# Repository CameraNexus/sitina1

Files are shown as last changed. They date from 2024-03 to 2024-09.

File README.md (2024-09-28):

# Sitina 1

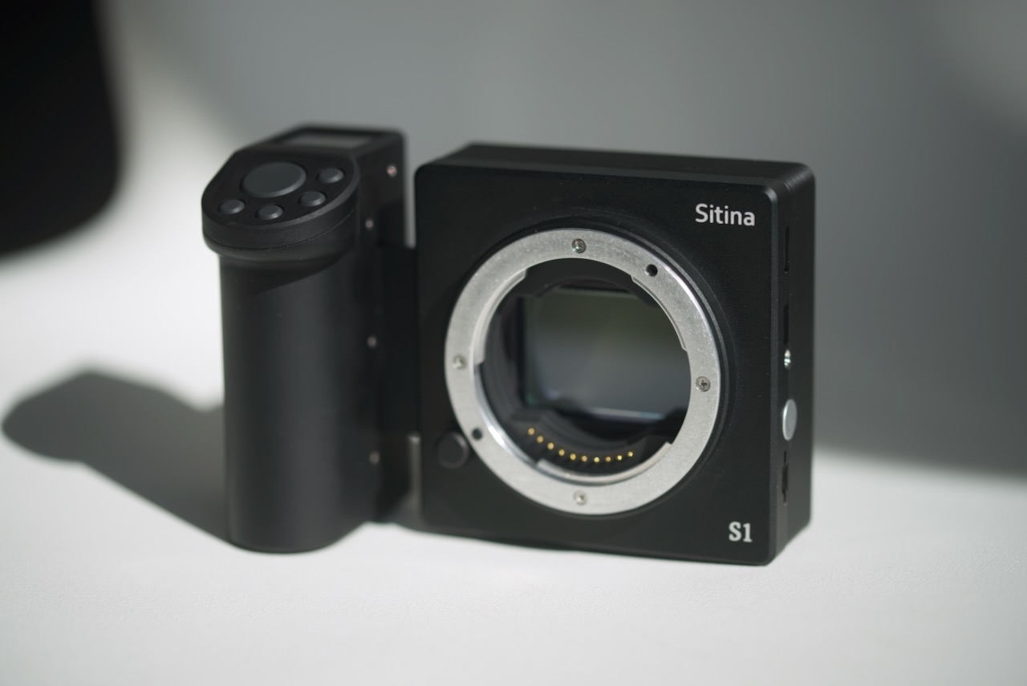
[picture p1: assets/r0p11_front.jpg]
front


Open-source 35mm full-frame (36mm x 24mm) CCD mirror-less interchangable lens camera (MILC). The original goal of this project was to create a digital camera back to convert SLR cameras to DSLR cameras, but has since changed to build a full MILC.

I have made 2 videos about this project:

- First video in 2023 (r0.6 hardware): [https://www.youtube.com/watch?v=Ma9FrN5COIo](https://www.youtube.com/watch?v=Ma9FrN5COIo)
- Second video in 2024 (r0.11-B hardware): [https://www.youtube.com/watch?v=OkfzjmY9cF8](https://www.youtube.com/watch?v=OkfzjmY9cF8)

Join discussion if you wish: [https://discord.gg/2zAJycbpU5](https://discord.gg/2zAJycbpU5)

## Specifications

The following are preliminary.

### Hardware

- SoC: Xilinx Zynq 7010 (2x667MHz Cortex-A9, 28K logic cells FPGA)
- RAM: 512MB 16-bit DDR3 SDRAM
- AFE: Analog Devices AD9990
- Sensor: Kodak/ONsemi KAI-11000/KAI-11002M/CM
- Screen: 3.4" 480x480 High-Brightness DPI IPS LCD
- External Ports:
  - SD slot (HS, 25MB/s)
  - USB Type-C (5V3A power supply)
  - Flash sync terminal

### Camera Features

The following are possible with hardware, but not necessarily supported by the current software.

- Sensor Type: 35mm Interline CCD sensor
- Sensor Size: 36.0 x 24.0 mm
- Effective Pixels: 10.7MP
- Lens Mount: Active E mount
- Still Resolutions:
  - 4008x2672 10.7MP 3:2
  - 3563x2672 9.5MP 4:3 1.08X crop
  - 2672x2672 7.1MP 1:1 1.27X crop
  - 2782x1856 5.2MP 3:2 APS-C crop
  - 2676x2007 5.4MP 4:3 APS-C crop
  - 2365x2365 5.6MP 1:1 APS-C crop
- Still Format:
  - DNG (10/12/14-bit lossless compressed RAW)
  - JPEG
- Readout Speed:
  - 4008x2672 up to 5FPS
  - 4008x480 at 28FPS (line skipping live view, rescaled to 480x320 for output)
- Video recording is not supported
- ISO: 100 to 6400 (color version)

## Status

Hardware R0.11 tested and working. The hardware still need a lot of work and is not ready yet.

## Sample Photos

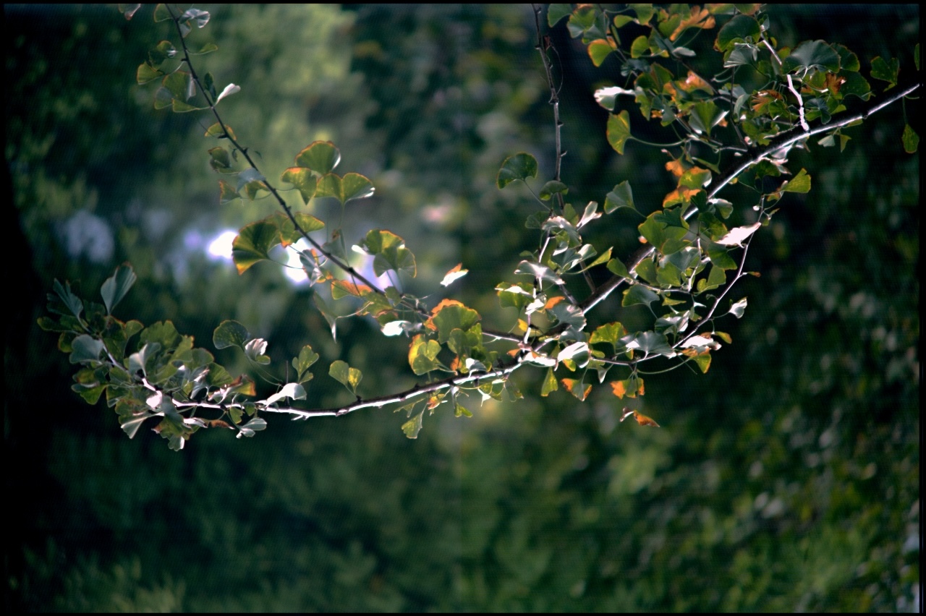
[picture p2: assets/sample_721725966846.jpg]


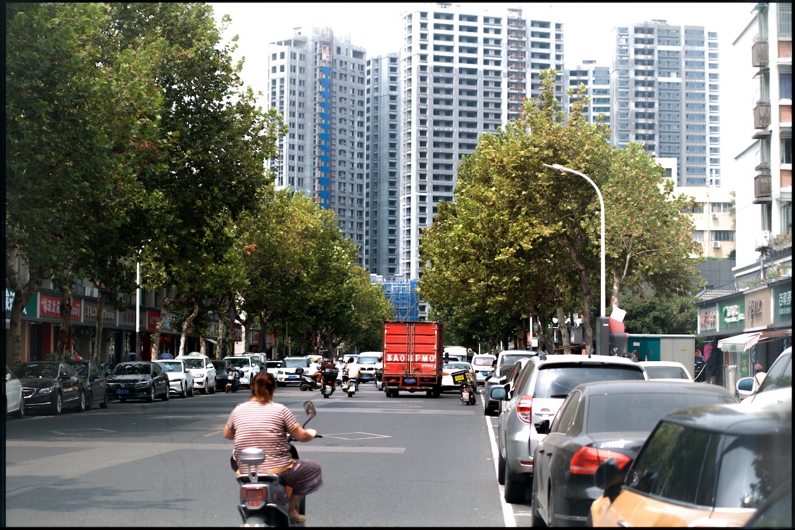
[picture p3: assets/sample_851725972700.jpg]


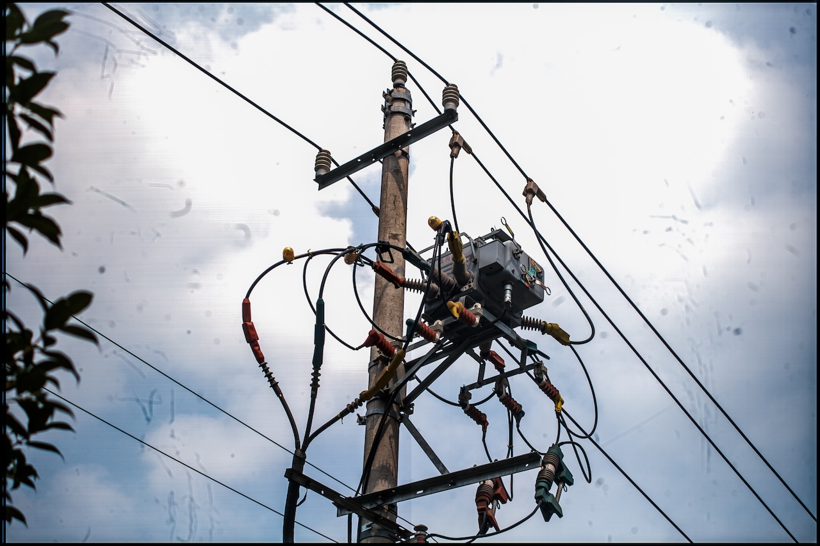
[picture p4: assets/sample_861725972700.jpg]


## Revision History

See [old-versions.md](/OLD_VERSIONS.md) for change logs, stories, and photos of old revisions!

## License

Unless otherwise stated, the hardware design is released under CERN-OHL-P, and the software/ firmware are released under MIT.

Most other 3D models are obtained from vendor website, refer to the corresponding vendor website for licensing details. They are provided for convience only.

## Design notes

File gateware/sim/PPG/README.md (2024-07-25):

# Programmable Pulse Generator (PPG) Demo

This folder contains a simple iVerilog testbench for the Adiabatic V-Driver-Driver.
The parameters are configured to the default value at 336MHz clock.

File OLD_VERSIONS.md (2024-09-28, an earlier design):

# Old Versions

Page for documenting old versions of this project. What happened, what worked, what didn't, etc.

### Rev 0.1 - Dec 2017

Initial revision. I had the idea of building a camera late 2016. The initial name of the project was called "F3 Digital" and it was based around the KAI-16000 sensor. As you might have guessed from the name F3 Digital, it's actually about turning the famous Nikon F3 film SLR camera into a DSLR. I was not prepared for the project tbh. There are too many challenges. Back in 2016 I actually had no ideas about how these things worked, I know basically nothing about circuit design, power electronics, programming, mechanical engineering or anything. Plus I didn't have a job back then I had no income to actually support me continue the project. So it basically went nowhere. I was quite frustrated back then to a point I put all my electronics DIY projects to a halt until I feel like I have learned enough things to restart.

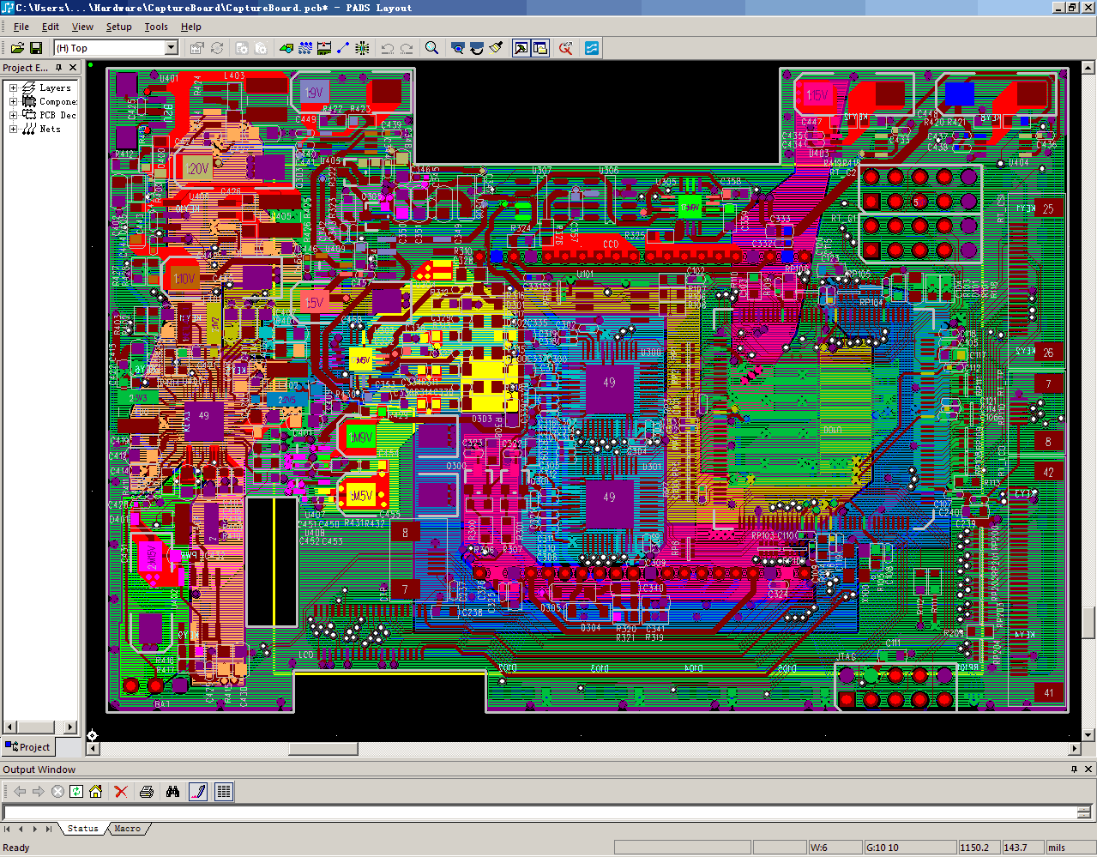
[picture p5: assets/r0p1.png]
r0p1


The half assembled prototype:

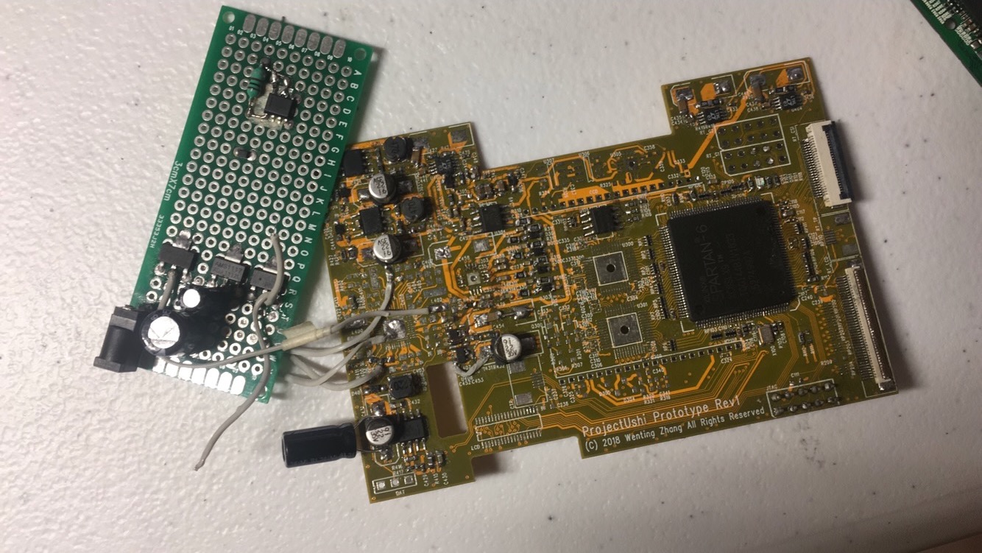
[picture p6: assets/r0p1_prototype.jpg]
r0p1_prototype


One major bug killed it is I made the footprint of the ADC mirrored.

Main hardware specs for this failed attempt:

- MCU: iMXRT1052
- FPGA: Spartan6 LX9
- CCD: KAI-16000
- ADC: AD9824

### Rev 0.2 - Mar 2021

Fast forward to 2021, one day when I was browsing eBay I saw someone selling bunch of KAI-11000 sensors at a very low price. I thought it's time to restart the project, even though I wasn't sure if I am ready or not. I was clearly not. I encountered three main challenges during the design process

- Integrating with the Nikon F3
- Driving the high capacitance clock lines
- Using the ADI AFE chip

Let's talk through them.

The first challenge is on the circuit design. CCD sensor signal lines are huge capacitive loads to the driver, yet they demand fast rise and fall times. The voltage also differs from different signals. For example, some are 5V swing around 3V, some are 9V swing around -4V. This would also require designing voltage shifters that not only change the amplitude, but also change the ground reference point. Then finally these circuits need power supplies to provide 10s of different voltage rails, sitting right next to sensitive analog circuits.

The second challenge is using the ADI AFE chip. The AFE chip integrates in a timing generator for the CCD, at first I thought it would be a good idea to just use that to generate all the timings for the CCD. This unfortunately turned out to be much harder than I anticipated. The timing generator is extremely flexible, supporting all sort of different things you may want to do with the CCD. Often there are multiple ways to program it to achieve the same output. The bad part? It has got hundreds of registers to control the behavior of the generator, and one has to be really familiar with its architecture and the intended output to be able to program it correctly. I didn't find any example code, I also had no prior experience with CCD so I wasn't even sure what kind of signal output I should be looking for. So this part ended up becoming challenging as well.

The third challenge is about integrating everything nicely with the F3 camera itself. However, attacking multiple challenges myself at the same time is just not a good strategy. I decided to focus on 1 and 2 first, trying to getting a working image capturing device before turning it into a camera.

This revision introduces the following major changes:

1. Use AD9990 for ADC/ AFE/ TG
2. Remove FPGA
3. Use KAI-11000 instead of KAI-16000
4. Redesigned H/V driver
5. Use 2.8" 640x480 LCD

This reversion continued the diversion between a sensor board and a processor board:

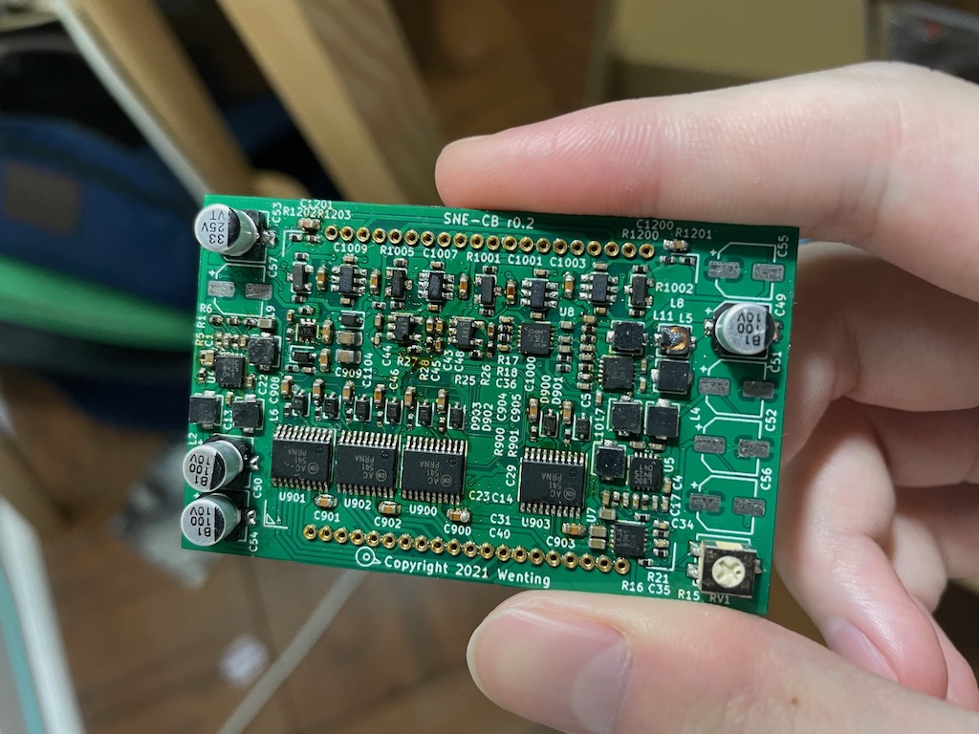
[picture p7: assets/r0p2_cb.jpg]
r0p2_cb


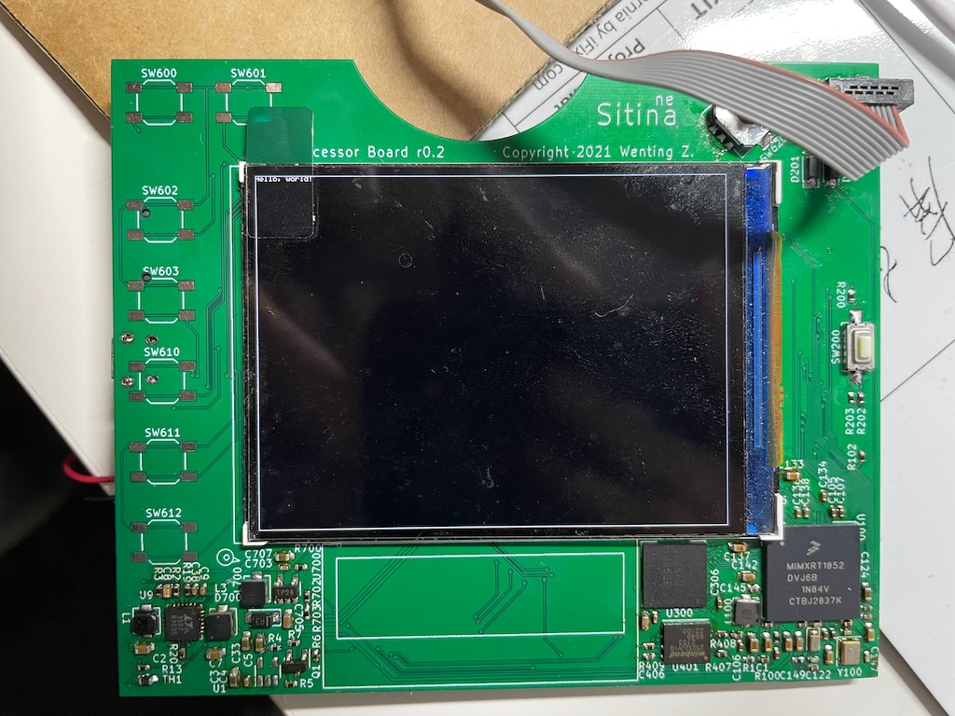
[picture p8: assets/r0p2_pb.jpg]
r0p2_pb


### Rev 0.3 - Dec 2021

This revision included minor bug fixes, but only to reveal bigger issues.

1. Fix AD9990 TEST pin connection
2. Minor bug fixes for driver
3. Fix RT1052 integrated DCDC connection

### Rev 0.4 - Mar 2022

With this revision I decided to make it more like a dev board rather than a camera board. This enables easy access to all the signals for hooking up an oscillioscope or logic analyzer.

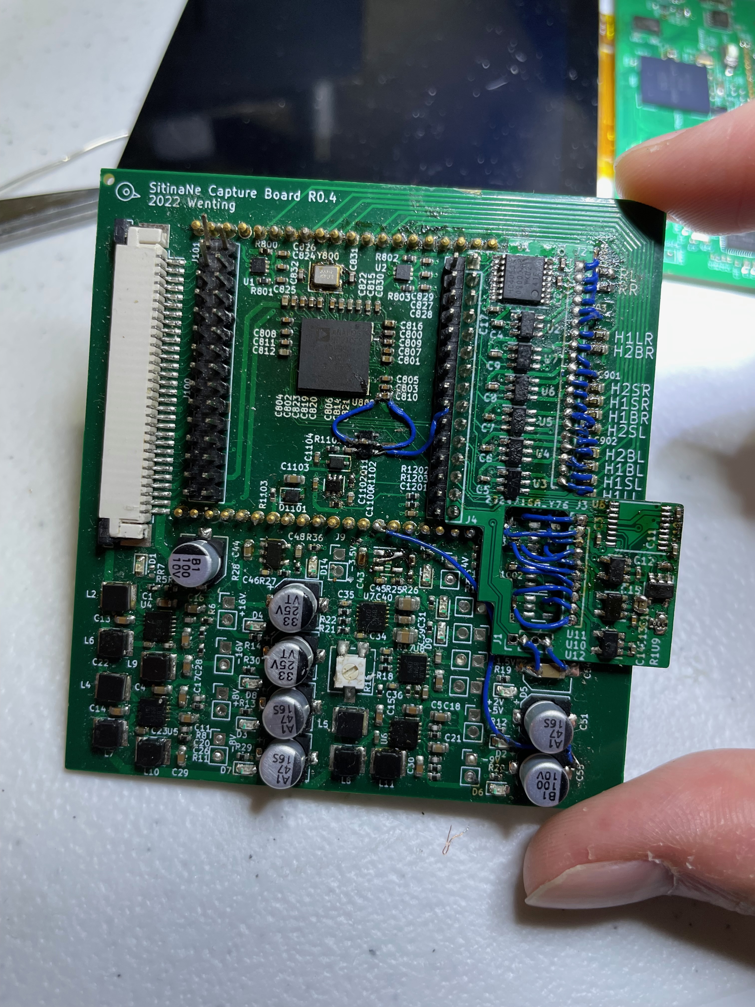
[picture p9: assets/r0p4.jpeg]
r0p4


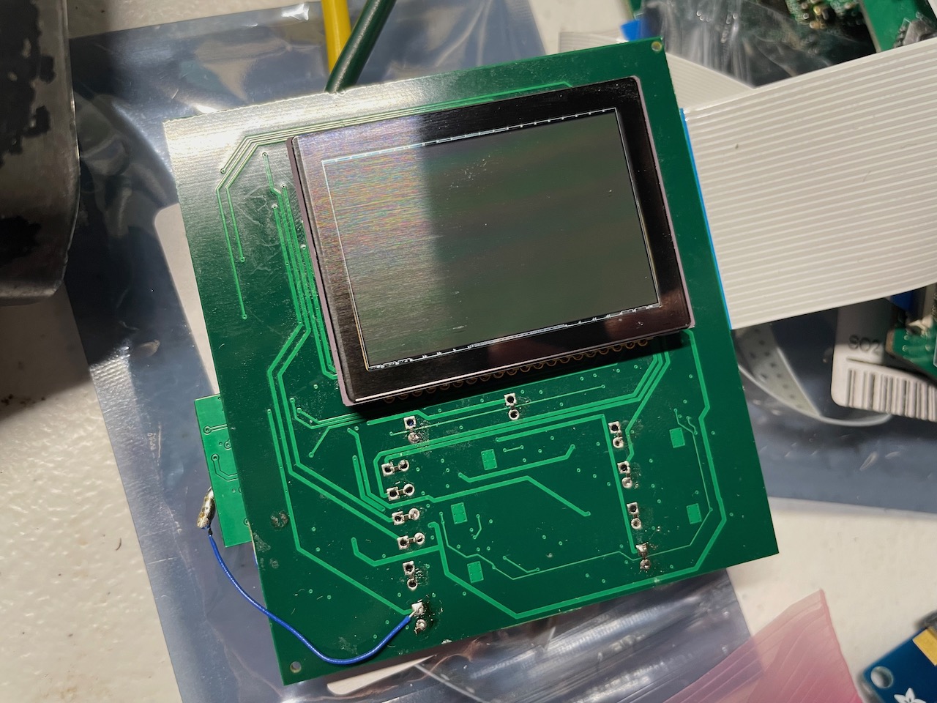
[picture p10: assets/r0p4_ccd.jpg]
r0p4_ccd


Notably this is the first time ever I got the CCD working: https://x.com/zephray_wenting/status/1519542527040401408.

### Rev 0.5 - Apr 2022

At this point I more or less have a somewhat working image capturing device, it's time to think about the F3 camera integration issue itself. This is not a single issue, but multiple issues:

1. because there is a thick protective glass in the front of the sensor, when the sensor is installed at the place where normally film goes to, the flange focal distance is increased. This changes the range of the distance which the lens can focus on. While this may not be a big deal, this problem doesn't have a clean solution.
2. the Nikon F3 exposes limited information to the external world. While it's internal electronics knows the ISO settings, the shutter speed dial, there is no easy way to access these. Disassembling the camera to add wires is possible but quite hard.  Otherwise I am stuck with the signal available to the official motor drive (which only has shutter release and shutter close).
3. How do I even attach this thing to the camera? The mechanism to hold the original film compartment door might simply not be strong enough the hold all the stuff I am adding. There is no place to put any reasonably sized battery (even though it might sounds like you can put a big battery in place of the film roll, don't forget there will be a film rewind fork sticking into the middle of the compartment. You don't want that to punch into the battery pack.) Making it like a grip and screw into the camera like the official motor drive was the only viable option I could come up with.

Eventually I think all of these are resolvable, it just takes time. So I started designing a basic chassis for it. My initial idea is to make it look like the Instax SQ1. Though the final design deviated away from it. But the idea of using a square LCD screen lived on.

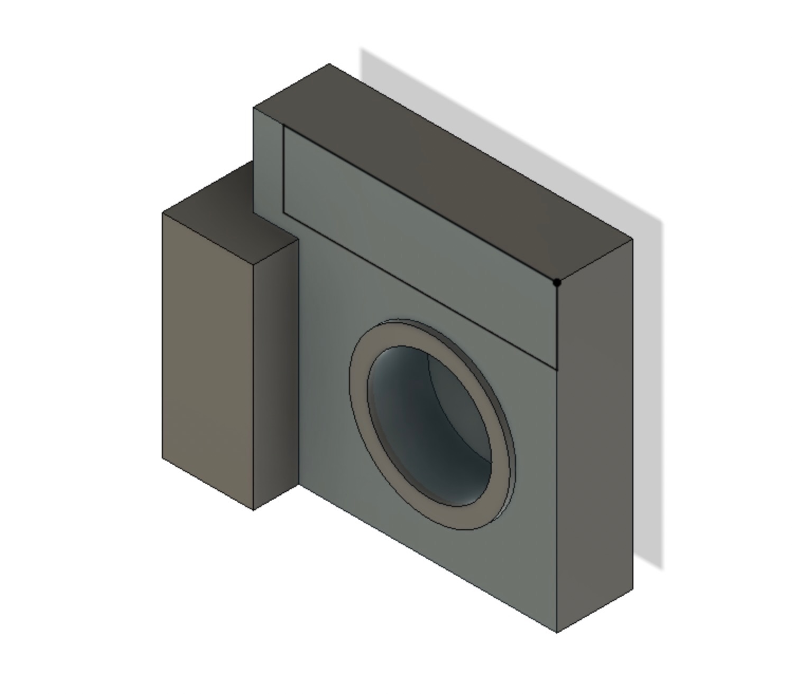
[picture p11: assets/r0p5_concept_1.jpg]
r0p5_concept


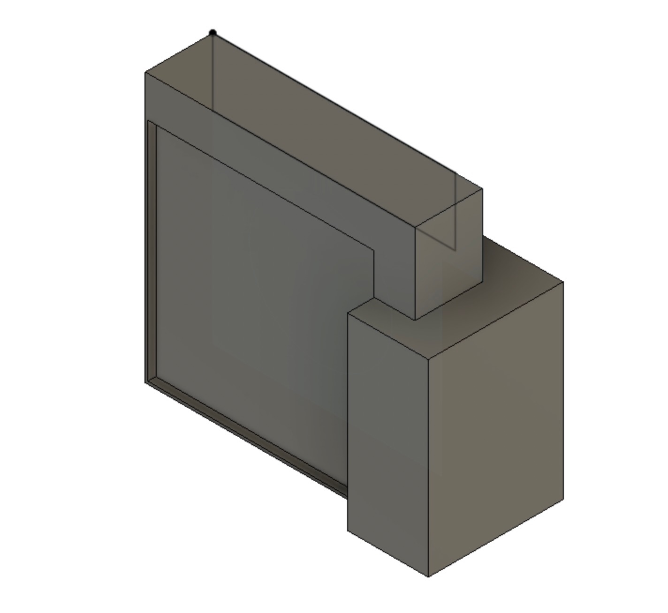
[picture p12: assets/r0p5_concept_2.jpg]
r0p5_concept


To help simplify the overall construction, the sensor board + processor 2-board design has been merged into a single-board design.

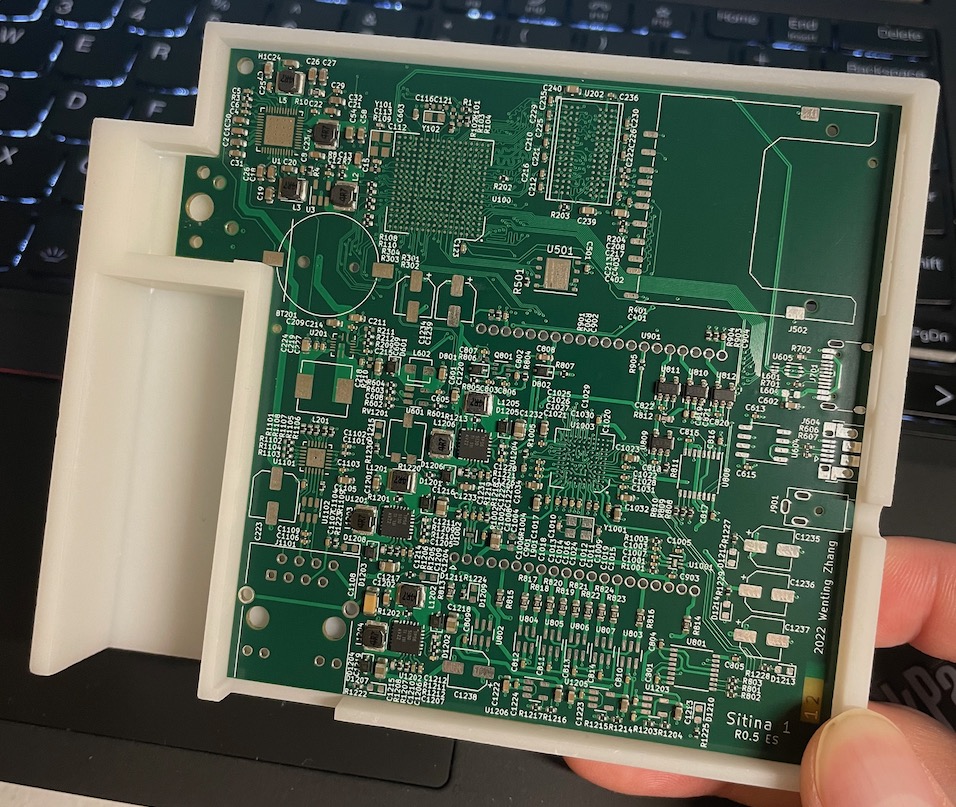
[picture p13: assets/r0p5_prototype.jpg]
r0p5_prototype


Main changes for this revision:

1. Switch from iMXRT1052 to iMX6ULL
2. Use 4" 720x720 LCD instead
3. Add 100M ethernet
4. Redesigned CCD power supply
5. Bug fixes for driver level-shifter

### Rev 0.6 - Mar 2023

Turns out I get more impatient as time goes by. At this point I have been quite frustrated and don't want to deal with this project anymore. I don't even want to deal with Linux. So I again switched to use a microcontroller. And made a video about whatever I was able to get out of it, hoping this would be the end of this project. I mean it's a crappy design and crappy camera, but it does take pictures.

Photos I took during debugging:

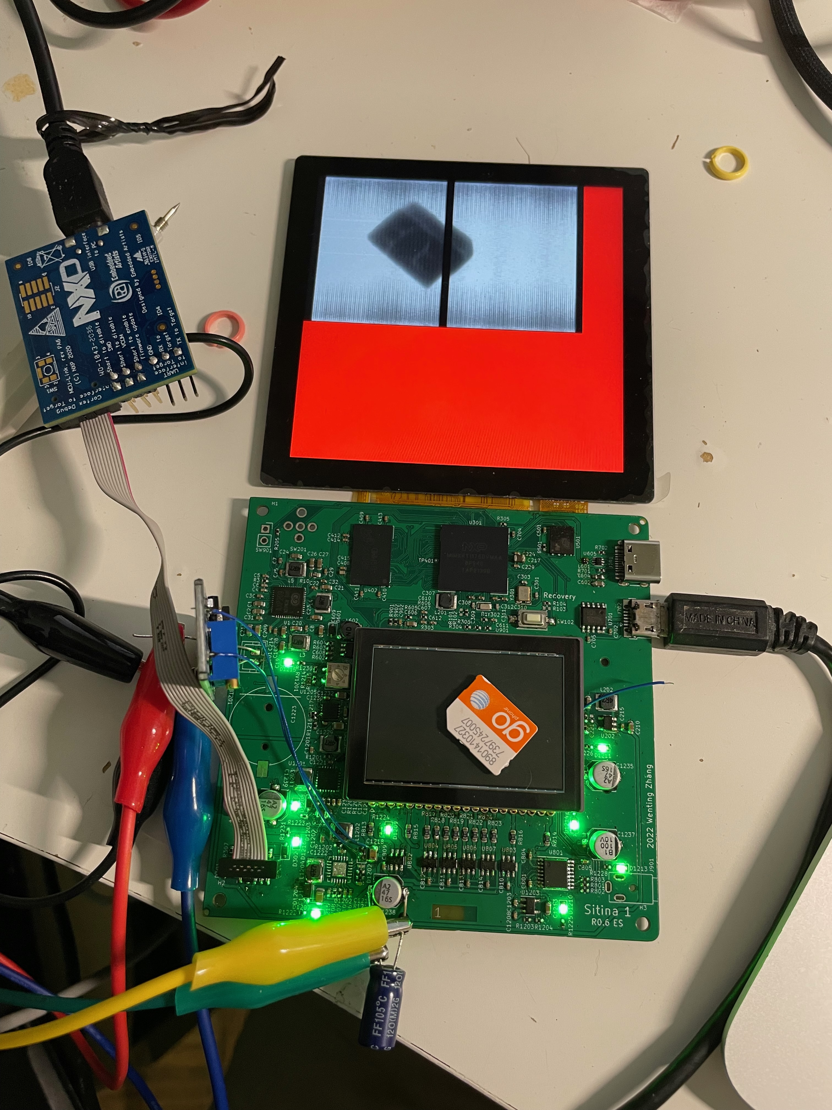
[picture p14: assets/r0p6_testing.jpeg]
r0p6_testing


Main changes:

1. Switch from iMX6ULL to iMXRT1176
2. Shrink board size
3. Removed builtin ethernet
4. CCD power supply bug fixes
5. Use MIPI DSI LCD instead of DPI

### Rev 0.7 - Aug 2023

Turned out the video went quite popular, getting 300K views on Bilibili and YouTube combined. To a point where don't want to claim that that questionable camera is the best I can do. So I continued.

I have several complains about the previous design:

- Bad image quality
- Problematic power supply design (noise issues, unable to supply current needed by the inefficient clock line driver)
- Problematic clock line driver (no slew control, ramp too slow, inefficient)
- Basically impossible to calibrate/ adjust the distance/ flatness between lens and sensor
- No builtin IR cut filter
- Too big
- Grip feels bad
- Full touchscreen operation is a bad idea and I knew it
- Only support fully manual lenses
- LCD is a bit hard to see outside

To address these issues I started designing the new version. I start with the basic idea of fastening both the sensor and the lens onto one metal part (instead of on 2 different plastic parts):

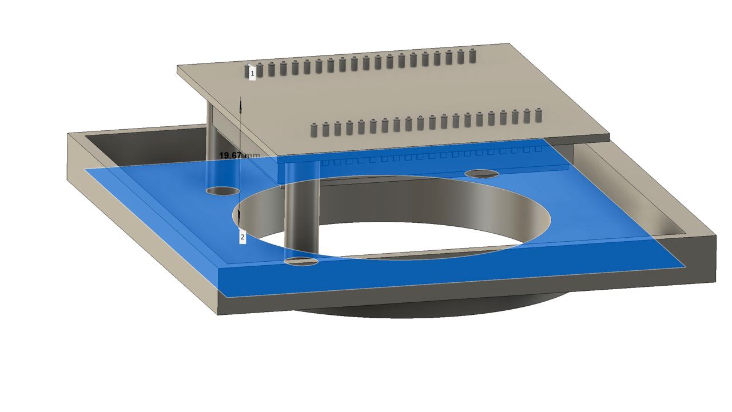
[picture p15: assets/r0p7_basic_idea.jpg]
r0p7_basic_idea


To help with miniaturize the camera, the screen size has shrunk from 4.0" down to 3.4". The new screen also has a 1000 nits maximum brightness, which should help with outdoor visibility a bit. This would also mean it's no longer possible to fit all components on a single PCB due to 2 reasons:

- I don't want to assert any external force on the sensor board, so all the IO ports and buttons should reside on another board
- It just doesn't fit

A common solution is to just stack more boards on the back side of the camera. Many industrial and consumer camera do this. I mean this is a pretty reasonable design. For me though, I want to try something different. To keep the camera thin, I want to stack more board in the front side, so I don't add additional thickness other than the bulky CCD sensor, the long pin + connector, and the thick high brightness backlight module. The only downside is that it would need to have a big cutout in the middle:

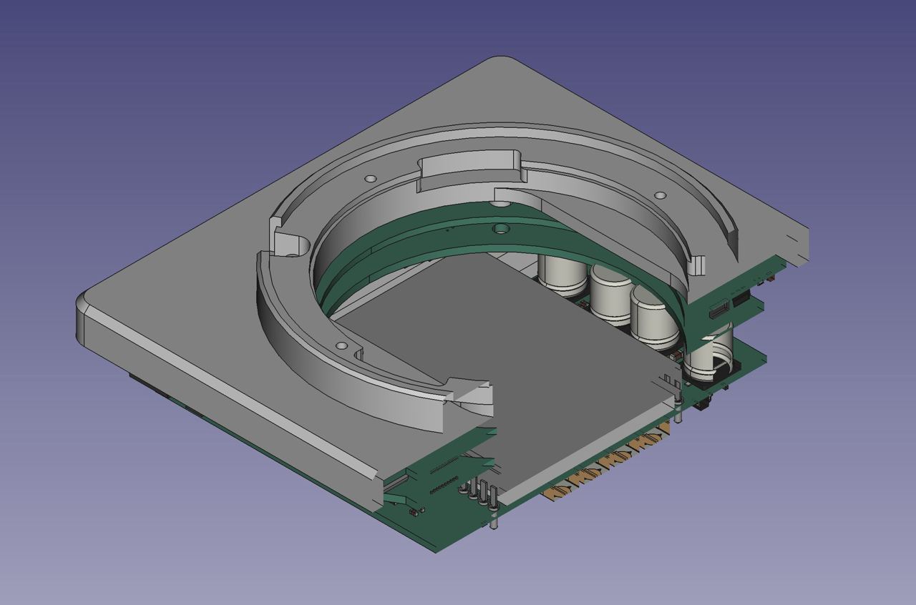
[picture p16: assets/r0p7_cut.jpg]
r0p7_cut


The rest of the design basically follows on. I again decided to focus on the image capturing part itself and worry about the grip later. I did model up the grip so I think it would fit. The final design looks like this (note how the grip is just a mock-up):

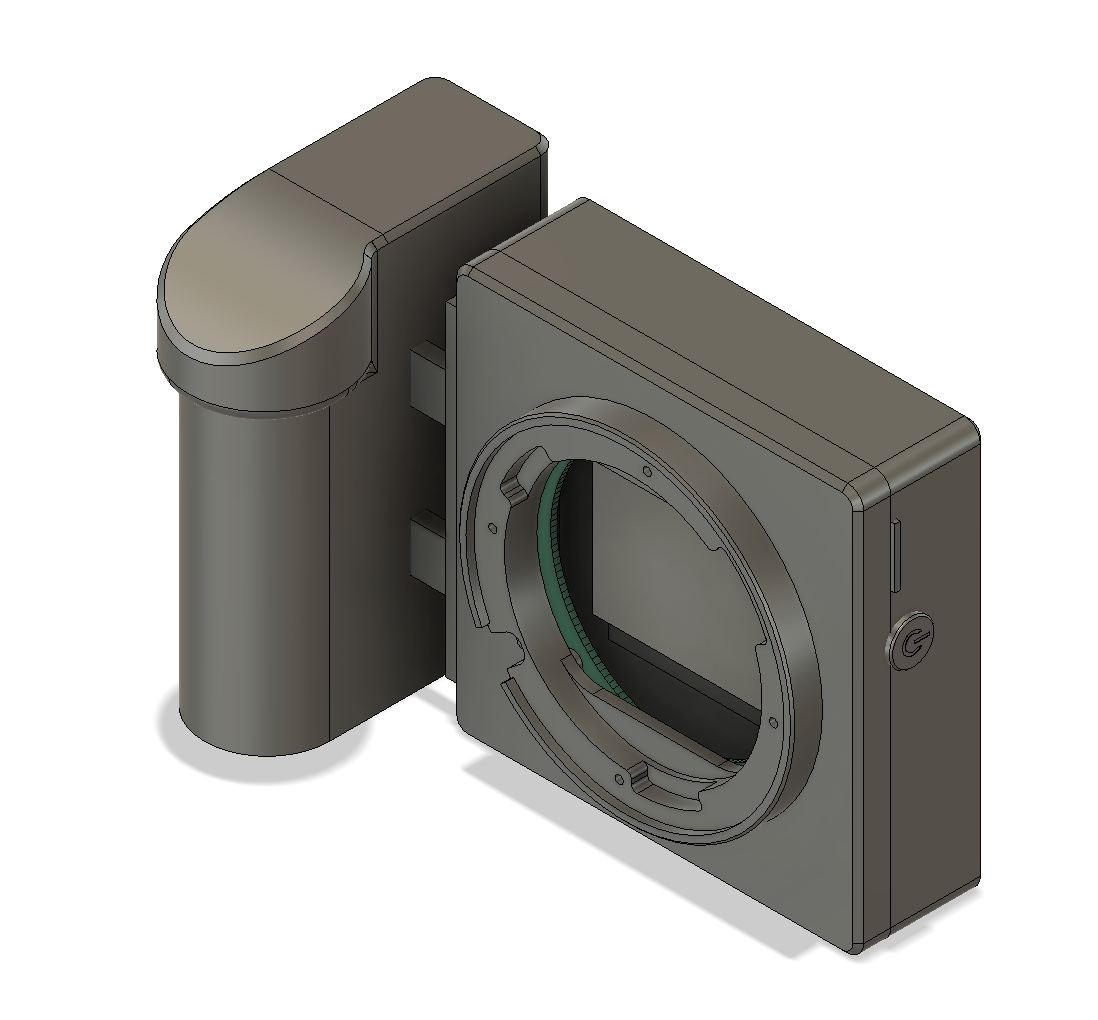
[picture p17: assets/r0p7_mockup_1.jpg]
r0p7_mockup_1


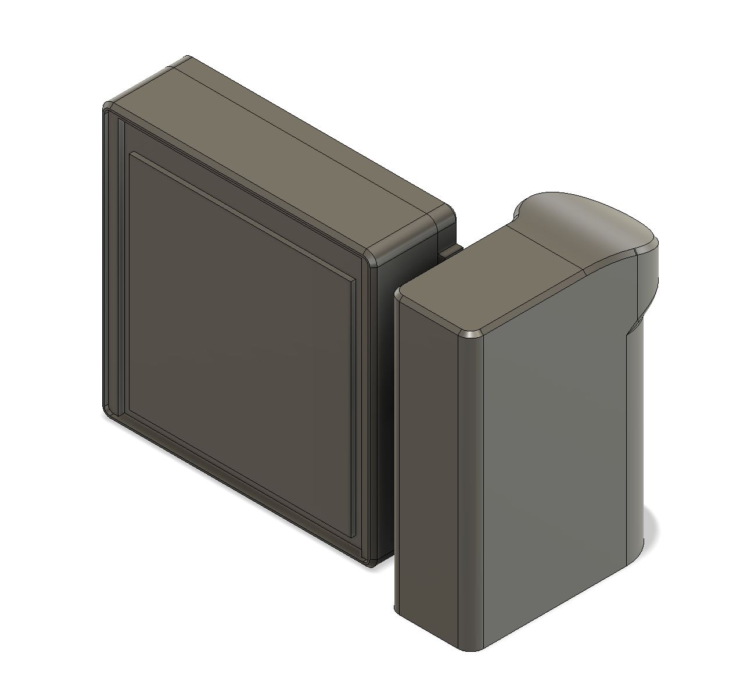
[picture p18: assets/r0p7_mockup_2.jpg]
r0p7_mockup_2


I went ahead and ordered the board and got it soldered and did some initial testing, and found some quite stupid issues preventing it from working.

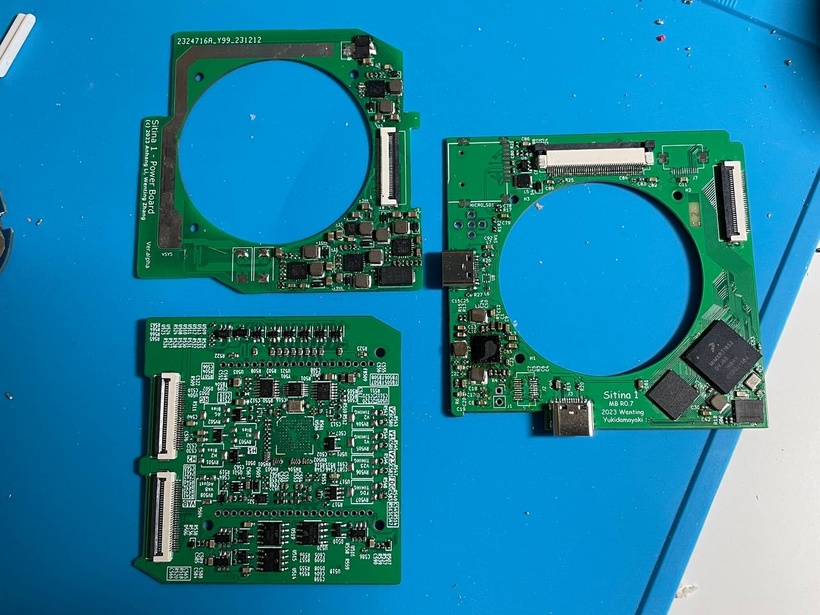
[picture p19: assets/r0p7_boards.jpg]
r0p7_boards


Main changes compared to r0p6:

1. Switch back to iMXRT1052
2. New board shape and overall design
3. Use 3.4" LCD instead of 4"
4. Split into 3 boards (MB, PB, SB)
5. Use individual MOSFETs for V-drivers

### Rev 0.8 - Jan 2024

My original plan back in December for r0.7 is to have the main body of the camera up and running and then worry about the grip later. That didn't quite work out: there were bugs in the boards, and I forgot to order some components, etc. Moreover, as I am designing the grip, it's becoming clear that I need to make the main body a few mm larger than previously designed in December (it's still going to be smaller than the previous revision though.) So I need to do a re-spin of everything anyway. As a result I have been focusing on getting the design right rather than trying to bring up the old prototypes.

I also spent some time to fix my broken 3D printer so it's up and running again (though with questionable printing quality) so I can print models of the grip to make sure the feeling isn't absolutely garbage:

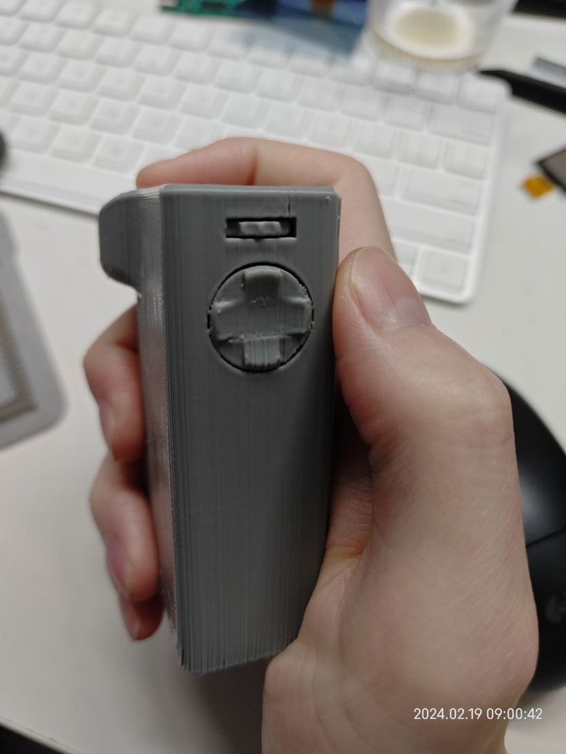
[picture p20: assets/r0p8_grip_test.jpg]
r0p8_grip_test


One major change I did is adding pogo pins for the lens. In the past the lens mount has been passive, meaning it only work with fully manual lenses. This obviously requires putting down these pins on to the board, so I am no longer able to keep the round cutout (which I like a lot):

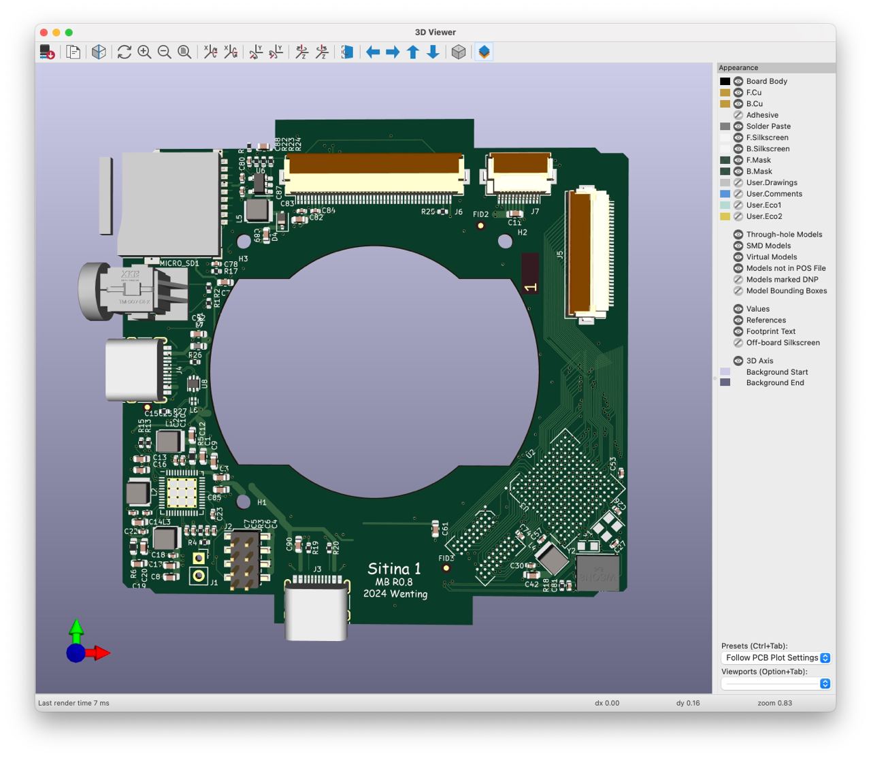
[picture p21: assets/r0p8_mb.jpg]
r0p8_mb


While the mainboard has a smaller cutout, the power board's cut out has been enlarged. This is accomodate the holder for the IR cut filter lens.

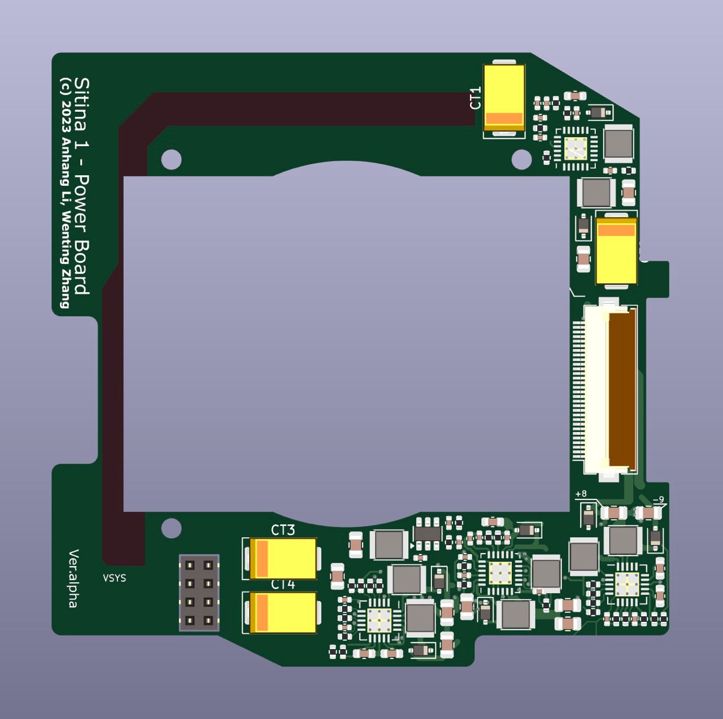
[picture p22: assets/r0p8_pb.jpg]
r0p8_pb


After printing a model of the full camera, this revision is almost ready to go:

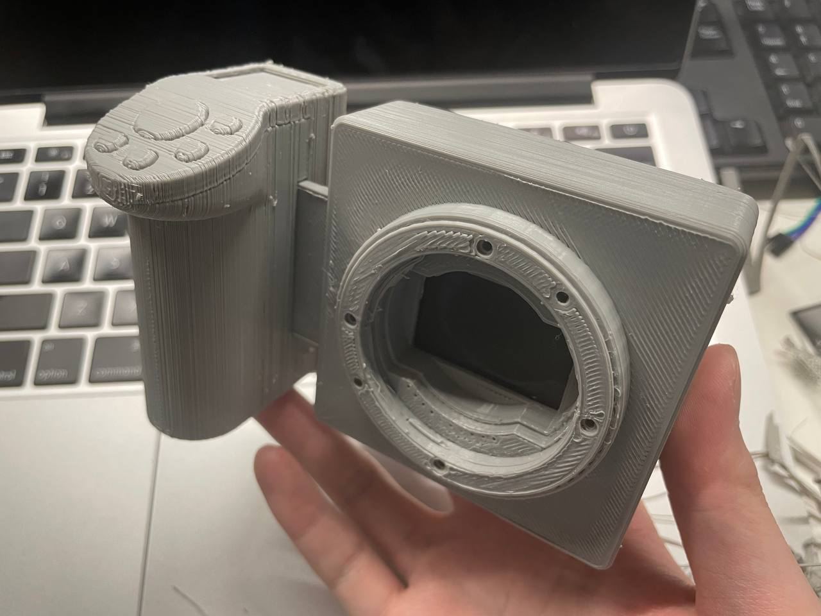
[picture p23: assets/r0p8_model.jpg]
r0p8_model


As said initially, the front piece would be metal. Other pieces can be SLA printed plastic. The following is a rendering of how it could look like:

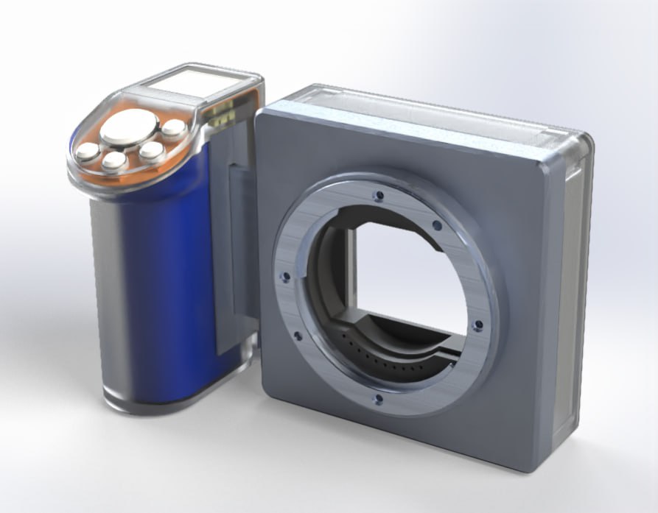
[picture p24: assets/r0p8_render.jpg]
r0p8_render


Main changes compared to r0p7:

1. Add fan speed control
2. Add active lens contact
3. Add flash sync port
4. Allow tripod mount
5. Revise power supply design
6. Change connector type

### Rev 0.9 - Mar 2024

Except r0p8 didn't happen! By the time I finished the r0p8 version, my friend Yukidamayaki-san (who have been helping out on designing the analog side of things) said he just learned a good technique for driving the CCD: resonant drivers. I am not going into details of it right now as it wouldn't get implemented until r0.11 but this drives a pretty significant architecture change of the camera design: use an FPGA (like back in r0.1!).

Every revision ever since 0.2 has an architecture like the following (r0.6's block diagram used here):

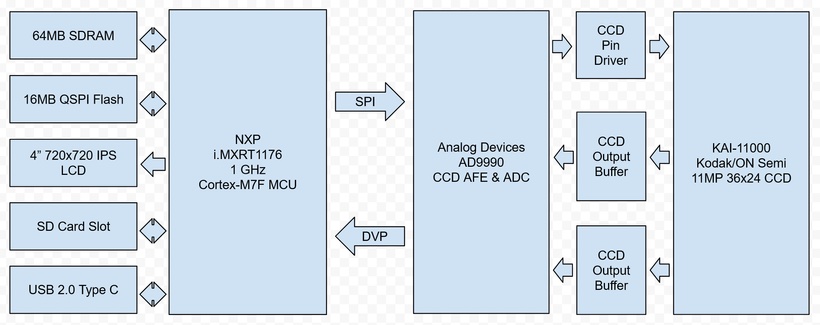
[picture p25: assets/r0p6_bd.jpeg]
r0p6_bd


On r0.9, the MCU has been replaced by an SoC FPGA (Xilinx Zynq 7010) + small MCU for house keeping tasks. With the new architecture, the FPGA generates all the timing necessary to drive the CCD, and the image processing can be potentially done in hardware (not saying that I will, but I could).

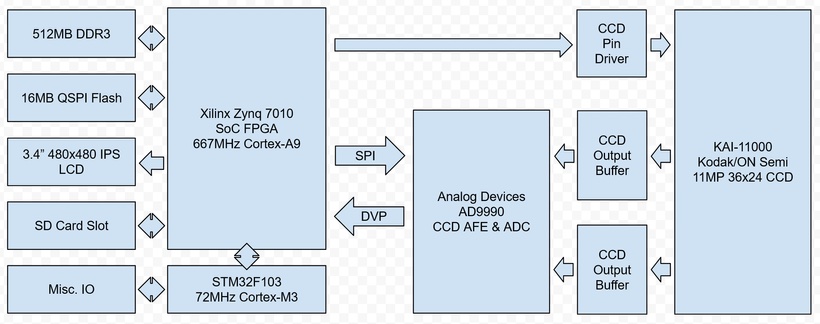
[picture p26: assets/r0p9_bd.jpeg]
r0p9_bd


I have been tempted to use FPGA in this project, but didn't find enough reason to do so back then. On the other hand I have pretty good reason against it: it just makes things complicated. But this time I have a real reason to do so: the resonant driver. This requires more timing control than what AD9990 can provide (or at least, what I would like to program). I have complained in the video that AD9990 is just hard to program for. To generate even more elaborate waveform, FPGA is the way to go. Instead of adding another glue FPGA into the equation, I decided to simply replace the original MCU with a Zynq device. Which should also provide better CPU performance as well. But, to not test too many new thing at one time, I am still using the traditional driver for this revision (R0.9). If everything goes well I can switch to the new driver in the future and compare how much it improves.

I have also got the entire thing assembled:

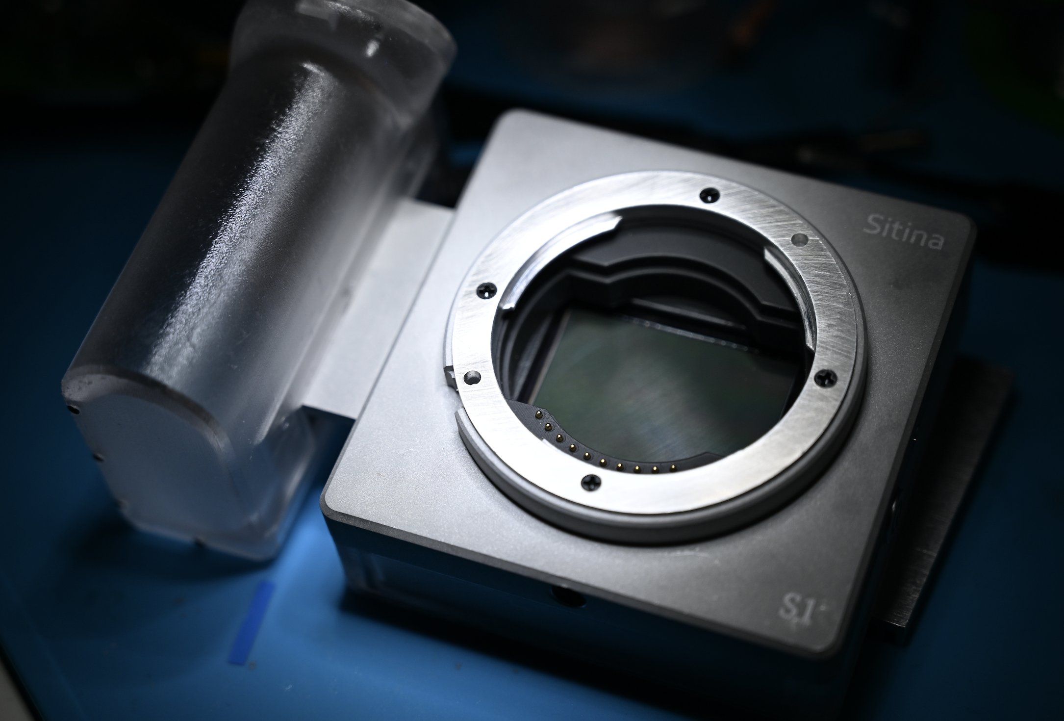
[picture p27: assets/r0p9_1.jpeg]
r0p9_1


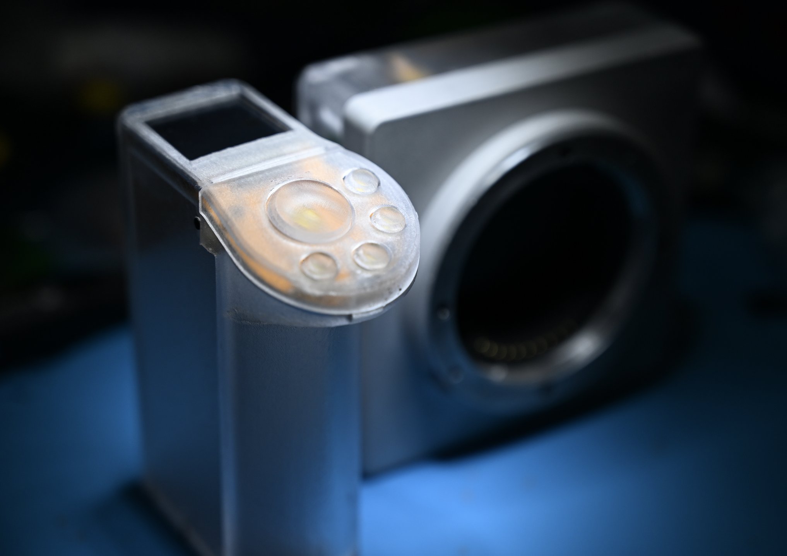
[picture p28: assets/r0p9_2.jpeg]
r0p9_2


r0p9_3

r0p9_4

r0p9_5

r0p9_6

r0p9_7

Most of the hardware works (Zynq, LCD, CCD driver, grip, etc.), but also due to the redesign, there are some serious bugs. So one more revision is needed before I switch to the new driver design.

Main changes compared to r0p8:

1. Combine MB and PB into IOB
2. Switch to Zynq 7010 (AGAIN?)
3. Use FPGA for timing gen
4. Remove USB data port

### Rev 0.10 - Jun 2024

As mentiond in r0.9 notes... this is a bug fix release. A new sensorboard release is also included with bug fixes, but it's not produced, instead, the older board is patched with bodge wires and reused. Some enclosure bug fix changes are included as well, so a new set of enclosure is also produced.

1. Fix LCD backlight range
2. Make the co-proc always ON
3. Add dedicated FPGA JTAG port
4. Add 2 additional buttons on the grip
5. Revise power supply to fix boot up problem
6. Fix grip button connection
7. Fix grip battery connector footprint and location
8. Use through-hole pogo-pins instead of SMT
9. Fix ribbon connector direction
10. Fix DDR power supply
11. New spring-loaded lens mount design

The color scheme has also been changed to black to better match with the lens:

r0p10

### Rev 0.11 - Aug 2024

Two sub-versions exists for this revision: R0.11 and R0.11-B. The main change for the non-B version is an experimental reactive V driver is implemented. The B version still uses the old V driver.

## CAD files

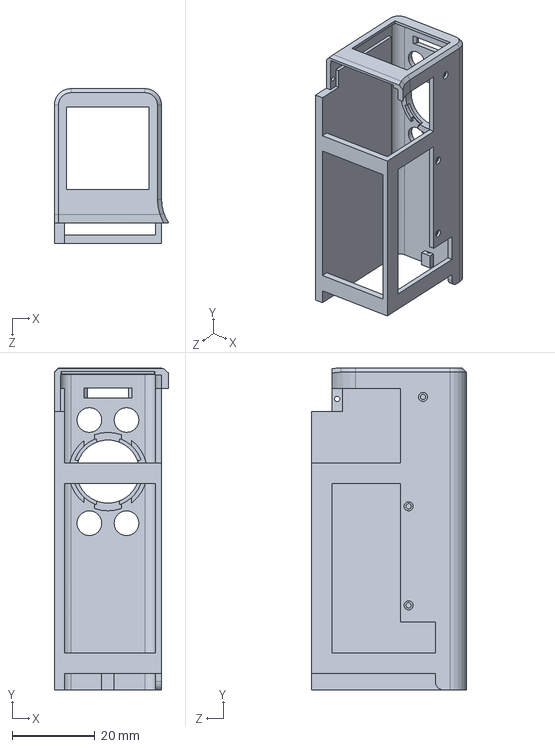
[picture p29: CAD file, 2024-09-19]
hardware/enclosure/gripupperback.SLDPRT
27.7 x 78.0 x 37.5 mm

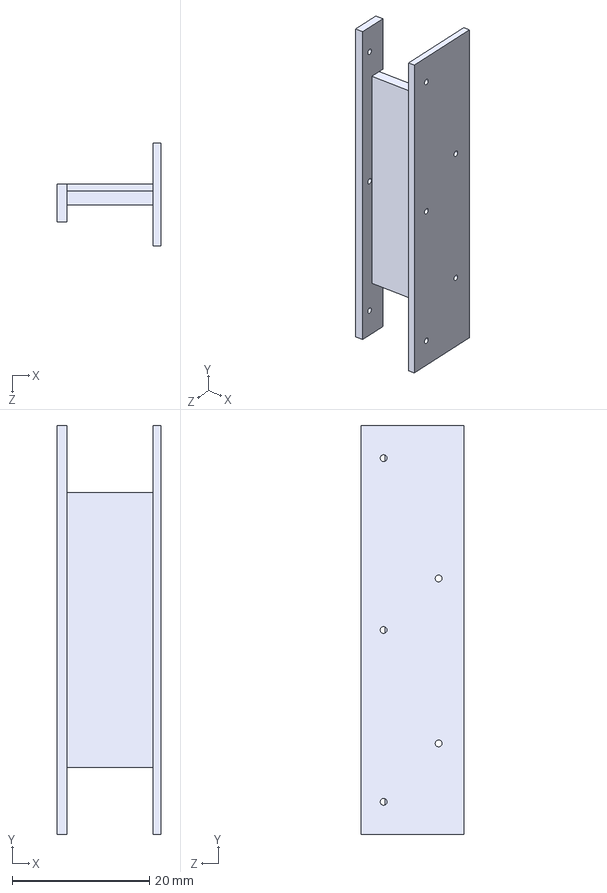
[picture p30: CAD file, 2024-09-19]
hardware/enclosure/gripbridge-lh.STEP
15.2 x 59.5 x 15.0 mm

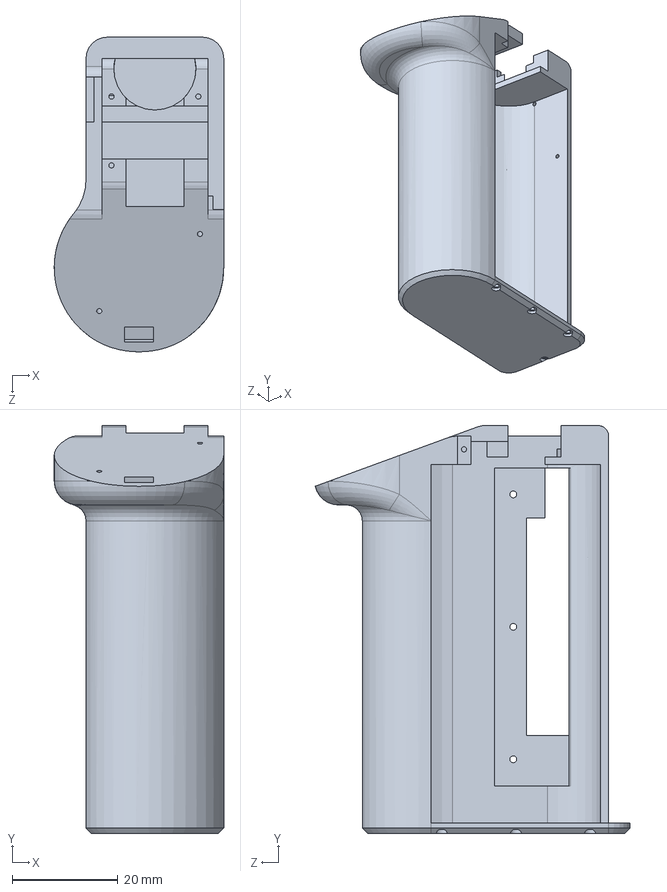
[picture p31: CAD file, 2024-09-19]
hardware/enclosure/griplower-lh.SLDPRT
32.0 x 77.0 x 59.4 mm

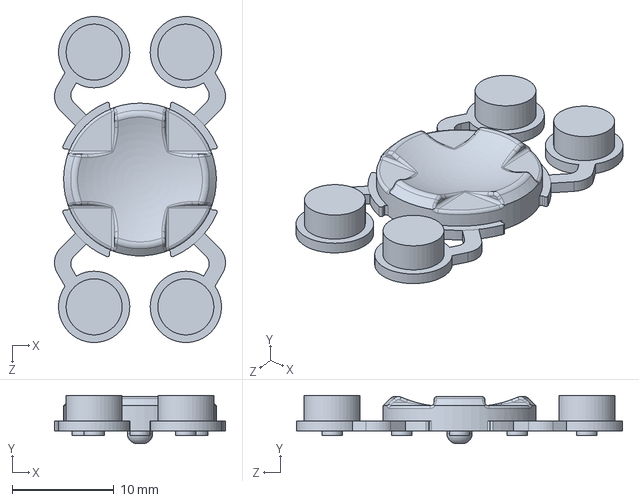
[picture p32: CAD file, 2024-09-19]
hardware/enclosure/dpad.SLDPRT
16.8 x 4.75 x 32.0 mm

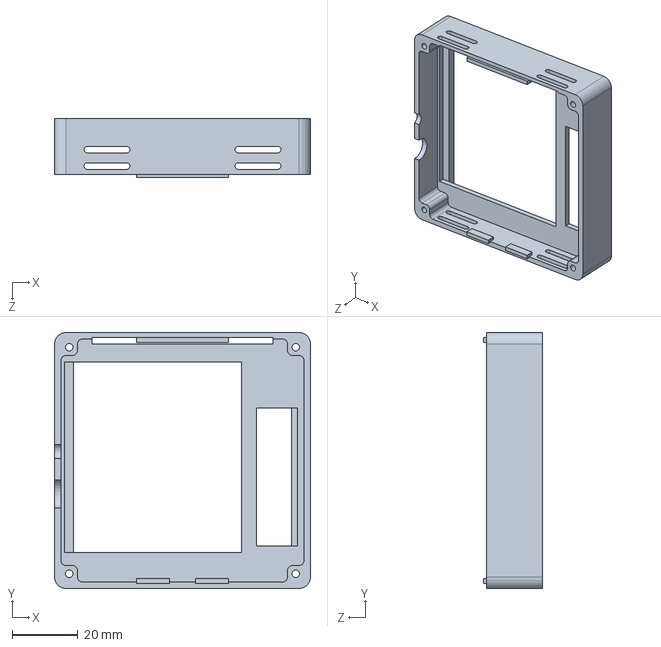
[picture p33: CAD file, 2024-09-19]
hardware/enclosure/back-lh.SLDPRT
78.0 x 78.0 x 18.0 mm

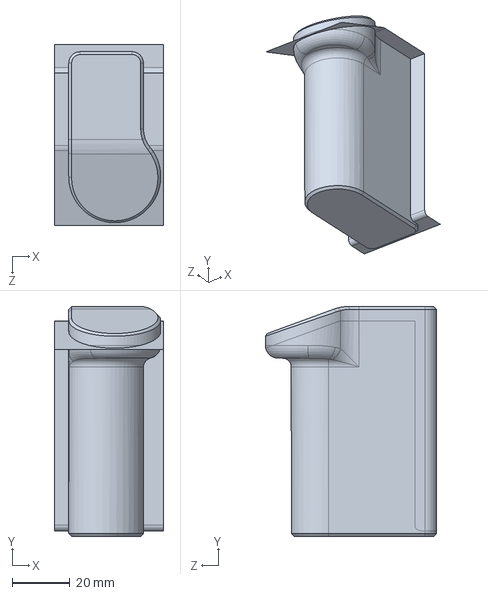
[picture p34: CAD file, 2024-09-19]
hardware/enclosure/gripbase.SLDPRT
38.0 x 80.0 x 63.0 mm

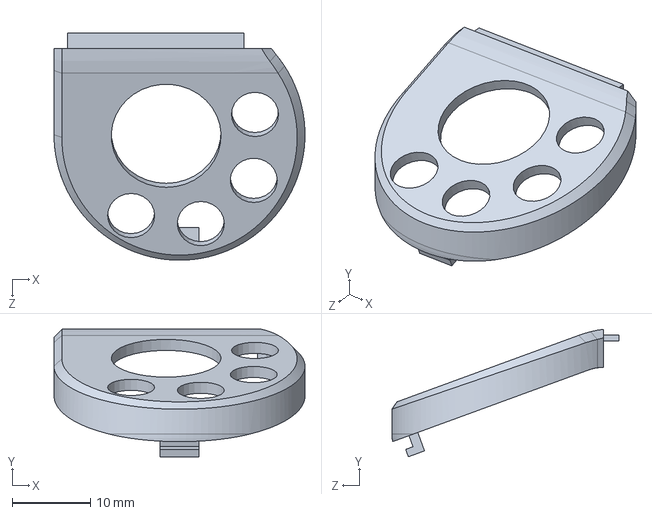
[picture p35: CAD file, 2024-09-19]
hardware/enclosure/gripupperfront.SLDPRT
32.0 x 16.3 x 29.0 mm

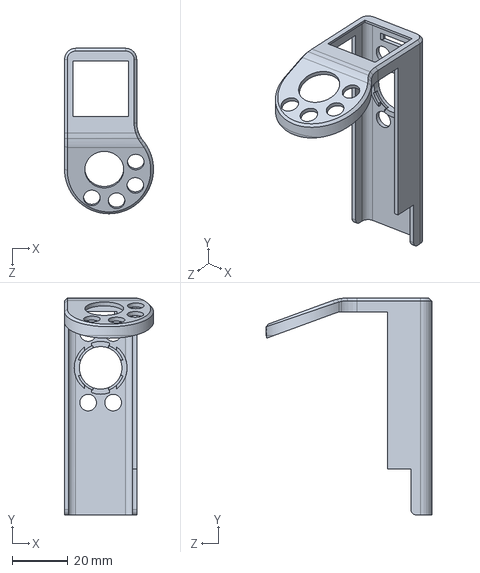
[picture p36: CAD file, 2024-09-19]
hardware/enclosure/gripupper.SLDPRT
32.0 x 78.0 x 59.5 mm

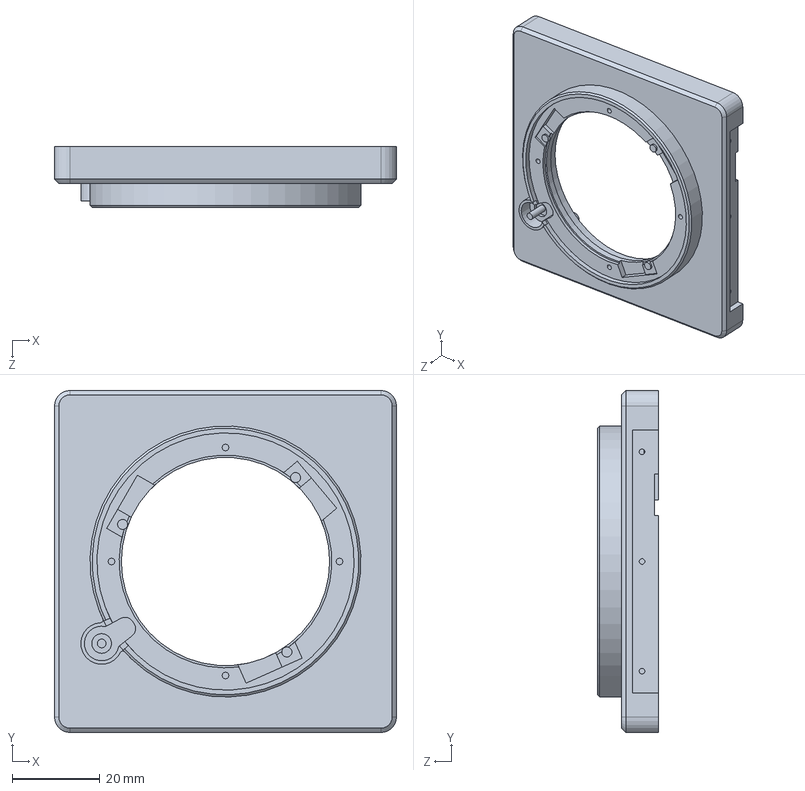
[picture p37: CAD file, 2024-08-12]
hardware/enclosure/front-lh.SLDPRT
78.0 x 78.0 x 14.0 mm

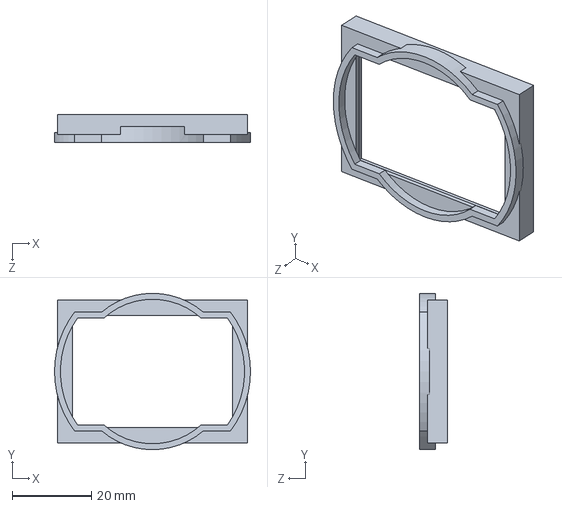
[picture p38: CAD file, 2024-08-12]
hardware/enclosure/filterholder.SLDPRT
49.4 x 39.4 x 7.00 mm

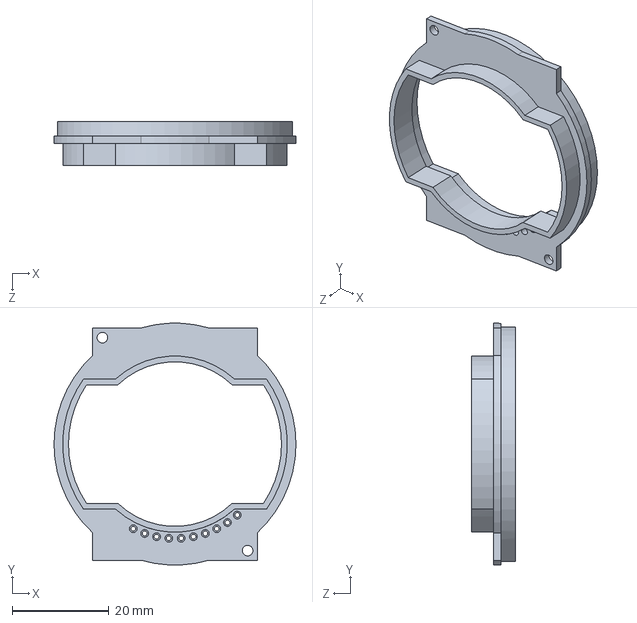
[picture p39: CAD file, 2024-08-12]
hardware/enclosure/sensorshade.SLDPRT
50.0 x 50.0 x 9.00 mm

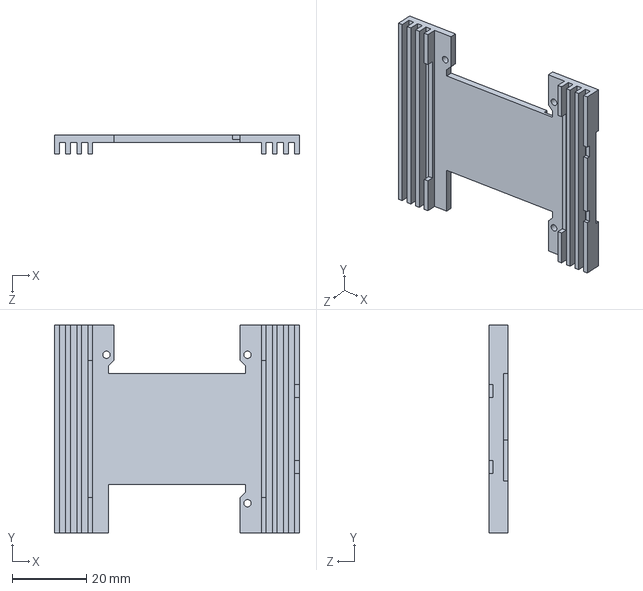
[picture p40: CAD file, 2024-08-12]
hardware/enclosure/heatsink.SLDPRT
66.0 x 56.0 x 5.00 mm

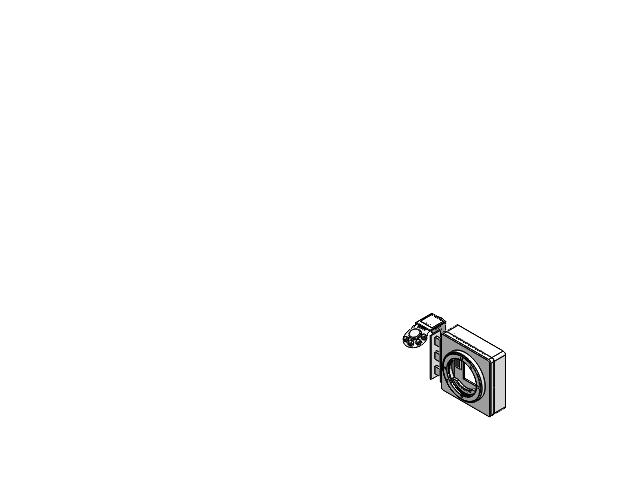
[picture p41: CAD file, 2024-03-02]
Hardware/enclosure/assembly.SLDASM
back
bayonet
front
gripbridge
shutter
dpad
siq-02fvs3.step
gripflex
shscreen
FH12-10S-0.5SH__X_8AÈ_X_97ª.stp
s2b-ph-sm4-tb.step

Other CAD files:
hardware/enclosure/gripupperback-lh.SLDPRT
hardware/enclosure/back.SLDPRT
hardware/enclosure/griplower.SLDPRT
hardware/enclosure/gripupperfront-lh.SLDPRT
hardware/enclosure/front.SLDPRT
hardware/enclosure/YZP0652-15072-01.SLDPRT
hardware/enclosure/ad01703hx04ab00.SLDPRT
hardware/enclosure/addbtn.SLDPRT
hardware/enclosure/bayonet.SLDPRT
hardware/enclosure/front-lh.DXF
hardware/enclosure/front-lh.SLDDRW
hardware/enclosure/gripbridge-lh.SLDDRW
hardware/enclosure/gripbridge-lh.SLDPRT
hardware/enclosure/gripbridge.SLDPRT
hardware/enclosure/gripflex.SLDPRT
hardware/enclosure/icr18650.SLDPRT
hardware/enclosure/lockpin.SLDPRT
hardware/enclosure/m2x10.SLDPRT
hardware/enclosure/m2x12.SLDPRT
hardware/enclosure/m2x4.SLDPRT
hardware/enclosure/m2x9.SLDPRT
hardware/enclosure/screencover.SLDPRT
hardware/enclosure/shscreen.SLDPRT
hardware/enclosure/shutter.SLDPRT
hardware/enclosure/tensionspring.SLDPRT
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

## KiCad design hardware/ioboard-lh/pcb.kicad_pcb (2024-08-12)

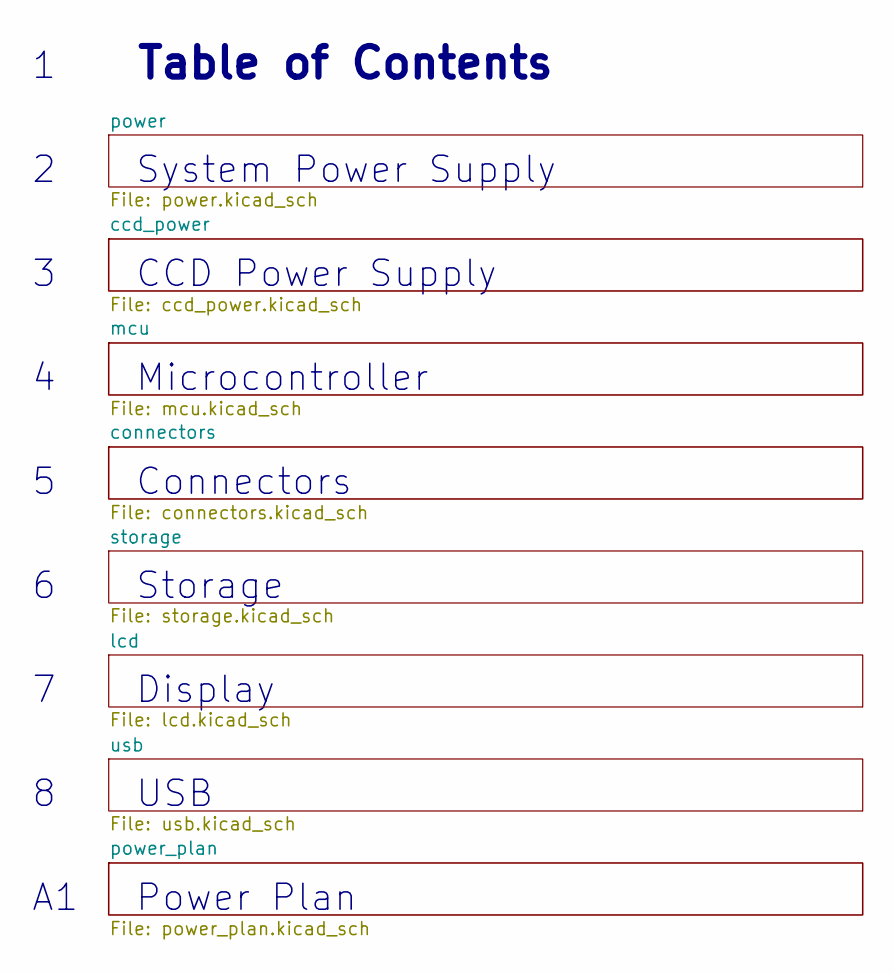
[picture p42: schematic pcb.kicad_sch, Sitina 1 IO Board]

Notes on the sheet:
CCD Power Supply
Power Plan
System Power Supply
Table of Contents
USB
Microcontroller
Display
Storage
Connectors

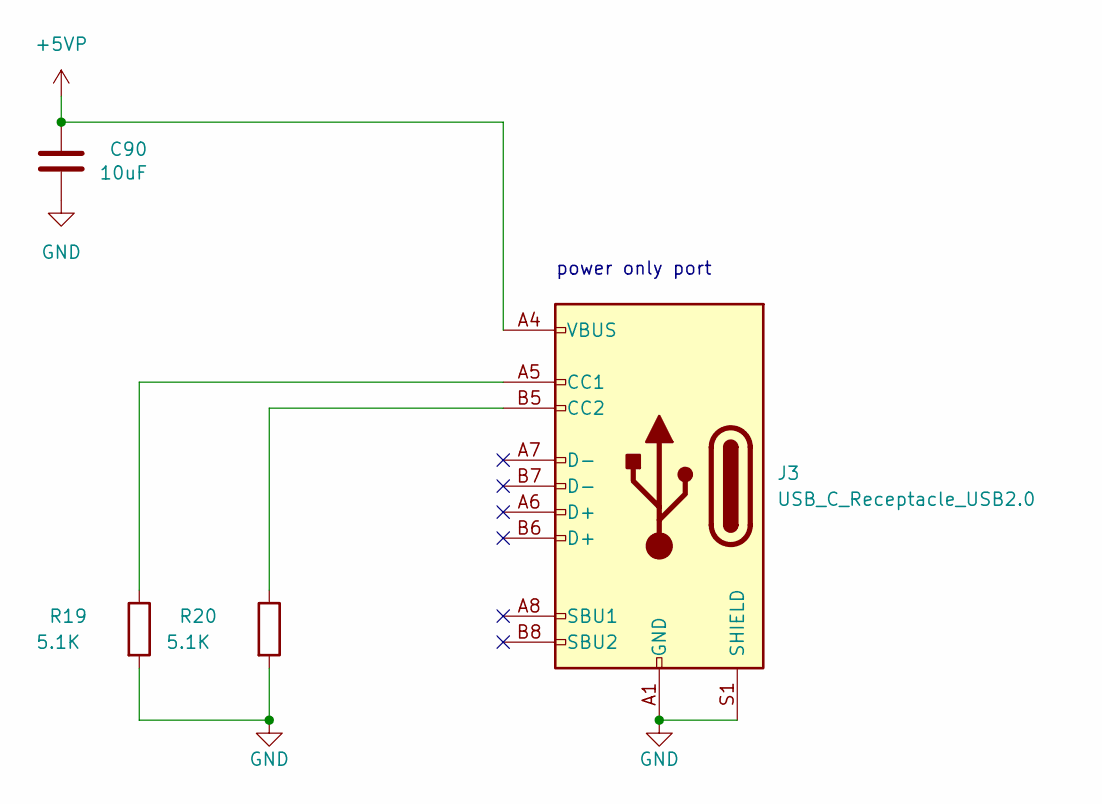
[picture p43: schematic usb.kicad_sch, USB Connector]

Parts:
C90: 10uF; C_0603_1608Metric
J3: USB_C_Receptacle_USB2.0; USB_C_Receptacle_HRO_TYPE-C-31-M-12
R19, R20: 5.1K; R_0402_1005Metric

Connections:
+5VP: C90.1, J3.A4 (VBUS), J3.A9 (VBUS), J3.B4 (VBUS), J3.B9 (VBUS); also elsewhere on the board
GND: C90.2, J3.A1 (GND), J3.A12 (GND), J3.B1 (GND), J3.B12 (GND), J3.S1 (SHIELD), R19.2, R20.2; also elsewhere on the board
unnamed: J3.A5 (CC1), R19.1
unnamed: J3.B5 (CC2), R20.1

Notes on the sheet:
power only port

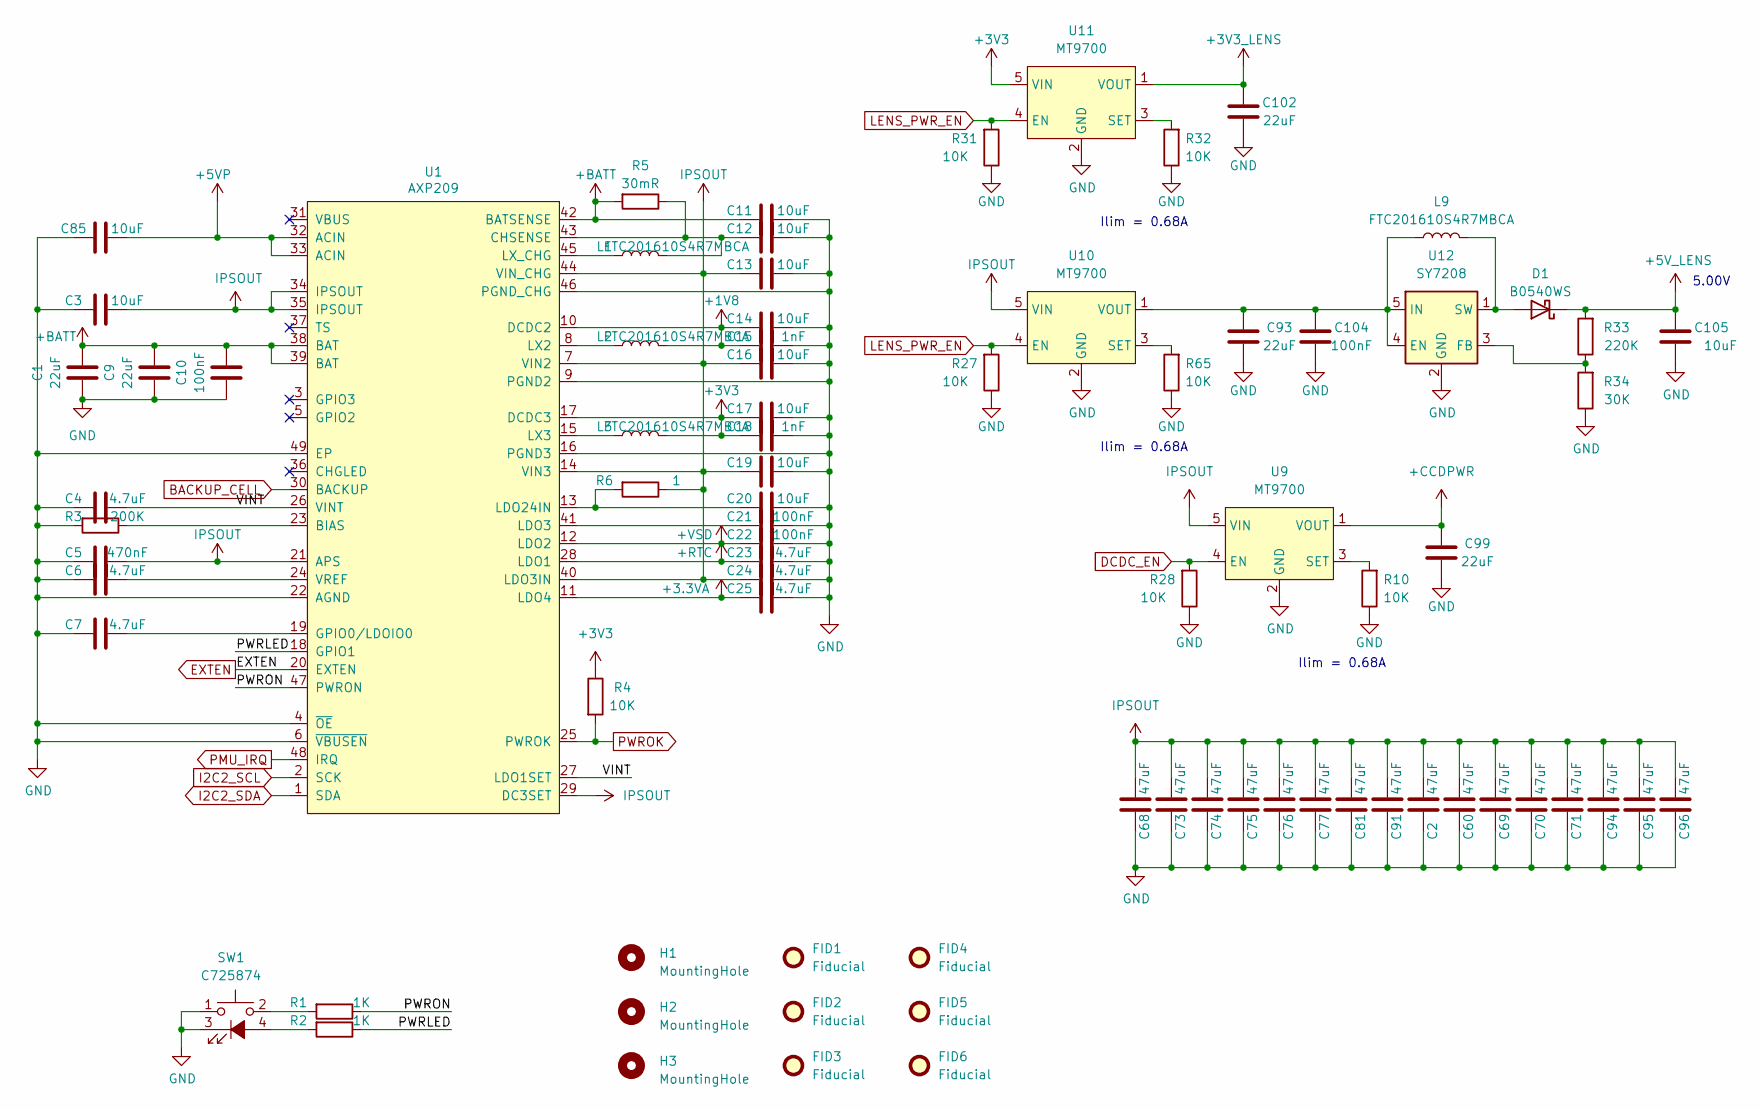
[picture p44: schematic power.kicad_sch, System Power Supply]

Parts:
C1, C9, C93, C99, C102: 22uF; C_0603_1608Metric
C2, C60, C68, C69, C70, C71, C73, C74, C75, C76, C77, C81, C91, C94, C95, C96: 47uF; C_0805_2012Metric
C3, C11, C12, C13, C14, C16, C17, C19, C20, C85, C105: 10uF; C_0603_1608Metric
C4, C6, C7, C23, C24, C25: 4.7uF; C_0402_1005Metric
C5: 470nF; C_0402_1005Metric
C10, C21, C22, C104: 100nF; C_0402_1005Metric
C15, C18: 1nF; C_0402_1005Metric
D1: B0540WS; D_SOD-323
FID1, FID2, FID3, FID4, FID5, FID6: Fiducial; Fiducial_0.75mm_Mask1.5mm
H1, H2, H3: MountingHole; MountingHole_2.2mm_M2_DIN965
L1, L2, L3, L9: FTC201610S4R7MBCA; L_Murata_DFE201610P
R1, R2: 1K; R_0402_1005Metric
R3: 200K; R_0402_1005Metric
R4, R10, R27, R28, R31, R32, R65: 10K; R_0402_1005Metric
R5: 30mR; R_0603_1608Metric
R6: 1; R_0603_1608Metric
R33: 220K; R_0402_1005Metric
R34: 30K; R_0402_1005Metric
SW1: C725874; TM-007-D1-X
U1: AXP209; QFN-48-1EP_6x6mm_P0.4mm_EP4.3x4.3mm_ThermalVias
U9, U10, U11: MT9700; SOT-23-5
U12: SY7208; SOT-23-6

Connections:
+1V8: C14.2, C15.2, L2.2, U1.10 (DCDC2); also elsewhere on the board
+3.3VA: C25.2, U1.11 (LDO4); also elsewhere on the board
+3V3: C17.2, C18.2, L3.2, R4.1, U1.17 (DCDC3), U11.5 (VIN); also elsewhere on the board
+3V3_LENS: C102.1, U11.1 (VOUT); also elsewhere on the board
+5VP: C85.1, U1.32 (ACIN), U1.33 (ACIN); also elsewhere on the board
+5V_LENS: C105.2, D1.1 (K), R33.2; also elsewhere on the board
+BATT: C1.1, C9.1, C10.1, C11.2, R5.2, U1.38 (BAT), U1.39 (BAT), U1.42 (BATSENSE); also elsewhere on the board
+CCDPWR: C99.1, U9.1 (VOUT); also elsewhere on the board
+RTC: C23.2, U1.28 (LDO1); also elsewhere on the board
+VSD: C22.2, U1.12 (LDO2); also elsewhere on the board
/power/PWRLED: R2.1, U1.18 (GPIO1)
/power/PWRON: R1.1, U1.47 (PWRON)
/power/VINT: C4.1, U1.26 (VINT), U1.27 (LDO1SET)
BACKUP_CELL: U1.30 (BACKUP)
DCDC_EN: R28.2, U9.4 (EN); also elsewhere on the board
EXTEN: U1.20 (EXTEN); also elsewhere on the board
GND: C1.2, C2.2, C3.2, C4.2, C5.2, C6.2, C7.2, C9.2, C10.2, C11.1, C12.1, C13.1, C14.1, C15.1, C16.1, C17.1, C18.1, C19.1, C20.1, C21.1, C22.1, C23.1, C24.1, C25.1, C60.2, C68.2, C69.2, C70.2, C71.2, C73.2, C74.2, C75.2, C76.2, C77.2, C81.2, C85.2, C91.2, C93.2, C94.2, C95.2, C96.2, C99.2, C102.2, C104.1, C105.1, R3.2, R10.1, R27.1, R28.1, R31.1, R32.1, R34.1, R65.1, SW1.1, SW1.3 (K), U1.4 (~OE), U1.6 (~VBUSEN), U1.9 (PGND2), U1.16 (PGND3), U1.22 (AGND), U1.46 (PGND_CHG), U1.49 (EP), U9.2 (GND), U10.2 (GND), U11.2 (GND), U12.2 (GND); also elsewhere on the board
I2C2_SCL: U1.2 (SCK); also elsewhere on the board
I2C2_SDA: U1.1 (SDA); also elsewhere on the board
IPSOUT: C2.1, C3.1, C5.1, C13.2, C16.2, C19.2, C24.2, C60.1, C68.1, C69.1, C70.1, C71.1, C73.1, C74.1, C75.1, C76.1, C77.1, C81.1, C91.1, C94.1, C95.1, C96.1, R6.1, U1.7 (VIN2), U1.14 (VIN3), U1.21 (APS), U1.29 (DC3SET), U1.34 (IPSOUT), U1.35 (IPSOUT), U1.40 (LDO3IN), U1.44 (VIN_CHG), U9.5 (VIN), U10.5 (VIN); also elsewhere on the board
LENS_PWR_EN: R27.2, R31.2, U10.4 (EN), U11.4 (EN); also elsewhere on the board
unnamed: D1.2 (A), L9.2, U12.1 (SW)
unnamed: R1.2, SW1.2
unnamed: R2.2, SW1.4 (A)
unnamed: R3.1, U1.23 (BIAS)
unnamed: C12.2, L1.2, R5.1, U1.43 (CHSENSE)
unnamed: C7.1, U1.19 (GPIO0/LDOIO0)
unnamed: C21.2, U1.41 (LDO3)
unnamed: C20.2, R6.2, U1.13 (LDO24IN)
unnamed: L2.1, U1.8 (LX2)
unnamed: L3.1, U1.15 (LX3)
unnamed: L1.1, U1.45 (LX_CHG)
unnamed: C6.1, U1.24 (VREF)
unnamed: R10.2, U9.3 (SET)
unnamed: R65.2, U10.3 (SET)
unnamed: C93.1, C104.2, L9.1, U10.1 (VOUT), U12.4 (EN), U12.5 (IN)
unnamed: R32.2, U11.3 (SET)
unnamed: R33.1, R34.2, U12.3 (FB)
PMU_IRQ: U1.48 (IRQ)
PWROK: R4.2, U1.25 (PWROK); also elsewhere on the board

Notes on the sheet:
Ilim = 0.68A
5.00V

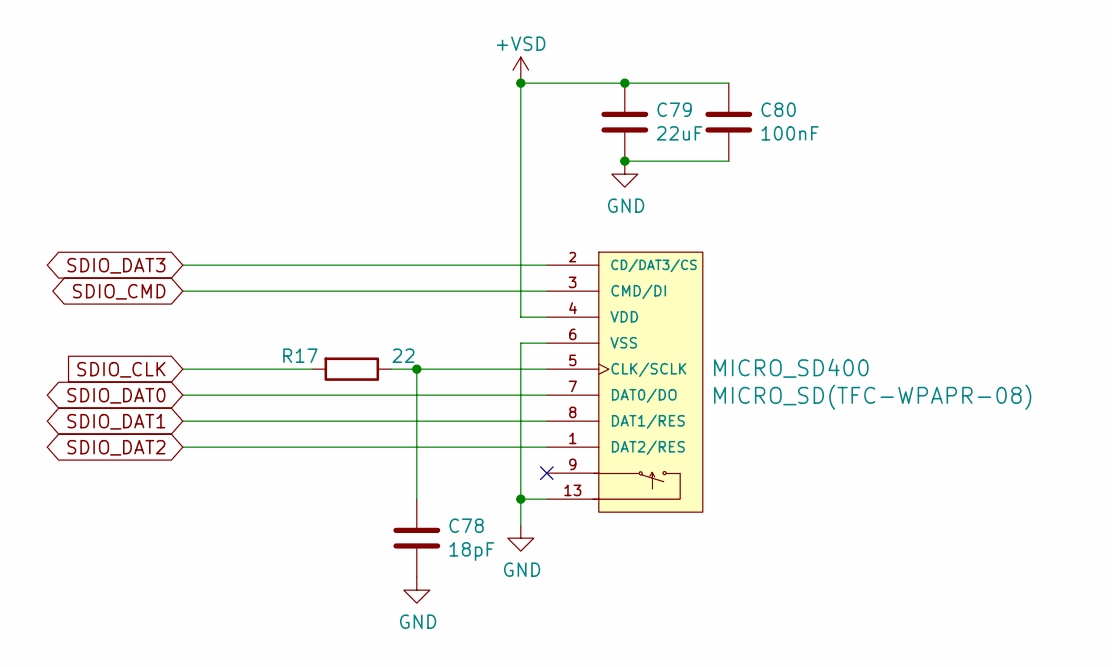
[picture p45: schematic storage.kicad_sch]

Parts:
C78: 18pF; C_0402_1005Metric
C79: 22uF; C_0603_1608Metric
C80: 100nF; C_0402_1005Metric
MICRO_SD400: MICRO_SD(TFC-WPAPR-08); TFC-WPAPR-08
R17: 22; R_0402_1005Metric

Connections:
+VSD: C79.1, C80.1; also elsewhere on the board
GND: C78.2, C79.2, C80.2; also elsewhere on the board
unnamed 81: C78.1, R17.1; also elsewhere on the board
SDIO_CLK: R17.2; also elsewhere on the board

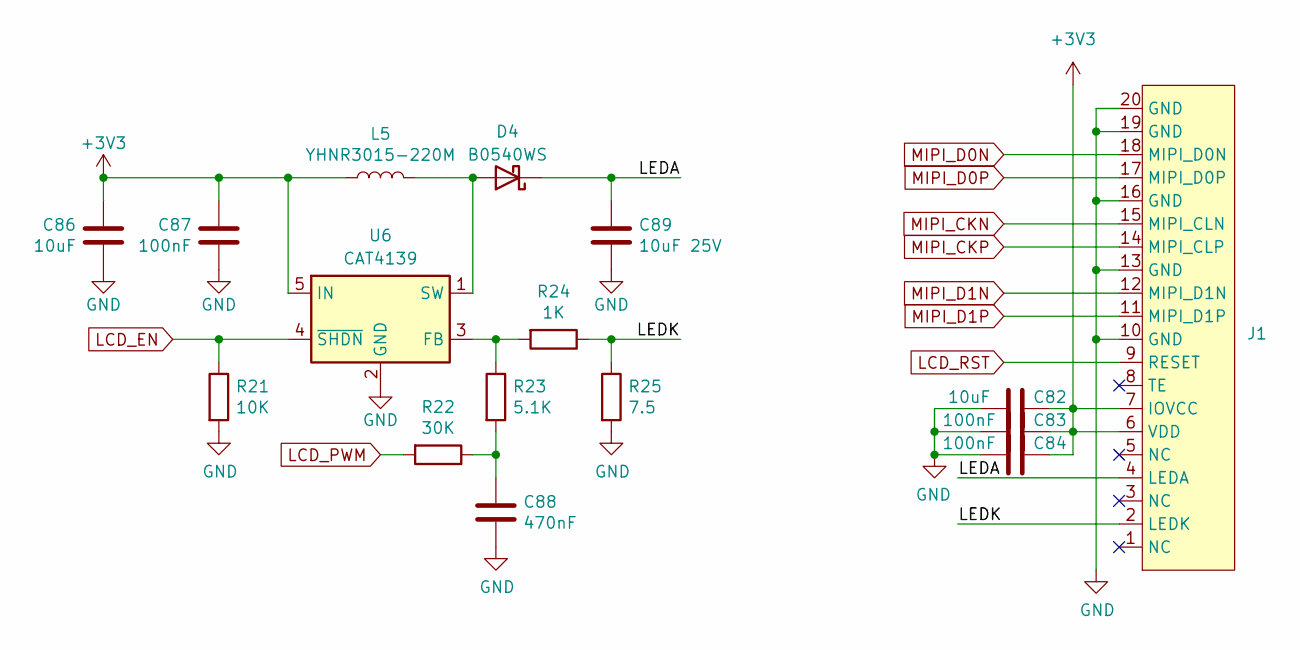
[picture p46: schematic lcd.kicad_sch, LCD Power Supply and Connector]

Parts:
C82, C86: 10uF; C_0603_1608Metric
C83, C84, C87: 100nF; C_0402_1005Metric
C88: 470nF; C_0402_1005Metric
C89: 10uF 25V; C_0805_2012Metric
D4: B0540WS; D_SOD-323
J1: Hirose_FH12-20S-0.5SH_1x20-1MP_P0.50mm_Horizontal_Reversed
L5: YHNR3015-220M; L_Changjiang_FNR3015S
R21: 10K; R_0402_1005Metric
R22: 30K; R_0402_1005Metric
R23: 5.1K; R_0402_1005Metric
R24: 1K; R_0402_1005Metric
R25: 7.5; R_0402_1005Metric
U6: CAT4139; SOT-23-5

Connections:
+3V3: C82.2, C83.1, C84.1, C86.2, C87.2, J1.6 (VDD), J1.7 (IOVCC), L5.1, U6.5 (IN); also elsewhere on the board
/lcd/LEDA: C89.2, D4.1 (K), J1.4 (LEDA)
/lcd/LEDK: J1.2 (LEDK), R24.1, R25.1
GND: C82.1, C83.2, C84.2, C86.1, C87.1, C88.1, C89.1, J1.10 (GND), J1.13 (GND), J1.16 (GND), J1.19 (GND), J1.20 (GND), R21.2, R25.2, U6.2 (GND); also elsewhere on the board
LCD_EN: J1.9 (RESET), R21.1, U6.4 (~SHDN); also elsewhere on the board
LCD_PWM: R22.2; also elsewhere on the board
MIPI_CKN: J1.15 (MIPI_CLN); also elsewhere on the board
MIPI_CKP: J1.14 (MIPI_CLP); also elsewhere on the board
MIPI_D0N: J1.18 (MIPI_D0N); also elsewhere on the board
MIPI_D0P: J1.17 (MIPI_D0P); also elsewhere on the board
MIPI_D1N: J1.12 (MIPI_D1N); also elsewhere on the board
MIPI_D1P: J1.11 (MIPI_D1P); also elsewhere on the board
unnamed: C88.2, R22.1, R23.2
unnamed: D4.2 (A), L5.2, U6.1 (SW)
unnamed: R23.1, R24.2, U6.3 (FB)

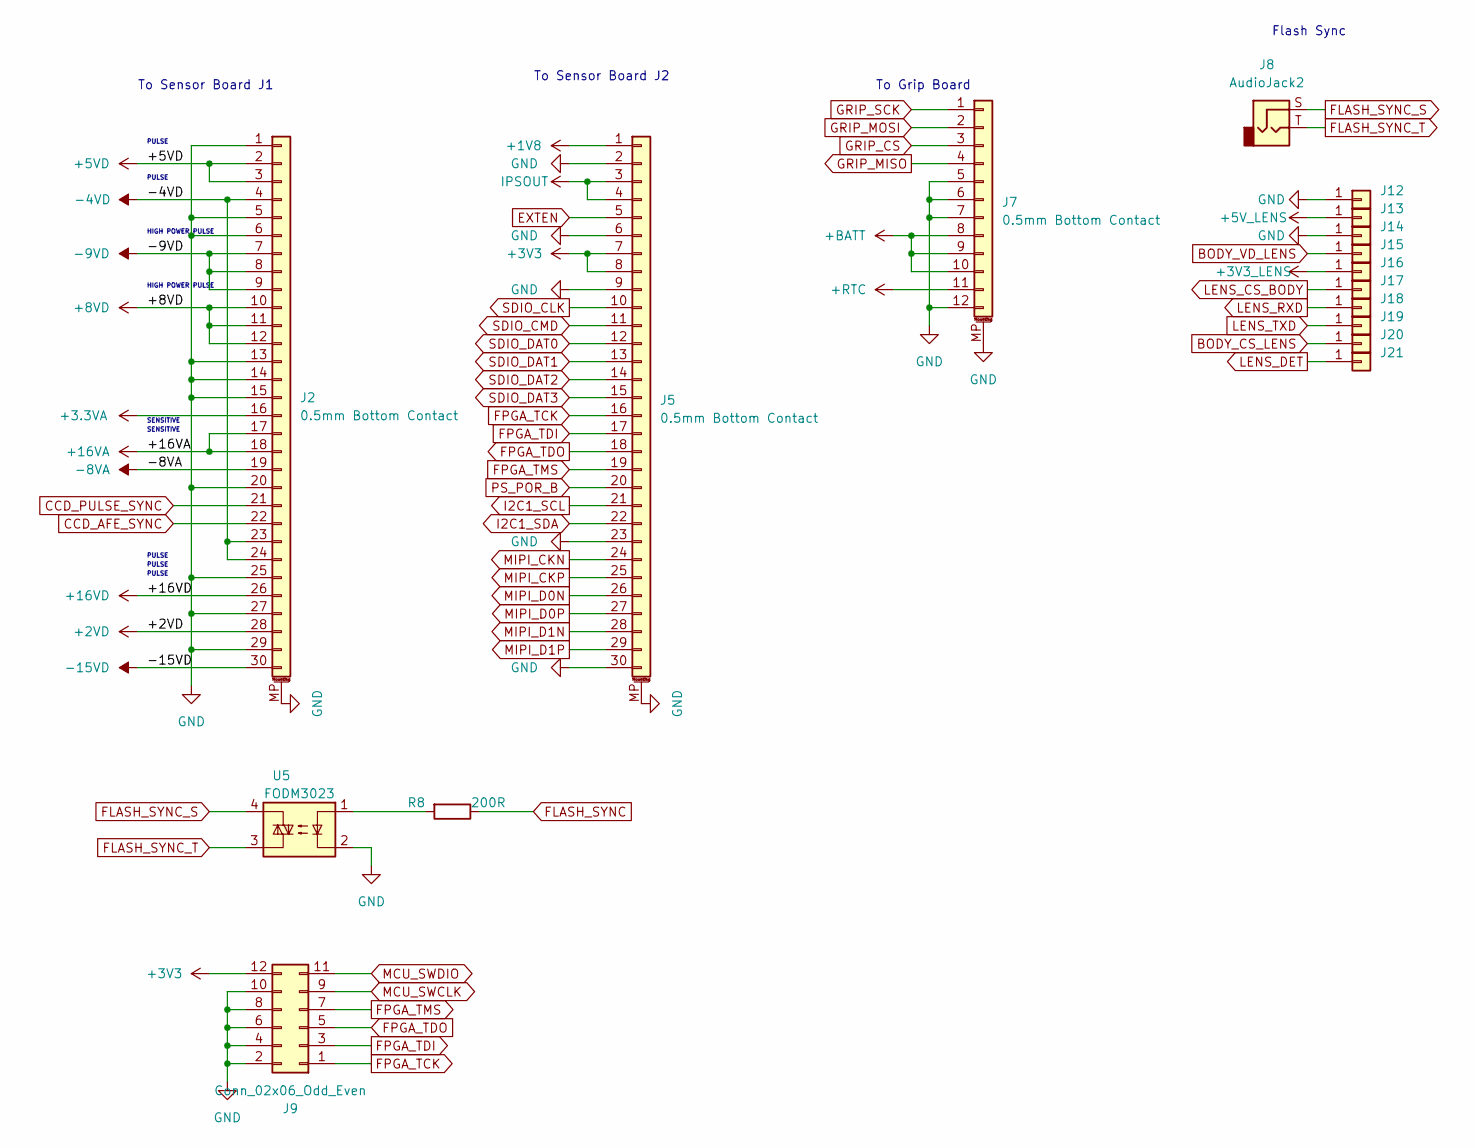
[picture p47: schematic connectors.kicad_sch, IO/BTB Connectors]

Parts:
J2, J5: 0.5mm Bottom Contact; Hirose_FH12-30S-0.5SH_1x30-1MP_P0.50mm_Horizontal
J7: 0.5mm Bottom Contact; Hirose_FH12-12S-0.5SH_1x12-1MP_P0.50mm_Horizontal
J8: AudioJack2; Jack_2.5mm_PJ_210A
J9: Conn_02x06_Odd_Even; PinSocket_2x06_P1.27mm_Horizontal
J12, J13, J14, J15, J16, J17, J18, J19, J20, J21: LensMount; YZP0652-15072-01
R8: 200R; R_0402_1005Metric
U5: FODM3023; MFP4_3.85x4.4

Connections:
+1V8: J5.1; also elsewhere on the board
+2VD: J2.28; also elsewhere on the board
+3.3VA: J2.16; also elsewhere on the board
+3V3: J5.7, J5.8, J9.12; also elsewhere on the board
+3V3_LENS: J16.1; also elsewhere on the board
+5VD: J2.2, J2.3; also elsewhere on the board
+5V_LENS: J13.1; also elsewhere on the board
+8VD: J2.10, J2.11, J2.12; also elsewhere on the board
+16VA: J2.17, J2.18; also elsewhere on the board
+16VD: J2.26; also elsewhere on the board
+BATT: J7.8, J7.9, J7.10; also elsewhere on the board
+RTC: J7.11; also elsewhere on the board
-4VD: J2.4, J2.23, J2.24; also elsewhere on the board
-8VA: J2.19; also elsewhere on the board
-9VD: J2.7, J2.8, J2.9; also elsewhere on the board
-15VD: J2.30; also elsewhere on the board
BODY_CS_LENS: J20.1; also elsewhere on the board
BODY_VD_LENS: J15.1; also elsewhere on the board
CCD_AFE_SYNC: J2.22
CCD_PULSE_SYNC: J2.21
EXTEN: J5.5; also elsewhere on the board
FLASH_SYNC: R8.1; also elsewhere on the board
FLASH_SYNC_S: J8.S, U5.4
FLASH_SYNC_T: J8.T, U5.3
FPGA_TCK: J5.16, J9.1
FPGA_TDI: J5.17, J9.3
FPGA_TDO: J5.18, J9.5
FPGA_TMS: J5.19, J9.7
GND: J2.1, J2.5, J2.6, J2.13, J2.14, J2.15, J2.20, J2.25, J2.27, J2.29, J2.MP (MountPin), J5.2, J5.6, J5.9, J5.23, J5.30, J5.MP (MountPin), J7.5, J7.6, J7.7, J7.12, J7.MP (MountPin), J9.2, J9.4, J9.6, J9.8, J9.10, J12.1, J14.1, U5.2; also elsewhere on the board
GRIP_CS: J7.3; also elsewhere on the board
GRIP_MISO: J7.4; also elsewhere on the board
GRIP_MOSI: J7.2; also elsewhere on the board
GRIP_SCK: J7.1; also elsewhere on the board
I2C1_SCL: J5.21; also elsewhere on the board
I2C1_SDA: J5.22; also elsewhere on the board
IPSOUT: J5.3, J5.4; also elsewhere on the board
LENS_CS_BODY: J17.1; also elsewhere on the board
LENS_DET: J21.1; also elsewhere on the board
LENS_RXD: J18.1; also elsewhere on the board
LENS_TXD: J19.1; also elsewhere on the board
MCU_SWCLK: J9.9; also elsewhere on the board
MCU_SWDIO: J9.11; also elsewhere on the board
MIPI_CKN: J5.24; also elsewhere on the board
MIPI_CKP: J5.25; also elsewhere on the board
MIPI_D0N: J5.26; also elsewhere on the board
MIPI_D0P: J5.27; also elsewhere on the board
MIPI_D1N: J5.28; also elsewhere on the board
MIPI_D1P: J5.29; also elsewhere on the board
unnamed: R8.2, U5.1
PS_POR_B: J5.20; also elsewhere on the board
SDIO_CLK: J5.10; also elsewhere on the board
SDIO_CMD: J5.11; also elsewhere on the board
SDIO_DAT0: J5.12; also elsewhere on the board
SDIO_DAT1: J5.13; also elsewhere on the board
SDIO_DAT2: J5.14; also elsewhere on the board
SDIO_DAT3: J5.15; also elsewhere on the board

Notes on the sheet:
PULSE
To Sensor Board J2
To Grip Board
SENSITIVE
To Sensor Board J1
Flash Sync
HIGH POWER PULSE

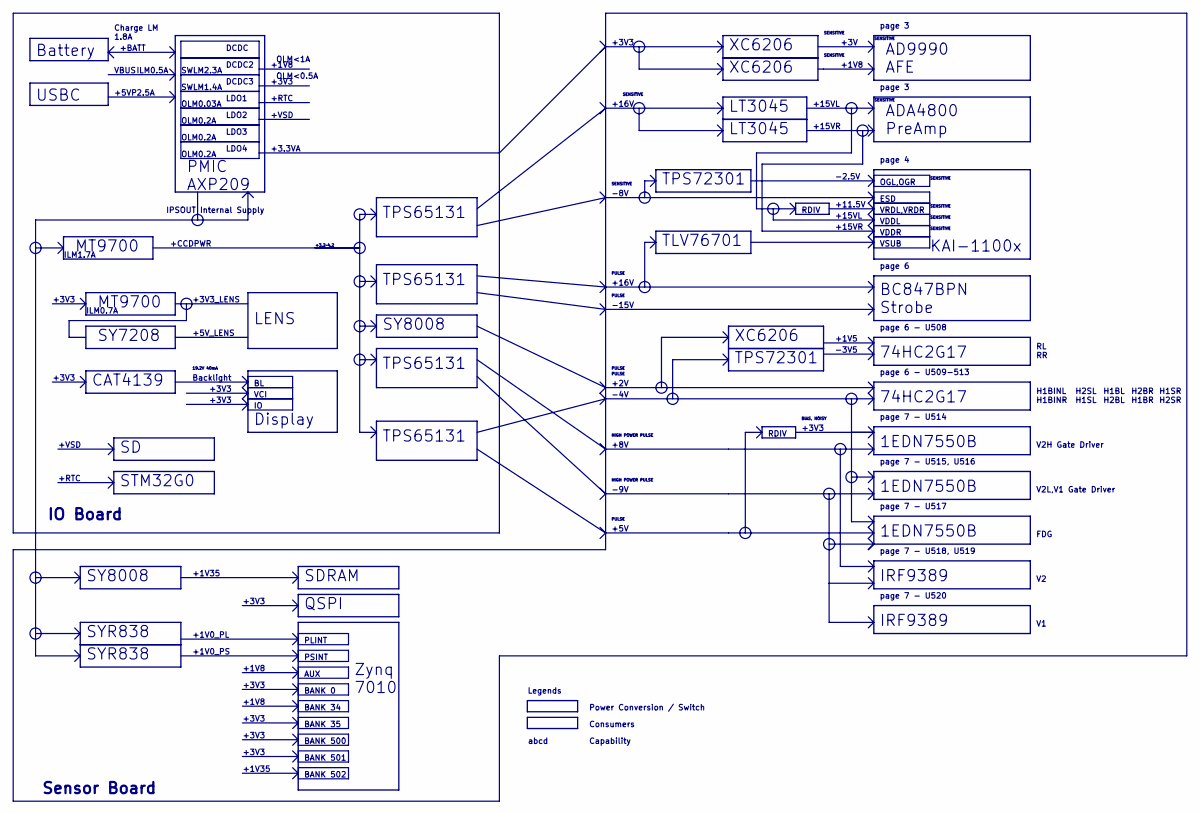
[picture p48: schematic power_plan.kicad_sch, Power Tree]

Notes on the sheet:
SY7208
page 7 - U515, U516
+CCDPWR
+3V3
SENSITIVE
+VSD
HIGH POWER PULSE
+15VL
page 6 - U508
SWLM1.4A
+1V0_PL
+RTC
+15VR
Consumers
DCDC3
VCI
PLINT
Backlight
OLM0.03A
+1V8
STM32G0
+1V5
2.5A
OLM<1A
page 6 - U509-513
ESD
IPSOUT Internal Supply
VDDR
LT3045
+16V
BANK 501
Legends
TPS65131
Zynq 7010
+1V35
H1BL H2BL
MT9700
+2V
Capability
PULSE

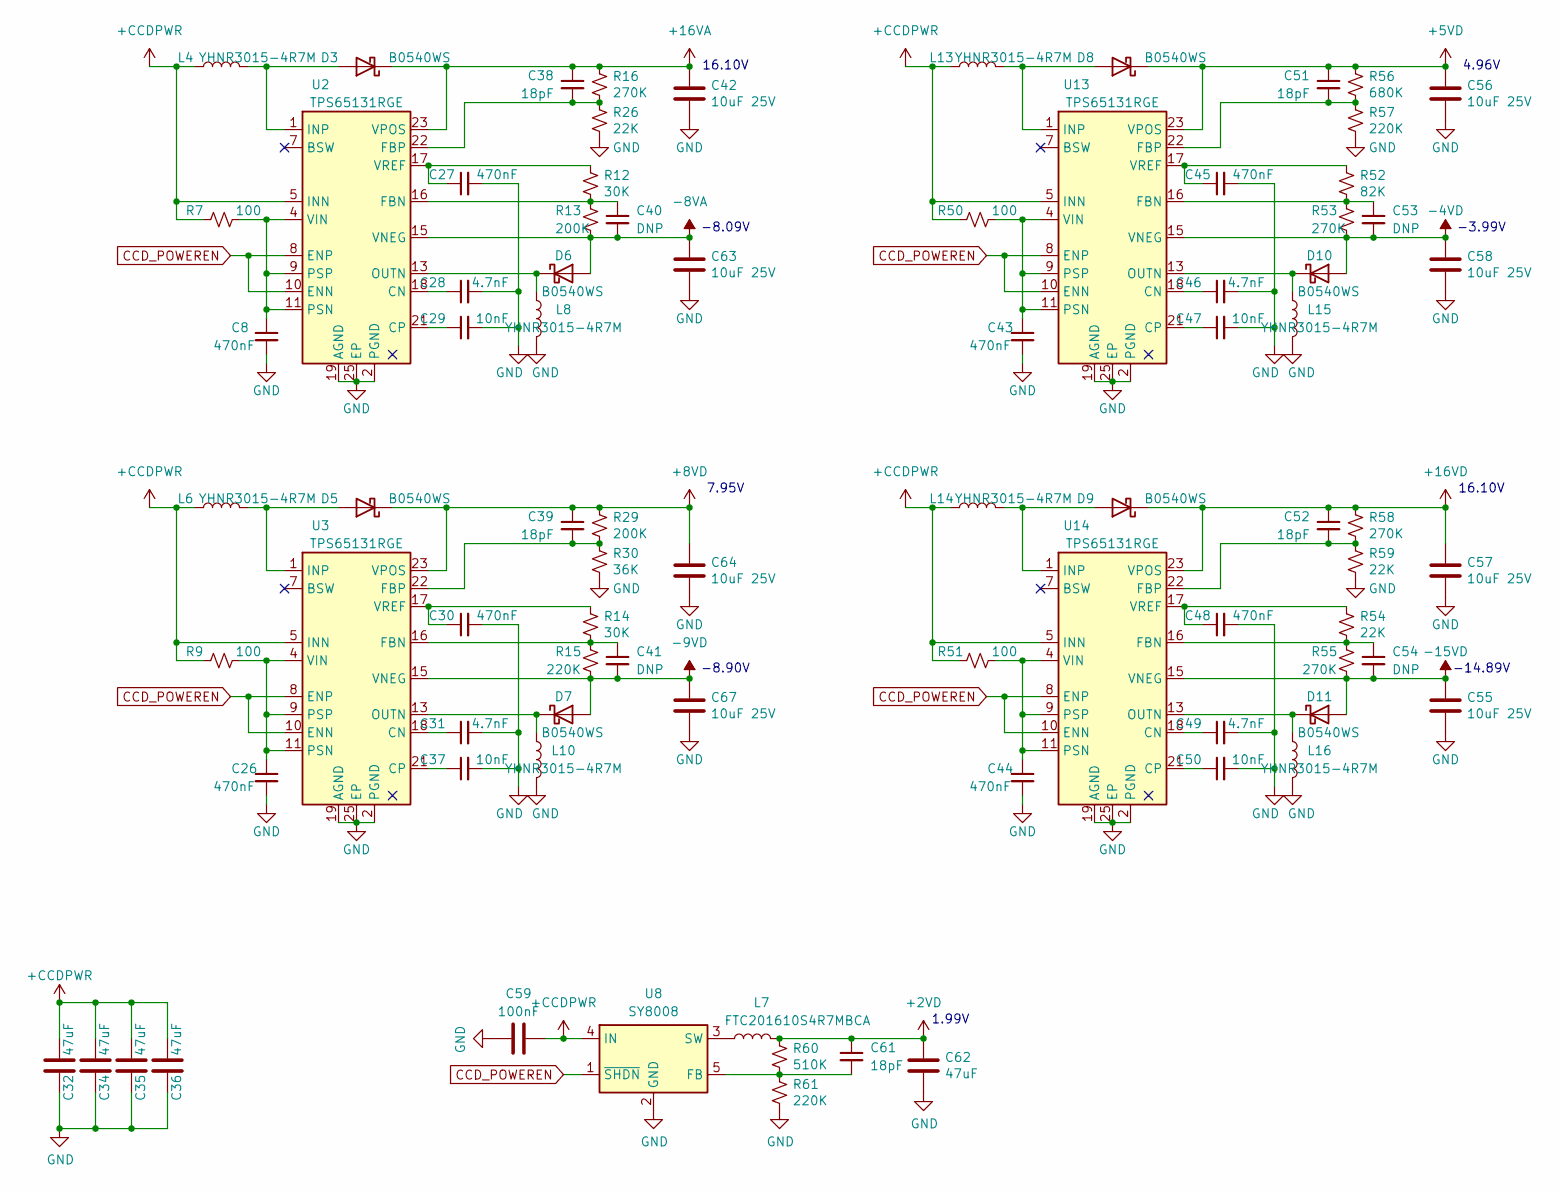
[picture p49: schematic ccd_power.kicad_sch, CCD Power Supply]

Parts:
C8, C26, C27, C30, C43, C44, C45, C48: 470nF; C_0402_1005Metric
C28, C31, C46, C49: 4.7nF; C_0402_1005Metric
C29, C37, C47, C50: 10nF; C_0402_1005Metric
C32, C34, C35, C36, C62: 47uF; C_0805_2012Metric
C38, C39, C51, C52, C61: 18pF; C_0402_1005Metric
C40, C41, C53, C54: DNP; C_0402_1005Metric
C42, C55, C56, C57, C58, C63, C64, C67: 10uF 25V; C_0805_2012Metric
C59: 100nF; C_0402_1005Metric
D3, D5, D6, D7, D8, D9, D10, D11: B0540WS; D_SOD-323
L4, L6, L8, L10, L13, L14, L15, L16: YHNR3015-4R7M; L_Changjiang_FNR3015S
L7: FTC201610S4R7MBCA; L_Murata_DFE201610P
R7, R9, R50, R51: 100; R_0402_1005Metric
R12, R14: 30K; R_0402_1005Metric
R13, R29: 200K; R_0402_1005Metric
R15, R57, R61: 220K; R_0402_1005Metric
R16, R53, R55, R58: 270K; R_0402_1005Metric
R26, R54, R59: 22K; R_0402_1005Metric
R30: 36K; R_0402_1005Metric
R52: 82K; R_0402_1005Metric
R56: 680K; R_0402_1005Metric
R60: 510K; R_0402_1005Metric
U2, U3, U13, U14: TPS65131RGE; VQFN-24-1EP_4x4mm_P0.5mm_EP2.45x2.45mm_0.3ThermalVias
U8: SY8008; TSOT-23-5

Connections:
+2VD: C61.1, C62.1, L7.2, R60.1; also elsewhere on the board
+5VD: C51.1, C56.1, D8.1 (K), R56.1, U13.23 (VPOS); also elsewhere on the board
+8VD: C39.1, C64.1, D5.1 (K), R29.1, U3.23 (VPOS); also elsewhere on the board
+16VA: C38.1, C42.1, D3.1 (K), R16.1, U2.23 (VPOS); also elsewhere on the board
+16VD: C52.1, C57.1, D9.1 (K), R58.1, U14.23 (VPOS); also elsewhere on the board
+CCDPWR: C32.1, C34.1, C35.1, C36.1, C59.2, L4.2, L6.2, L13.2, L14.2, R7.2, R9.2, R50.2, R51.2, U2.5 (INN), U2.6 (INN), U3.5 (INN), U3.6 (INN), U8.4 (IN), U13.5 (INN), U13.6 (INN), U14.5 (INN), U14.6 (INN); also elsewhere on the board
-4VD: C53.2, C58.1, D10.2 (A), R53.2, U13.15 (VNEG); also elsewhere on the board
-8VA: C40.2, C63.1, D6.2 (A), R13.2, U2.15 (VNEG); also elsewhere on the board
-9VD: C41.2, C67.1, D7.2 (A), R15.2, U3.15 (VNEG); also elsewhere on the board
-15VD: C54.2, C55.1, D11.2 (A), R55.2, U14.15 (VNEG); also elsewhere on the board
CCD_POWEREN: U2.8 (ENP), U2.10 (ENN), U3.8 (ENP), U3.10 (ENN), U8.1 (~SHDN), U13.8 (ENP), U13.10 (ENN), U14.8 (ENP), U14.10 (ENN); also elsewhere on the board
GND: C8.2, C26.2, C27.2, C28.2, C29.2, C30.2, C31.2, C32.2, C34.2, C35.2, C36.2, C37.2, C42.2, C43.2, C44.2, C45.2, C46.2, C47.2, C48.2, C49.2, C50.2, C55.2, C56.2, C57.2, C58.2, C59.1, C62.2, C63.2, C64.2, C67.2, L8.1, L10.1, L15.1, L16.1, R26.2, R30.2, R57.2, R59.2, R61.2, U2.2 (PGND), U2.3 (PGND), U2.19 (AGND), U2.25 (EP), U3.2 (PGND), U3.3 (PGND), U3.19 (AGND), U3.25 (EP), U8.2 (GND), U13.2 (PGND), U13.3 (PGND), U13.19 (AGND), U13.25 (EP), U14.2 (PGND), U14.3 (PGND), U14.19 (AGND), U14.25 (EP); also elsewhere on the board
unnamed: D3.2 (A), L4.1, U2.1 (INP), U2.24 (INP)
unnamed: D5.2 (A), L6.1, U3.1 (INP), U3.24 (INP)
unnamed: D6.1 (K), L8.2, U2.13 (OUTN), U2.14 (OUTN)
unnamed: D7.1 (K), L10.2, U3.13 (OUTN), U3.14 (OUTN)
unnamed: D8.2 (A), L13.1, U13.1 (INP), U13.24 (INP)
unnamed: D9.2 (A), L14.1, U14.1 (INP), U14.24 (INP)
unnamed: D10.1 (K), L15.2, U13.13 (OUTN), U13.14 (OUTN)
unnamed: D11.1 (K), L16.2, U14.13 (OUTN), U14.14 (OUTN)
unnamed: C28.1, U2.18 (CN)
unnamed: C29.1, U2.21 (CP)
unnamed: C40.1, R12.2, R13.1, U2.16 (FBN)
unnamed: C38.2, R16.2, R26.1, U2.22 (FBP)
unnamed: C8.1, R7.1, U2.4 (VIN), U2.9 (PSP), U2.11 (PSN)
unnamed: C27.1, R12.1, U2.17 (VREF)
unnamed: C31.1, U3.18 (CN)
unnamed: C37.1, U3.21 (CP)
unnamed: C41.1, R14.2, R15.1, U3.16 (FBN)
unnamed: C39.2, R29.2, R30.1, U3.22 (FBP)
unnamed: C26.1, R9.1, U3.4 (VIN), U3.9 (PSP), U3.11 (PSN)
unnamed: C30.1, R14.1, U3.17 (VREF)
unnamed: C61.2, R60.2, R61.1, U8.5 (FB)
unnamed: L7.1, U8.3 (SW)
unnamed: C46.1, U13.18 (CN)
unnamed: C47.1, U13.21 (CP)
unnamed: C53.1, R52.2, R53.1, U13.16 (FBN)
unnamed: C51.2, R56.2, R57.1, U13.22 (FBP)
unnamed: C43.1, R50.1, U13.4 (VIN), U13.9 (PSP), U13.11 (PSN)
unnamed: C45.1, R52.1, U13.17 (VREF)
unnamed: C49.1, U14.18 (CN)
unnamed: C50.1, U14.21 (CP)
unnamed: C54.1, R54.2, R55.1, U14.16 (FBN)
unnamed: C52.2, R58.2, R59.1, U14.22 (FBP)
unnamed: C44.1, R51.1, U14.4 (VIN), U14.9 (PSP), U14.11 (PSN)
unnamed: C48.1, R54.1, U14.17 (VREF)

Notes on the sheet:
-3.99V
4.96V
-8.09V
7.95V
-14.89V
16.10V
1.99V
-8.90V

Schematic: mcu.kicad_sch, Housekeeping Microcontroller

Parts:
BZ1: Buzzer; Buzzer_Murata_PKMCS0909E
C33: 10uF; C_0603_1608Metric
C65, C66: 18pF; C_0402_1005Metric
C72, C92: 100nF; C_0402_1005Metric
D2: LED; LED_0603_1608Metric
R11, R18, R35, R36, R38: 10K; R_0402_1005Metric
R37: 1K; R_0402_1005Metric
R39, R40: 2.2K; R_0402_1005Metric
U4: STM32G030K6Tx; LQFP-32_7x7mm_P0.8mm
Y2: 32.768K; Crystal_SMD_TXC_9HT11-2Pin_2.0x1.2mm_HandSoldering

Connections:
+3V3: R36.1, R38.1, R39.1, R40.1; also elsewhere on the board
+RTC: C33.1, C92.1, R11.1, U4.4 (VDD); also elsewhere on the board
/mcu/BEEPER: R37.2, U4.27 (PB3)
/mcu/LED_R: R35.1, U4.32 (PB8)
BODY_CS_LENS: U4.29 (PB5); also elsewhere on the board
BODY_VD_LENS: U4.15 (PB0); also elsewhere on the board
CCD_POWEREN: U4.17 (PB2); also elsewhere on the board
DCDC_EN: U4.16 (PB1); also elsewhere on the board
FLASH_SYNC: U4.1 (PB9); also elsewhere on the board
GND: BZ1.2 (-), C33.2, C65.1, C66.1, C72.1, C92.2, D2.1 (K), R18.1, U4.5 (VSS); also elsewhere on the board
GRIP_CS: U4.11 (PA4); also elsewhere on the board
GRIP_MISO: U4.13 (PA6); also elsewhere on the board
GRIP_MOSI: U4.14 (PA7); also elsewhere on the board
GRIP_SCK: U4.12 (PA5); also elsewhere on the board
I2C1_SCL: R40.2, U4.19 (PA9/NC); also elsewhere on the board
I2C1_SDA: R39.2, U4.21 (PA10/NC); also elsewhere on the board
I2C2_SCL: R38.2, U4.22 (PA11/PA9); also elsewhere on the board
I2C2_SDA: R36.2, U4.23 (PA12/PA10); also elsewhere on the board
LCD_EN: U4.31 (PB7); also elsewhere on the board
LCD_PWM: U4.28 (PB4); also elsewhere on the board
LENS_CS_BODY: U4.18 (PA8); also elsewhere on the board
LENS_DET: U4.7 (PA0); also elsewhere on the board
LENS_PWR_EN: U4.8 (PA1); also elsewhere on the board
LENS_RXD: U4.10 (PA3); also elsewhere on the board
LENS_TXD: U4.9 (PA2); also elsewhere on the board
MCU_SWCLK: R18.2, U4.25 (PA14); also elsewhere on the board
MCU_SWDIO: U4.24 (PA13); also elsewhere on the board
unnamed: BZ1.1 (+), R37.1
unnamed: D2.2 (A), R35.2
unnamed: C72.2, R11.2, U4.6 (NRST)
unnamed: C65.2, U4.2 (PC14), Y2.1
unnamed: C66.2, U4.3 (PC15), Y2.2
PS_POR_B: U4.30 (PB6); also elsewhere on the board
PWROK: U4.26 (PA15); also elsewhere on the board

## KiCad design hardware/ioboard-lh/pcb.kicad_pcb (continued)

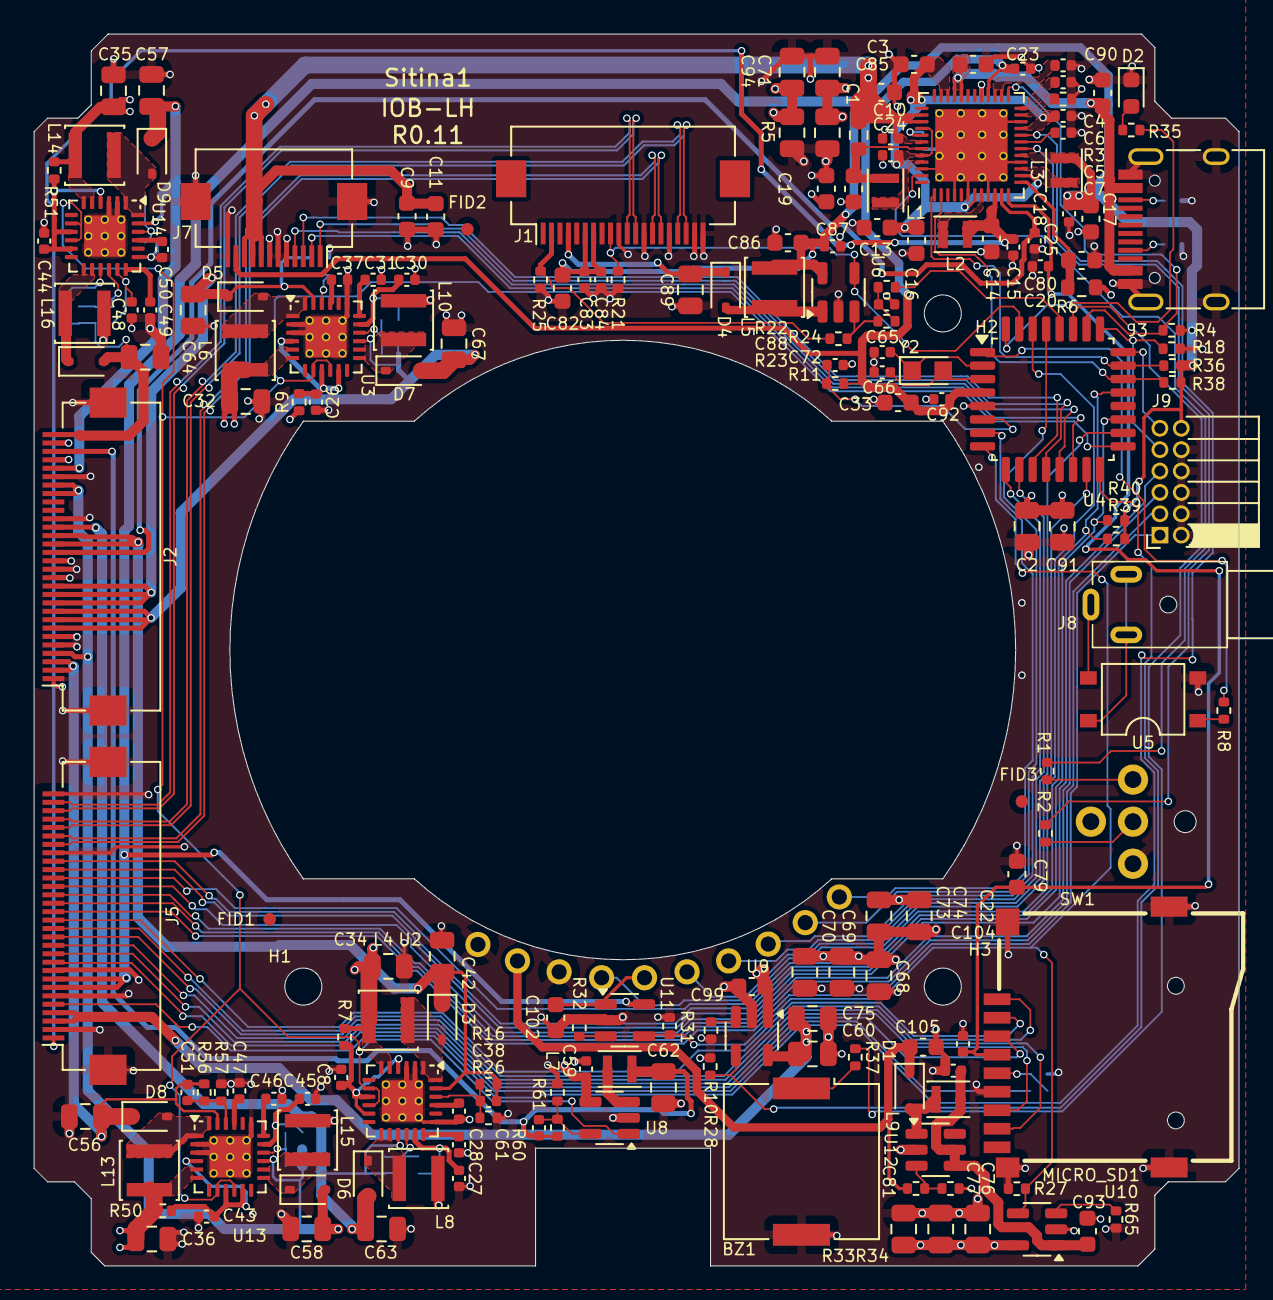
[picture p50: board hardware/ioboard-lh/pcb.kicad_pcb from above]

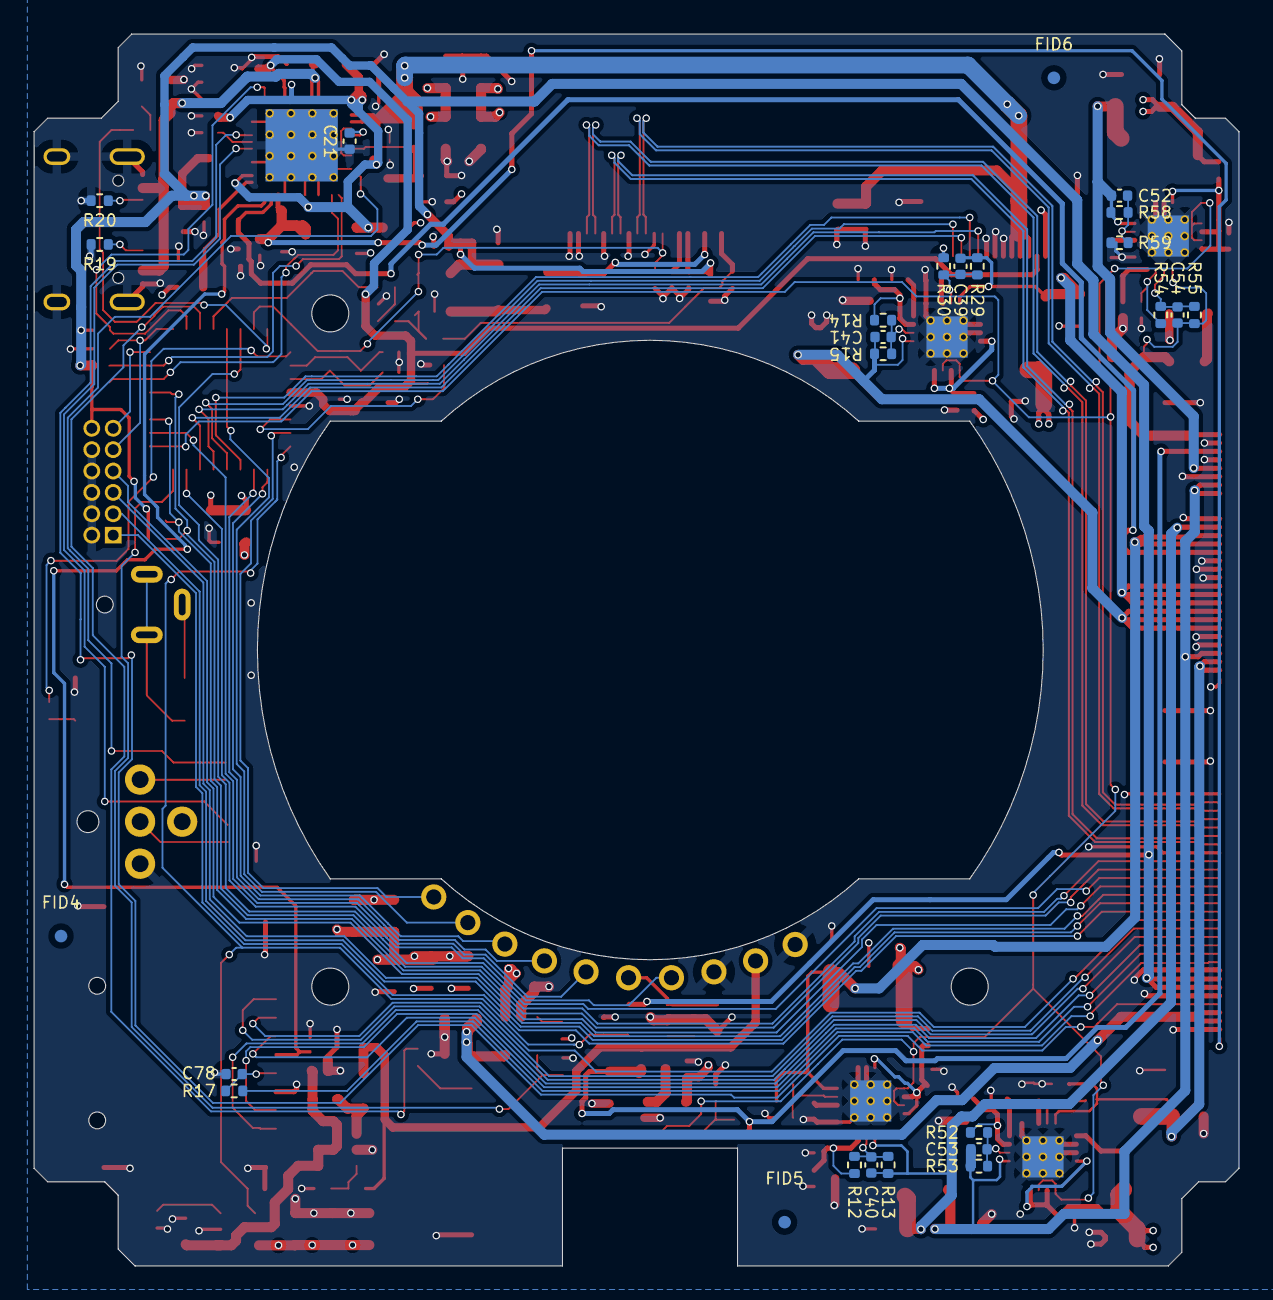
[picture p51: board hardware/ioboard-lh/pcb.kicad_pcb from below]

Board: 4 copper layers, 71.6 x 73.2 mm, 221 parts (36 on the bottom side), 134 nets.

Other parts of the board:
MICRO_SD1: MICRO_SD(TFC-WPAPR-08); TFC-WPAPR-08

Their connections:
+VSD: MICRO_SD1.4 (VDD); also elsewhere on the board
GND: MICRO_SD1.6 (VSS), MICRO_SD1.10, MICRO_SD1.11, MICRO_SD1.12, MICRO_SD1.13; also elsewhere on the board
unnamed 81: MICRO_SD1.5 (CLK/SCLK); also elsewhere on the board
SDIO_CMD: MICRO_SD1.3 (CMD/DI); also elsewhere on the board
SDIO_DAT0: MICRO_SD1.7 (DAT0/DO); also elsewhere on the board
SDIO_DAT1: MICRO_SD1.8 (DAT1/RES); also elsewhere on the board
SDIO_DAT2: MICRO_SD1.1 (DAT2/RES); also elsewhere on the board
SDIO_DAT3: MICRO_SD1.2 (CD/DAT3/CS); also elsewhere on the board

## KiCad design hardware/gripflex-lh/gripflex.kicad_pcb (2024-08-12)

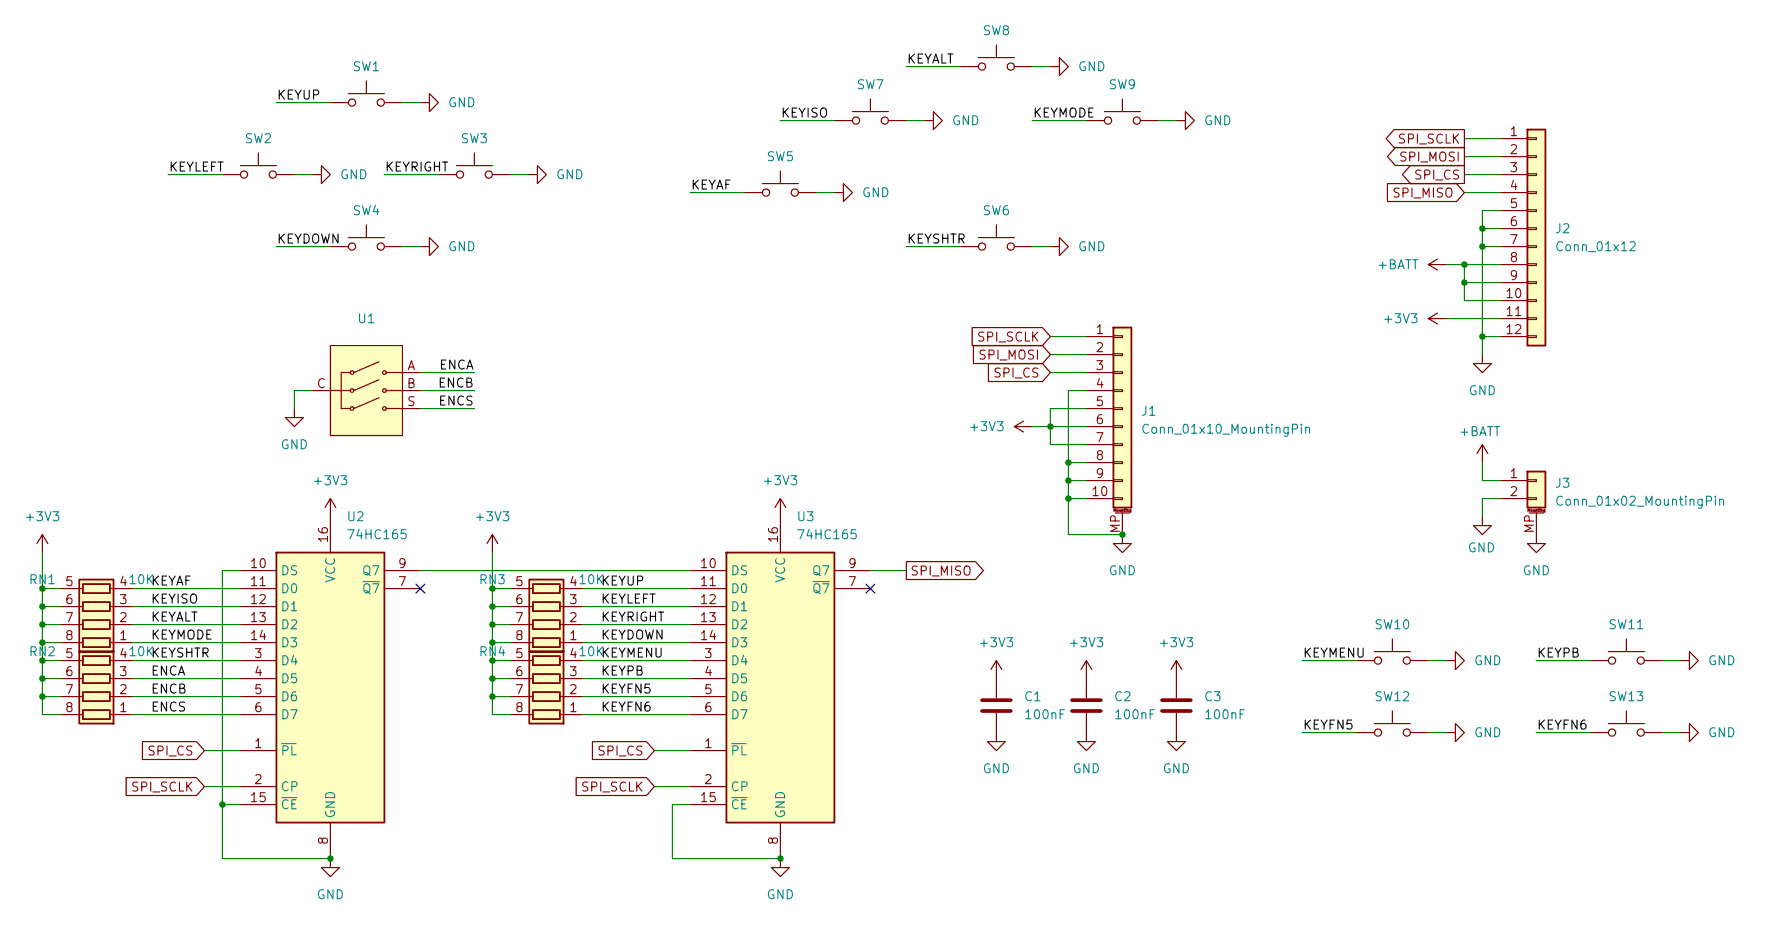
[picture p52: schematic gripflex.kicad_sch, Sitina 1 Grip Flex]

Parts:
C1, C2, C3: 100nF; C_0402_1005Metric
J1: Conn_01x10_MountingPin; Hirose_FH12-10S-0.5SH_1x10-1MP_P0.50mm_Horizontal
J2: Conn_01x12; FPC_12
J3: Conn_01x02_MountingPin; JST_PH_S2B-PH-SM4-TB_1x02-1MP_P2.00mm_Horizontal
RN1, RN2, RN3, RN4: 10K; R_Array_Convex_4x0402
SW1, SW2, SW3, SW4, SW5, SW6, SW7, SW8, SW9, SW10, SW11, SW12, SW13: HX-TS5208A
U1: SIQ-02FVS3_L
U2, U3: 74HC165; TSSOP-16_4.4x5mm_P0.65mm

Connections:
+3V3: C1.1, C2.1, C3.1, J1.5, J1.6, J1.7, J2.11, RN1.5 (R4.2), RN1.6 (R3.2), RN1.7 (R2.2), RN1.8 (R1.2), RN2.5 (R4.2), RN2.6 (R3.2), RN2.7 (R2.2), RN2.8 (R1.2), RN3.5 (R4.2), RN3.6 (R3.2), RN3.7 (R2.2), RN3.8 (R1.2), RN4.5 (R4.2), RN4.6 (R3.2), RN4.7 (R2.2), RN4.8 (R1.2), U2.16 (VCC), U3.16 (VCC)
+BATT: J2.8, J2.9, J2.10, J3.1
/ENCA: RN2.3 (R3.1), U1.A, U2.4 (D5)
/ENCB: RN2.2 (R2.1), U1.B, U2.5 (D6)
/ENCS: RN2.1 (R1.1), U1.S, U2.6 (D7)
/KEYAF: RN1.4 (R4.1), SW5.1, U2.11 (D0)
/KEYALT: RN1.2 (R2.1), SW8.1, U2.13 (D2)
/KEYDOWN: RN3.1 (R1.1), SW4.1, U3.14 (D3)
/KEYFN5: RN4.2 (R2.1), SW12.1, U3.5 (D6)
/KEYFN6: RN4.1 (R1.1), SW13.1, U3.6 (D7)
/KEYISO: RN1.3 (R3.1), SW7.1, U2.12 (D1)
/KEYLEFT: RN3.3 (R3.1), SW2.1, U3.12 (D1)
/KEYMENU: RN4.4 (R4.1), SW10.1, U3.3 (D4)
/KEYMODE: RN1.1 (R1.1), SW9.1, U2.14 (D3)
/KEYPB: RN4.3 (R3.1), SW11.1, U3.4 (D5)
/KEYRIGHT: RN3.2 (R2.1), SW3.1, U3.13 (D2)
/KEYSHTR: RN2.4 (R4.1), SW6.1, U2.3 (D4)
/KEYUP: RN3.4 (R4.1), SW1.1, U3.11 (D0)
GND: C1.2, C2.2, C3.2, J1.4, J1.8, J1.9, J1.10, J1.MP (MountPin), J2.5, J2.6, J2.7, J2.12, J3.2, J3.MP (MountPin), SW1.2, SW2.2, SW3.2, SW4.2, SW5.2, SW6.2, SW7.2, SW8.2, SW9.2, SW10.2, SW11.2, SW12.2, SW13.2, U1.C, U2.8 (GND), U2.10 (DS), U2.15 (~CE), U3.8 (GND), U3.15 (~CE)
unnamed: U2.9 (Q7), U3.10 (DS)
SPI_CS: J1.3, J2.3, U2.1 (~PL), U3.1 (~PL)
SPI_MISO: J2.4, U3.9 (Q7)
SPI_MOSI: J1.2, J2.2
SPI_SCLK: J1.1, J2.1, U2.2 (CP), U3.2 (CP)

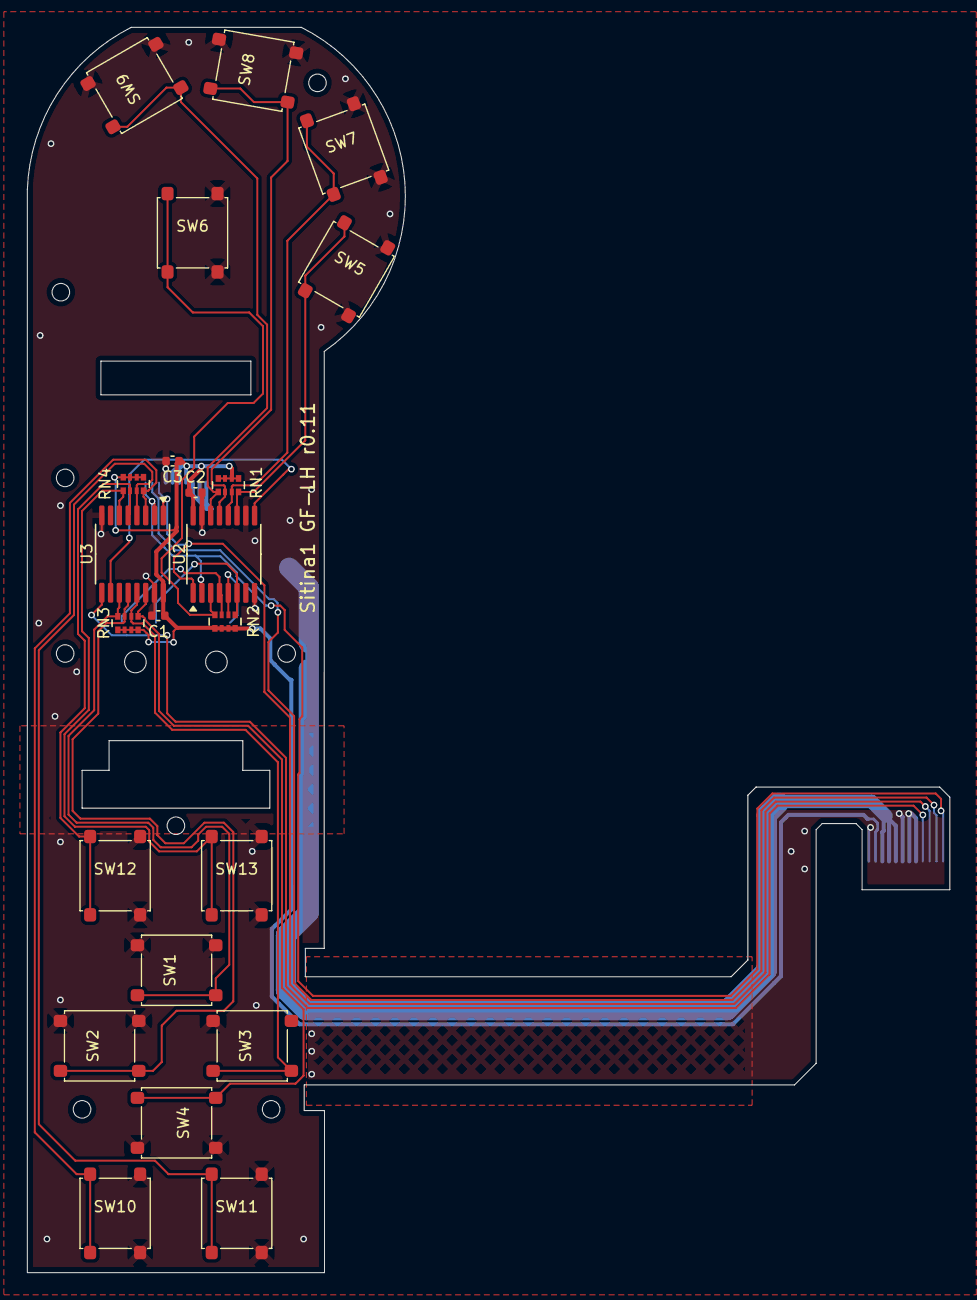
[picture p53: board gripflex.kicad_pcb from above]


Board: 2 copper layers, 68.3 x 92.2 mm, 26 parts (4 on the bottom side), 24 nets.

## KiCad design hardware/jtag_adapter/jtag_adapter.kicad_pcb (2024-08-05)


Board: 2 copper layers, 21.5 x 14.0 mm, 5 parts (1 on the bottom side), 10 nets.

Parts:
D1, D2: B0540W; D_SOD-323
J1: Conn_02x06_Odd_Even; PinHeader_2x06_P1.27mm_Vertical_SMD
J2: Conn_02x07_Odd_Even; PinHeader_2x06_P2.00mm_Vertical_SMD
J6: Conn_02x05_Odd_Even; PinHeader_2x05_P1.27mm_Vertical_SMD

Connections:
+3V3: D1.1 (K), D2.1 (K), J1.12
FPGA_TCK: J1.1, J2.6
FPGA_TDI: J1.3, J2.10
FPGA_TDO: J1.5, J2.8
FPGA_TMS: J1.7, J2.4
GND: J1.2, J1.4, J1.6, J1.8, J1.10, J2.3, J2.5, J2.7, J2.9, J2.11, J6.3, J6.5, J6.9
MCU_SWCLK: J1.9, J6.4
MCU_SWDIO: J1.11, J6.2
unnamed: D1.2 (A), J6.1
unnamed: D2.2 (A), J2.2

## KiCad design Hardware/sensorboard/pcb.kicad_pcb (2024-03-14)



Board: 4 copper layers, 71.5 x 63.0 mm, 357 parts (90 on the bottom side), 263 nets.

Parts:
C1, C6, C7, C8, C17, C18, C19, C20, C104, C105, C106: 1uF; C_0402_1005Metric
C2, C3: 10uF; C_0805_2012Metric
C4, C5, C43, C44: 4.7uF; C_0402_1005Metric
C9, C10, C45, C52: 22uF 25V; C_0805_2012Metric
C11, C12, C13, C14, C15, C16, C21, C22, C24, C26, C27, C28, C31, C32, C33, C34, C36, C38, C40, C42, C46, C47, C48, C49, C50, C51, C56, C57, C58, C59, C60, C61, C62, C63, C65, C66, C67, C68, C69, C70, C71, C72, C73, C74, C75, C76, C83, C84, C85, C86, C87, C88, C89, C90, C101, C102, C103, C135, C141, C153, C154: 100nF; C_0402_1005Metric
C23, C25, C29, C30, C35, C37, C39, C41, C91, C92, C93, C94, C107, C108, C109: 10uF; C_0603_1608Metric
C53, C54: 220uF / 6V; CP_EIA-3528-15_AVX-H
C55: DNP/1nF; C_0402_1005Metric
C64: 1uF 25V; C_0603_1608Metric
C77, C79: DNP; C_0402_1005Metric
C78, C80, C81, C82: 470uF; C_Elec_6.3x7.7
C95, C96, C97, C98, C99, C100: 1nF; C_0402_1005Metric
C110, C113, C115, C116, C117, C118, C119, C120, C125, C126, C127, C136, C138, C142, C145, C155, C156, C158, C159, C161, C162: 470nF; C_0402_1005Metric
C111, C121, C122, C128, C129, C130, C148, C152, C157, C160, C163: 4.7uF; C_0603_1608Metric
C112, C123, C124, C131, C132, C133: 100uF; C_0805_2012Metric
C114, C151: 47uF; C_0805_2012Metric
C134, C137, C139, C140, C143, C144, C146, C147, C150: 220nF; C_0402_1005Metric
C149: 22uF; C_0603_1608Metric
D1, D2, D3, D4, D5, D6, D7, D8, D9, D10: LED; D_0603_1608Metric
D11, D12, D13, D18, D19, D20: BAT54S; SOT-23
D14, D15, D16, D17: B0540W; D_SOD-323
D21, D22: LED; LED_0603_1608Metric
FB1, FB2, FB3, FB4, FB5, FB6, FB7, FB8, FB9, FB10: FerriteBead; L_0603_1608Metric
FB11: 120R; R_0402_1005Metric
H1, H2, H3: MountingHole; MountingHole_2.2mm_M2_DIN965
HS1: Heatsink; sb_heatsink
J1, J2: FPC 0.5mm Bottom Contact; Hirose_FH12-30S-0.5SH_1x30-1MP_P0.50mm_Horizontal
Q1: BC847BPN; SOT-363_SC-70-6
R1, R2: 249R; R_0402_1005Metric
R3, R4: 30.1K; R_0402_1005Metric
R5, R7, R31: 270K 1%; R_0402_1005Metric
R6, R8, R32: 22K 1%; R_0402_1005Metric
R9, R10, R11, R24, R55, R57, R58, R60, R112: 10K; R_0402_1005Metric
R12, R13, R14, R15, R75, R76, R77, R78, R81, R82, R83, R84, R85, R86, R87, R88: 5.1K; R_0402_1005Metric
R16, R17: 3.3K; R_0402_1005Metric
R18: 500; R_0402_1005Metric
R19, R20: 49.9K 1%; R_0402_1005Metric
R21, R22: 200K 1%; R_0402_1005Metric
R23, R28: 49.9; R_0402_1005Metric
R25, R26, R27, R29, R53, R59: 0; R_0402_1005Metric
R30, R56: 82K 1%; R_0402_1005Metric
R33, R54, R96, R97, R98, R99, R100: 20K; R_0402_1005Metric
R34: 7.5; R_0402_1005Metric
R35, R38, R39, R42, R43, R46: 60R; R_0402_1005Metric
R36, R37, R40, R41, R44, R45: 150R; R_0402_1005Metric
R47, R48, R49, R50, R51, R52: 120R; R_0402_1005Metric
R61, R62, R63, R64, R65, R66, R67, R68, R69, R70, R71, R72: 0.1; R_0603_1608Metric
R73, R74, R79, R80: 22; R_0402_1005Metric
R89: 0; R_0603_1608Metric
R90, R91, R92, R93, R94, R95: 220; R_0402_1005Metric
R101, R103: 1K; R_0402_1005Metric
R102: 4.7K; R_0402_1005Metric
R104: 100K; R_0402_1005Metric
R105: 33R; R_0402_1005Metric
R106: 100R; R_0402_1005Metric
R107, R108: 80R; R_0402_1005Metric
R109, R110: 1.5K/0.5%; R_0402_1005Metric
R111: 240R 1%; R_0402_1005Metric
RN1, RN2, RN3, RN4: 49.9; R_Array_Convex_4x0402
RV1, RV5, RV6, RV7, RV8: 10K; Potentiometer_Bourns_TC33X_Vertical
RV2, RV3, RV4: 50K; Potentiometer_Bourns_TC33X_Vertical
U1, U12: XC6206P152MR; SOT-23-3
U2, U3: LT3045xMSE; MSOP-12-1EP_3x4mm_P0.65mm_EP1.65x2.85mm
U4: XC6206P302MR; SOT-23-3
U5, U6: ADA4800; DFN-6-1EP_1.6x1.6mm_P0.5mm_EP0.5x1.05mm
U7: AD9990; BGA-112_11x11_8.0x8.0mm
U8, U11: TPS72301; SOT-23-5_HandSoldering
U9: TMP1075DGK; VSSOP-8_3.0x3.0mm_P0.65mm
U10: KAI-1100x; KAI-1100X
U13: TLV76701DRVx; WSON-6-1EP_2x2mm_P0.65mm_EP1x1.6mm_ThermalVias
U14, U15, U16, U17, U18, U19: 74HC2G17; SC-74-6_1.5x2.9mm_P0.95mm
U20, U21, U22, U23: 1EDN7550B; SOT-23-6_Handsoldering
U24, U25, U26: IRF9389/7309; SOIC-8_3.9x4.9mm_P1.27mm
U27: XC7Z010-CLG400; Xilinx_CLG400
U28: W25Q128JVP; WSON-8-1EP_4x4mm_P0.8mm_EP1.98x3mm
U29: MT41K256M16HA; BGA-96_9.0x13.0mm_Layout2x3x16_P0.8mm
X1: 33.33MHz; Oscillator_SMD_Abracon_ASE-4Pin_3.2x2.5mm

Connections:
+1V0: C115.1, C116.1, C117.1, C119.1, C121.1, C122.1, C123.1, C124.1, C125.1, C128.1, C131.1, U27.G7 (VCCPINT[6]), U27.G11 (VCCBRAM[2]), U27.G13 (VCCINT[9]), U27.H10 (VCCBRAM[2]), U27.H12 (VCCINT[9]), U27.J7 (VCCPINT[6]), U27.J13 (VCCINT[9]), U27.K12 (VCCINT[9]), U27.L7 (VCCPINT[6]), U27.L13 (VCCINT[9]), U27.M12 (VCCINT[9]), U27.N7 (VCCPINT[6]), U27.N13 (VCCINT[9]), U27.P8 (VCCPINT[6]), U27.P12 (VCCINT[9]), U27.R7 (VCCPINT[6]), U27.R13 (VCCINT[9])
+1V5: C65.1, D12.2 (K), RV3.1, U12.2 (VO), U14.5 (VCC)
+1V8: C6.1, C27.2, C126.1, C127.1, C129.1, C130.1, C132.1, C133.1, C155.1, C156.1, C157.1, FB1.2, FB11.2, J2.30, U1.2 (VO), U7.H5 (DVDD), U27.F8 (VCCPAUX[5]), U27.F11 (VCCBATT_0), U27.G9 (VCCPAUX[5]), U27.H8 (VCCPAUX[5]), U27.J9 (VCCADC_0), U27.J11 (VCCAUX[6]), U27.K8 (VCCPAUX[5]), U27.L11 (VCCAUX[6]), U27.M8 (VCCPAUX[5]), U27.N9 (VCCAUX[6]), U27.N11 (VCCAUX[6]), U27.N19 (VCCO_34[6]), U27.P10 (VCCAUX[6]), U27.R9 (VCCAUX[6]), U27.R15 (VCCO_34[6]), U27.T18 (VCCO_34[6]), U27.V14 (VCCO_34[6]), U27.W17 (VCCO_34[6]), U27.Y20 (VCCO_34[6])
+1V35: C134.1, C136.1, C137.1, C138.1, C139.1, C140.1, C142.1, C143.1, C144.1, C145.1, C146.1, C147.1, C148.1, C149.1, C150.1, C151.1, C152.1, C153.1, J2.27, J2.28, R108.1, R109.1, U27.A3 (VCCO_DDR_502[10]), U27.D2 (VCCO_DDR_502[10]), U27.E5 (VCCO_DDR_502[10]), U27.G1 (VCCO_DDR_502[10]), U27.H4 (VCCO_DDR_502[10]), U27.L3 (VCCO_DDR_502[10]), U27.P2 (VCCO_DDR_502[10]), U27.R5 (VCCO_DDR_502[10]), U27.U1 (VCCO_DDR_502[10]), U27.V4 (VCCO_DDR_502[10]), U29.A1 (VDDQ), U29.A8 (VDDQ), U29.B2 (VDD), U29.C1 (VDDQ), U29.C9 (VDDQ), U29.D2 (VDDQ), U29.D9 (VDD), U29.E9 (VDDQ), U29.F1 (VDDQ), U29.G7 (VDD), U29.H2 (VDDQ), U29.H9 (VDDQ), U29.K2 (VDD), U29.K8 (VDD), U29.N1 (VDD), U29.N9 (VDD), U29.R1 (VDD), U29.R9 (VDD)
+2V: C53.1, C66.1, C67.1, C68.1, C69.1, C70.1, D11.2 (K), D13.2 (K), J1.3, RV2.1, RV4.1, U12.3 (VI), U15.5 (VCC), U16.5 (VCC), U17.5 (VCC), U18.5 (VCC), U19.5 (VCC)
+3V0: C8.1, C29.2, C30.2, C31.2, C32.2, C33.2, C34.2, C35.2, C77.2, FB2.1, FB3.1, FB4.1, R18.2, R85.2, R87.2, U4.2 (VO), U7.C2 (RGVDD_A), U7.C10 (RGVDD_B), U7.D3 (HVDD_A), U7.D9 (HVDD_B), U7.E4 (XVVDD), U7.J10 (DRVDD), U7.J11 (IOVDD)
+3V3: C110.2, C111.2, C112.2, C118.2, C120.2, C158.1, C159.1, C160.1, C161.1, C162.1, C163.1, J2.24, J2.25, R96.1, R101.1, R102.1, R104.1, R112.1, U9.8 (V+), U27.A13 (VCCO_MIO1_501[4]), U27.B6 (VCCO_MIO0_500[2]), U27.B16 (VCCO_MIO1_501[4]), U27.C19 (VCCO_35[6]), U27.D7 (VCCO_MIO0_500[2]), U27.D12 (VCCO_MIO1_501[4]), U27.E15 (VCCO_MIO1_501[4]), U27.F18 (VCCO_35[6]), U27.H14 (VCCO_35[6]), U27.J17 (VCCO_35[6]), U27.K6 (VCCO_0), U27.K20 (VCCO_35[6]), U27.M6 (CFGBVS_0), U27.M16 (VCCO_35[6]), U27.N6 (RSVDVCC3), U27.R6 (RSVDVCC2), U27.T6 (RSVDVCC1), U27.T8 (VCCO_13[4]), U27.U11 (VCCO_13[4]), U27.W7 (VCCO_13[4]), U27.Y10 (VCCO_13[4]), U28.8 (VCC), X1.1 (EN), X1.4 (Vdd)
+3V3A: C1.1, C7.1, J1.15, U1.3 (VI), U4.3 (VI)
+5V: C82.1, C90.2, C94.2, J1.28, J1.29, R16.2, U23.4 (VDD)
+8V: C81.1, C87.2, C91.2, C101.2, C104.2, C107.2, J1.19, J1.20, J1.21, R14.2, U20.4 (VDD), U24.3 (SP)
+15VL: C9.1, C16.1, C42.1, FB10.1, R5.1, R20.1, R22.1, R30.1, U2.10 (OUTS), U2.11 (OUT), U2.12 (OUT), U6.5 (VCC)
+15VR: C10.1, C15.1, FB5.1, R7.1, R19.1, R21.1, U3.10 (OUTS), U3.11 (OUT), U3.12 (OUT), U5.5 (VCC)
+16V: C2.1, C3.1, J1.13, J1.14, R9.2, U2.1 (IN), U2.2 (IN), U2.3 (IN), U2.4 (EN/UV), U3.1 (IN), U3.2 (IN), U3.3 (IN), U3.4 (EN/UV)
+16VD: C62.2, J1.5, Q1.4 (E2), R10.2, R57.1, U13.4 (EN), U13.6 (IN)
+DRAM_VREF: C135.1, C141.1, C153.2, C154.1, R109.2, R110.1, U27.H6 (PS_DDR_VREF0_502), U27.P6 (PS_DDR_VREF1_502), U29.H1 (VrefDQ), U29.M8 (VrefCA)
+VAB: C55.2, C56.2, D15.2 (A), R15.2, R56.1, U13.1 (OUT)
-3V5: C76.2, D12.1 (A), R54.1, RV3.3, U11.5 (OUT), U14.2 (GND)
-4V: C54.2, C71.2, C72.2, C73.2, C74.2, C75.2, C79.1, C83.1, C84.1, D11.1 (A), D13.1 (A), J1.7, J1.8, J1.27, R17.2, R53.1, R82.1, R84.1, RV2.3, RV4.3, U11.2 (IN), U15.2 (GND), U16.2 (GND), U17.2 (GND), U18.2 (GND), U19.2 (GND)
-9V: C78.2, C80.2, C88.1, C89.1, C90.1, C92.1, C93.1, C94.1, C102.2, C103.2, C105.1, C106.1, C108.1, C109.1, J1.22, J1.23, J1.24, R12.2, R77.1, R78.1, U21.2 (GND), U22.2 (GND), U23.2 (GND), U25.1 (SN), U26.1 (SN)
-9VA: J1.12, R13.2, R29.1, R34.1, U8.2 (IN)
-15V: C63.1, D14.2 (A), J1.1, R11.2, R59.2
/afe/AVDDA: C23.2, C24.2, U7.A1 (LDOOUT_A), U7.C4 (AVDD_A)
/afe/AVDDB: C25.2, C26.2, U7.A11 (LDOOUT_B), U7.C8 (AVDD_B)
/afe/AVSS: C36.2, C37.2, R27.1, U7.B3 (LDOVSS_A), U7.B9 (LDOVSS_B)
/afe/AVSSA: C11.2, C13.2, C15.2, C17.2, C18.2, C23.1, C24.1, C38.2, C39.2, R25.1, U5.2 (VEE), U5.7 (EPAD), U7.A3 (AVSS_A), U7.A5 (AVSS_A), U7.C5 (AVSS_A)
/afe/AVSSB: C12.2, C14.2, C16.2, C19.2, C20.2, C25.1, C26.1, C40.2, C41.2, R26.1, U6.2 (VEE), U6.7 (EPAD), U7.A7 (AVSS_B), U7.A9 (AVSS_B), U7.C7 (AVSS_B)
/afe/CLI: R23.2, U7.B5 (CLI)
/afe/CSI_D2_pre: RN1.8 (R1.2), U7.H6 (D0)
/afe/CSI_D3_pre: RN1.7 (R2.2), U7.J6 (D1)
/afe/CSI_D4_pre: RN1.5 (R4.2), U7.K6 (D2)
/afe/CSI_D5_pre: RN2.8 (R1.2), U7.L6 (D3)
/afe/CSI_D6_pre: RN2.6 (R3.2), U7.L7 (D4)
/afe/CSI_D7_pre: RN2.5 (R4.2), U7.K7 (D5)
/afe/CSI_D8_pre: RN1.6 (R3.2), U7.J7 (D6)
/afe/CSI_D9_pre: R28.1, U7.H7 (D7)
/afe/CSI_D10_pre: RN3.8 (R1.2), U7.L8 (D8)
/afe/CSI_D11_pre: RN3.7 (R2.2), U7.K8 (D9)
/afe/CSI_D12_pre: RN2.7 (R2.2), U7.J8 (D10)
/afe/CSI_D13_pre: RN3.6 (R3.2), U7.L9 (D11)
/afe/CSI_D14_pre: RN3.5 (R4.2), U7.K9 (D12)
/afe/CSI_D15_pre: RN4.7 (R2.2), U7.K10 (D13)
/afe/CSI_DCLK_pre: RN4.8 (R1.2), U7.L10 (DCLK)
/afe/CSI_HD_pre: RN4.5 (R4.2), U7.H11 (HD)
/afe/CSI_VD_pre: RN4.6 (R3.2), U7.H10 (VD)
/ccd/VDDL: C51.1, C52.1, FB10.2, U10.18 (VDDR)
/ccd/VDDR: C45.1, C48.1, FB5.2, U10.3 (VDDL)
/ccd/VOD: C44.2, FB6.1, FB7.1, R32.1, U8.5 (OUT)
/ccd/VOGL: C49.1, FB7.2, U10.40 (OGL)
/ccd/VOGR: C50.1, FB6.2, U10.21 (OGR)
/ccd/VRDL: C46.1, FB9.2, U10.38 (VRDL)
/ccd/VRDR: C47.1, FB8.2, U10.23 (VRDR)
/ccd_driver/H1BINL: R64.1, U15.4 (2Y)
/ccd_driver/H1BINR: R63.1, U15.6 (1Y)
/ccd_driver/H1BL: R68.1, U17.4 (2Y)
/ccd_driver/H1BR: R69.1, U18.6 (1Y)
/ccd_driver/H1S: C58.2, D13.3 (COM), RV4.2, U15.1 (1A), U15.3 (2A), U16.1 (1A), U17.3 (2A), U18.1 (1A), U19.3 (2A)
/ccd_driver/H1SL: R65.1, U16.6 (1Y)
/ccd_driver/H1SR: R72.1, U19.4 (2Y)
/ccd_driver/H2BL: R67.1, U17.6 (1Y)
/ccd_driver/H2BR: R70.1, U18.4 (2Y)
/ccd_driver/H2S: C59.2, D11.3 (COM), RV2.2, U16.3 (2A), U17.1 (1A), U18.3 (2A), U19.1 (1A)
/ccd_driver/H2SL: R66.1, U16.4 (2Y)
/ccd_driver/H2SR: R71.1, U19.6 (1Y)
/ccd_driver/RGS: C57.2, D12.3 (COM), RV3.2, U14.1 (1A), U14.3 (2A)
/ccd_driver/RL: R62.1, U14.4 (2Y)
/ccd_driver/RR: R61.1, U14.6 (1Y)
/ccd_driver_v/V1S: D20.3 (COM), R94.1, R95.2, U22.5 (OUT_SRC), U22.6 (OUT_SNK)
/ccd_driver_v/V2S: D19.3 (COM), R92.1, R93.2, U21.5 (OUT_SRC), U21.6 (OUT_SNK)
/ccd_driver_v/V23: D18.3 (COM), R90.1, R91.2, U20.5 (OUT_SRC), U20.6 (OUT_SNK)
/fpga_config/FPGA_DONE: D21.2 (A), R101.2, U27.R11 (DONE_0)
/fpga_config/FPGA_INIT_B: R102.2, U27.R10 (INIT_B_0)
/fpga_config/PS_CLK: R105.2, U27.E7 (PS_CLK_500)
/fpga_config/VCCPLL: C113.2, C114.2, FB11.1, U27.G8 (VCCPLL)
/fpga_ddr/DRAM_ADDR0: U27.N2 (PS_DDR_A0_502), U29.N3 (A0)
/fpga_ddr/DRAM_ADDR1: U27.K2 (PS_DDR_A1_502), U29.P7 (A1)
/fpga_ddr/DRAM_ADDR2: U27.M3 (PS_DDR_A2_502), U29.P3 (A2)
/fpga_ddr/DRAM_ADDR3: U27.K3 (PS_DDR_A3_502), U29.N2 (A3)
/fpga_ddr/DRAM_ADDR4: U27.M4 (PS_DDR_A4_502), U29.P8 (A4)
/fpga_ddr/DRAM_ADDR5: U27.L1 (PS_DDR_A5_502), U29.P2 (A5)
/fpga_ddr/DRAM_ADDR6: U27.L4 (PS_DDR_A6_502), U29.R8 (A6)
/fpga_ddr/DRAM_ADDR7: U27.K4 (PS_DDR_A7_502), U29.R2 (A7)
/fpga_ddr/DRAM_ADDR8: U27.K1 (PS_DDR_A8_502), U29.T8 (A8)
/fpga_ddr/DRAM_ADDR9: U27.J4 (PS_DDR_A9_502), U29.R3 (A9)
/fpga_ddr/DRAM_ADDR10: U27.F5 (PS_DDR_A10_502), U29.L7 (A10)
/fpga_ddr/DRAM_ADDR11: U27.G4 (PS_DDR_A11_502), U29.R7 (A11)
/fpga_ddr/DRAM_ADDR12: U27.E4 (PS_DDR_A12_502), U29.N7 (A12/~BC)
/fpga_ddr/DRAM_ADDR13: U27.D4 (PS_DDR_A13_502), U29.T3 (A13)
/fpga_ddr/DRAM_ADDR14: U27.F4 (PS_DDR_A14_502), U29.T7 (A14/NC)
/fpga_ddr/DRAM_BA0: U27.L5 (PS_DDR_BA0_502), U29.M2 (BA0)
/fpga_ddr/DRAM_BA1: U27.R4 (PS_DDR_BA1_502), U29.N8 (BA1)
/fpga_ddr/DRAM_BA2: U27.J5 (PS_DDR_BA2_502), U29.M3 (BA2)
/fpga_ddr/DRAM_CASB: U27.P5 (PS_DDR_CAS_B_502), U29.K3 (~CAS)
/fpga_ddr/DRAM_CKE: U27.N3 (PS_DDR_CKE_502), U29.K9 (CKE)
/fpga_ddr/DRAM_CKN: R106.2, U27.M2 (PS_DDR_CKN_502), U29.K7 (~CK)
/fpga_ddr/DRAM_CKP: R106.1, U27.L2 (PS_DDR_CKP_502), U29.J7 (CK)
/fpga_ddr/DRAM_CSB: U27.N1 (PS_DDR_CS_B_502), U29.L2 (~CS)
/fpga_ddr/DRAM_DATA0: U27.C3 (PS_DDR_DQ0_502), U29.H8 (DQ5)
/fpga_ddr/DRAM_DATA1: U27.B3 (PS_DDR_DQ1_502), U29.F2 (DQ2)
/fpga_ddr/DRAM_DATA2: U27.A2 (PS_DDR_DQ2_502), U29.G2 (DQ6)
/fpga_ddr/DRAM_DATA3: U27.A4 (PS_DDR_DQ3_502), U29.H3 (DQ4)
/fpga_ddr/DRAM_DATA4: U27.D3 (PS_DDR_DQ4_502), U29.F7 (DQ1)
/fpga_ddr/DRAM_DATA5: U27.D1 (PS_DDR_DQ5_502), U29.E3 (DQ0)
/fpga_ddr/DRAM_DATA6: U27.C1 (PS_DDR_DQ6_502), U29.H7 (DQ7)
/fpga_ddr/DRAM_DATA7: U27.E1 (PS_DDR_DQ7_502), U29.F8 (DQ3)
/fpga_ddr/DRAM_DATA8: U27.E2 (PS_DDR_DQ8_502), U29.C2 (DQ11)
/fpga_ddr/DRAM_DATA9: U27.E3 (PS_DDR_DQ9_502), U29.A2 (DQ13)
/fpga_ddr/DRAM_DATA10: U27.G3 (PS_DDR_DQ10_502), U29.A3 (DQ15)
/fpga_ddr/DRAM_DATA11: U27.H3 (PS_DDR_DQ11_502), U29.C3 (DQ9)
/fpga_ddr/DRAM_DATA12: U27.J3 (PS_DDR_DQ12_502), U29.A7 (DQ12)
/fpga_ddr/DRAM_DATA13: U27.H2 (PS_DDR_DQ13_502), U29.D7 (DQ8)
/fpga_ddr/DRAM_DATA14: U27.H1 (PS_DDR_DQ14_502), U29.B8 (DQ14)
/fpga_ddr/DRAM_DATA15: U27.J1 (PS_DDR_DQ15_502), U29.C8 (DQ10)
/fpga_ddr/DRAM_DQM0: U27.A1 (PS_DDR_DM0_502), U29.E7 (LDM)
/fpga_ddr/DRAM_DQM1: U27.F1 (PS_DDR_DM1_502), U29.D3 (UDM)
/fpga_ddr/DRAM_ODT: U27.N5 (PS_DDR_ODT_502), U29.K1 (ODT)
/fpga_ddr/DRAM_RASB: U27.P4 (PS_DDR_RAS_B_502), U29.J3 (~RAS)
/fpga_ddr/DRAM_RST: U27.B4 (PS_DDR_DRST_B_502), U29.T2 (~RESET)
/fpga_ddr/DRAM_SDQSN_0: U27.B2 (PS_DDR_DQS_N0_502), U29.G3 (~LDQS)
/fpga_ddr/DRAM_SDQSN_1: U27.F2 (PS_DDR_DQS_N1_502), U29.B7 (~UDQS)
/fpga_ddr/DRAM_SDQSP_0: U27.C2 (PS_DDR_DQS_P0_502), U29.F3 (LDQS)
/fpga_ddr/DRAM_SDQSP_1: U27.G2 (PS_DDR_DQS_P1_502), U29.C7 (UDQS)
/fpga_ddr/DRAM_WEB: U27.M5 (PS_DDR_WE_B_502), U29.L3 (~WE)
/fpga_io/PS_SRST_B: R112.2, U27.B10 (PS_SRST_B_501)
AFE_FDG: R80.1, U7.G4 (XV4)
AFE_H1: C58.1, U7.E1 (H1A)
AFE_H2: C59.1, U7.E2 (H2A)
AFE_RG: C57.1, U7.C1 (HL_A)
AFE_RST: U7.H8 (RSTB), U27.B20 (IO_L1N_T0_AD0N_35)
AFE_SCK: U7.E8 (SCK), U27.D18 (IO_L3N_T0_DQS_AD1N_35)
AFE_SDATA: U7.E9 (SDATA), U27.C20 (IO_L1P_T0_AD0P_35)
AFE_SL: U7.D7 (SL), U27.D19 (IO_L4P_T0_35)
AFE_STROBE: C60.2, C61.2, U7.G11 (GPO1)
AFE_V1: R74.1, U7.F3 (XV1)
AFE_V2: R73.1, U7.F2 (XV2)
AFE_V23: R79.1, U7.F1 (XV3)
CCDIN_L: U6.1 (IN), U10.19 (VOUTR)
CCDIN_R: U5.1 (IN), U10.2 (VOUTL)
CSI_D2: RN1.1 (R1.1), U27.K19 (IO_L10P_T1_AD11P_35)
CSI_D3: RN1.2 (R2.1), U27.J19 (IO_L10N_T1_AD11N_35)
CSI_D4: RN1.4 (R4.1), U27.J20 (IO_L17P_T2_AD5P_35)
CSI_D5: RN2.1 (R1.1), U27.H18 (IO_L14N_T2_AD4N_SRCC_35)
CSI_D6: RN2.3 (R3.1), U27.H20 (IO_L17N_T2_AD5N_35)
CSI_D7: RN2.4 (R4.1), U27.G19 (IO_L18P_T2_AD13P_35)
CSI_D8: RN1.3 (R3.1), U27.G20 (IO_L18N_T2_AD13N_35)
CSI_D9: R28.2, U27.F19 (IO_L15P_T2_DQS_AD12P_35)
CSI_D10: RN3.1 (R1.1), U27.F20 (IO_L15N_T2_DQS_AD12N_35)
CSI_D11: RN3.2 (R2.1), U27.E19 (IO_L5N_T0_AD9N_35)
CSI_D12: RN2.2 (R2.1), U27.E18 (IO_L5P_T0_AD9P_35)
CSI_D13: RN3.3 (R3.1), U27.D20 (IO_L4N_T0_35)
CSI_HSYNC: RN4.4 (R4.1), U27.M19 (IO_L7P_T1_AD2P_35)
CSI_PIXCLK: RN4.1 (R1.1), U27.M18 (IO_L8N_T1_AD10N_35)
CSI_VSYNC: RN4.3 (R3.1), U27.M20 (IO_L7N_T1_AD2N_35)
DSI_HS_CKN: R37.2, U27.U20 (IO_L15N_T2_DQS_34)
DSI_HS_CKP: R36.2, U27.T20 (IO_L15P_T2_DQS_34)
DSI_HS_D0N: R41.2, U27.Y18 (IO_L17P_T2_34)
DSI_HS_D0P: R40.2, U27.Y19 (IO_L17N_T2_34)
DSI_LP_CKN: R38.2, U27.V20 (IO_L16P_T2_34)
DSI_LP_CKP: R35.2, U27.R18 (IO_L20N_T3_34)
DSI_LP_D0N: R42.2, U27.Y17 (IO_L7N_T1_34)
DSI_LP_D0P: R39.2, U27.W19 (IO_L22N_T3_34)
FDG_CCD: R89.1, U10.22 (FD), U10.39 (FD)
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

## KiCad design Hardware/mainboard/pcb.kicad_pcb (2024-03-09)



Board: 4 copper layers, 71.6 x 73.2 mm, 198 parts (63 on the bottom side), 194 nets.

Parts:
C1, C8, C9, C69, C79, C95, C98, C99, C100, C101, C102: 22uF; C_0603_1608Metric
C2, C3, C11, C12, C13, C14, C16, C17, C19, C20, C33, C68, C82, C85, C86, C90, C91, C92, C105: 10uF; C_0603_1608Metric
C4, C6: 2.2uF; C_0402_1005Metric
C5, C37, C39, C41, C46, C49, C50, C53, C54, C56, C57, C59, C60, C62, C64, C88, C97: 220nF; C_0402_1005Metric
C7, C21, C23, C24, C70: 4.7uF; C_0402_1005Metric
C10, C22, C31, C40, C43, C44, C51, C52, C55, C58, C67, C71, C72, C73, C74, C75, C76, C77, C80, C83, C84, C87, C93, C94, C104: 100nF; C_0402_1005Metric
C15, C18: 1nF; C_0402_1005Metric
C25, C30, C63: 1uF; C_0402_1005Metric
C26, C27, C28, C29, C78: 18pF; C_0402_1005Metric
C32, C34, C35, C36, C45, C47, C48, C61, C66: 4.7uF; C_0603_1608Metric
C38, C65, C81: 470nF; C_0402_1005Metric
C42: 47uF; C_0603_1608Metric
C89: 1uF 25V; C_0603_1608Metric
C96: 47pF; C_0402_1005Metric
D1: B0530WS; D_SOD-323
D2: LED; LED_0603_1608Metric
D4: B0540W; D_SOD-323
FID1, FID2, FID3, FID4, FID5, FID6: Fiducial; Fiducial_0.75mm_Mask1.5mm
H1, H2, H3: MountingHole; MountingHole_2.2mm_M2_DIN965
J1, J9, J10, J11: 2.54mm pitch; PinSocket_1x02_P2.54mm_Vertical
J2: 02x04_P2.0; PinHeader_2x04_P2.00mm_Vertical_SMD
J3, J4: USB_C_Receptacle_USB2.0; USB_C_Receptacle_HRO_TYPE-C-31-M-12
J5: FPC 0.5mm Bottom Contact; Hirose_FH12-30S-0.5SH_1x30-1MP_P0.50mm_Horizontal
J6: Hirose_FH12-45S-0.5SH_1x45-1MP_P0.50mm_Horizontal_Reversed
J7: FFC 0.5mm Bottom Contact; Hirose_FH12-12S-0.5SH_1x12-1MP_P0.50mm_Horizontal
J8: AudioJack2; Jack_2.5mm_PJ_210A
J12, J13, J14, J15, J16, J17, J18, J19, J20, J21: LensMount; YTC1P-4520
L1, L2, L3, L4, L8, L9: FTC201610S4R7MBCA; L_Murata_DFE201610P
L5: 22uH; L_1212
L6: EXC14CE900U; L_CommonModeChoke_Panasonic_EXC14CE
L7: 120R; L_0603_1608Metric
MICRO_SD1: MICRO_SD(TFC-WPAPR-08); TFC-WPAPR-08
R1, R2, R24: 1K; R_0402_1005Metric
R3: 200K; R_0402_1005Metric
R4, R7, R9, R12, R13, R14, R15, R21, R23, R28, R31, R32, R36: 10K; R_0402_1005Metric
R5: 30mR; R_0603_1608Metric
R6: 1; R_0603_1608Metric
R8, R35: 200R; R_0402_1005Metric
R10: 4.3K; R_0402_1005Metric
R11, R16: 36K; R_0402_1005Metric
R17: 22; R_0402_1005Metric
R18: 100K; R_0402_1005Metric
R19, R20, R26, R27: 5.1K 1%; R_0402_1005Metric
R22: 49.9K 1%; R_0402_1005Metric
R25: 7.5; R_0402_1005Metric
R29, R30: 49.9K/1%; R_0402_1005Metric
R33: 200K/1%; R_0402_1005Metric
R34: 27K/1%; R_0402_1005Metric
SW1: SW_Push_LED; TM-007-D1-X
U1: AXP209; QFN-48-1EP_6x6mm_P0.4mm_EP4.3x4.3mm_ThermalVias
U2: IMXRT1050; BGA-196_14x14_12.0x12.0mm
U3: MT48LC16M16A2BG; BGA-54_9x9_8.0x8.0mm
U4: W25Q32JV; WSON-8-1EP_6x5mm_P1.27mm_EP3.4x4.3mm
U5: STM32G030F6Px; TSSOP-20_4.4x6.5mm_P0.65mm
U6: CAT4139; SOT-23-5
U7: FODM3023; SMDIP-4_W7.62mm
U8: USBLC6-2P6; SOT-666
U9, U11: MT9700; SOT-23-5
U10: SY8120; TSOT-23-6
U12: SY7208; SOT-23-6
Y1: 24MHz; Oscillator_SMD_Abracon_ASE-4Pin_3.2x2.5mm
Y2: 32.768K; Crystal_SMD_TXC_9HT11-2Pin_2.0x1.2mm_HandSoldering

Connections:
+1V0: C30.1, C38.1, C42.1, C46.1, C50.1, C54.1, C60.1, C65.1, C66.1, L4.1, U2.F6 (VDD_SOC_IN), U2.F7 (VDD_SOC_IN), U2.F8 (VDD_SOC_IN), U2.F9 (VDD_SOC_IN), U2.G6 (VDD_SOC_IN), U2.G9 (VDD_SOC_IN), U2.H6 (VDD_SOC_IN), U2.H9 (VDD_SOC_IN), U2.J5 (DCDC_SENSE), U2.J9 (VDD_SOC_IN)
+1V8: C14.2, C15.2, C35.1, C43.1, C51.1, C69.1, C70.1, C71.1, C72.1, C73.1, C74.1, C75.1, C76.1, C77.1, L2.2, U1.10 (DCDC2), U2.E6 (NVCC_EMC), U2.F5 (NVCC_EMC), U3.A7 (VDDQ), U3.A9 (VDD), U3.B3 (VDDQ), U3.C7 (VDDQ), U3.D3 (VDDQ), U3.E7 (VDD), U3.J9 (VDD)
+3.3VA: C25.2, J5.29, J5.30, U1.11 (LDO4)
+3V3: C17.2, C18.2, C31.1, C33.1, C34.1, C36.1, C40.1, C41.1, C44.1, C45.1, C48.1, C49.1, C52.1, C53.1, C57.1, C58.1, C81.2, C82.2, C83.1, C84.1, C86.2, C87.2, C91.1, C93.2, J6.7 (VCI), J6.8 (IOVCC), J7.11, L3.2, L5.1, R4.1, R13.1, R15.1, R16.1, R18.1, U1.17 (DCDC3), U2.E9 (NVCC_GPIO), U2.F10 (NVCC_GPIO), U2.J10 (NVCC_GPIO), U2.K4 (DCDC_IN_Q), U2.K5 (NVCC_SD1), U2.L1 (DCDC_IN), U2.L2 (DCDC_IN), U2.P12 (VDD_HIGH_IN), U4.8 (VCC), U5.4 (VDD), U6.5 (IN), U10.5 (IN), U11.5 (VIN)
+3V3_LENS: C102.1, J16.1, U11.1 (VOUT)
+5VP: C85.1, C90.1, J3.A4 (VBUS), J3.A9 (VBUS), J3.B4 (VBUS), J3.B9 (VBUS), U1.32 (ACIN), U1.33 (ACIN)
+5V_LENS: C105.2, D1.1 (K), J13.1, R33.2
+BATT: C1.1, C9.1, C10.1, C11.2, J7.8, J7.9, J7.10, R5.2, U1.38 (BAT), U1.39 (BAT), U1.42 (BATSENSE)
+CCDPWR: C99.1, J2.1, J2.3, J2.5, J2.7, U9.1 (VOUT)
+FAN: C8.2, C95.1, C96.2, C98.2, C100.2, C101.2, J1.1, J9.1, J10.1, J11.1, L8.2, R11.2
+RTC: C23.2, C64.1, U1.28 (LDO1), U2.M9 (VDD_SNVS_IN)
+VCCIO_SD: C21.2, C55.1, C61.1, U1.41 (LDO3), U2.J6 (NVCC_SD0)
+VSD: C22.2, C79.1, C80.1, MICRO_SD1.4 (VDD), U1.12 (LDO2)
/cpu/BOOTMODE0: R12.2, U2.F11 (GPIO_AD_B0_04)
/cpu/BOOTMODE1: R9.2, U2.G14 (GPIO_AD_B0_05)
/cpu/JTAG_MOD: R7.1, U2.F13 (GPIO_AD_B0_08)
/cpu/VDDA_1P1_CAP: C39.1, C47.1, U2.P10 (NVCC_PLL)
/cpu/VDDA_2P5_CAP: C32.1, C37.1, U2.P8 (VDD_HIGH_CAP)
/ddr/SDRAM_A0: U2.C2 (GPIO_EMC_09), U3.H7 (A0)
/ddr/SDRAM_A1: U2.G1 (GPIO_EMC_10), U3.H8 (A1)
/ddr/SDRAM_A2: U2.G3 (GPIO_EMC_11), U3.J8 (A2)
/ddr/SDRAM_A3: U2.H1 (GPIO_EMC_12), U3.J7 (A3)
/ddr/SDRAM_A4: U2.A6 (GPIO_EMC_13), U3.J3 (A4)
/ddr/SDRAM_A5: U2.B6 (GPIO_EMC_14), U3.J2 (A5)
/ddr/SDRAM_A6: U2.B1 (GPIO_EMC_15), U3.H3 (A6)
/ddr/SDRAM_A7: U2.A5 (GPIO_EMC_16), U3.H2 (A7)
/ddr/SDRAM_A8: U2.A4 (GPIO_EMC_17), U3.H1 (A8)
/ddr/SDRAM_A9: U2.B2 (GPIO_EMC_18), U3.G3 (A9)
/ddr/SDRAM_A10: U2.G2 (GPIO_EMC_23), U3.H9 (A10)
/ddr/SDRAM_A11: U2.B4 (GPIO_EMC_19), U3.G2 (A11)
/ddr/SDRAM_A12: U2.A3 (GPIO_EMC_20), U3.G1 (A12)
/ddr/SDRAM_BA0: U2.C1 (GPIO_EMC_21), U3.G7 (BA0)
/ddr/SDRAM_BA1: U2.F1 (GPIO_EMC_22), U3.G8 (BA1)
/ddr/SDRAM_CAS: U2.D3 (GPIO_EMC_24), U3.F7 (~CAS)
/ddr/SDRAM_CKE: U2.A2 (GPIO_EMC_27), U3.F3 (CKE)
/ddr/SDRAM_CLK: U2.B3 (GPIO_EMC_26), U3.F2 (CLK)
/ddr/SDRAM_CS0: U2.E1 (GPIO_EMC_29), U3.G9 (~CS)
/ddr/SDRAM_D0: U2.E3 (GPIO_EMC_00), U3.A8 (DQ0)
/ddr/SDRAM_D1: U2.F3 (GPIO_EMC_01), U3.B9 (DQ1)
/ddr/SDRAM_D2: U2.F4 (GPIO_EMC_02), U3.B8 (DQ2)
/ddr/SDRAM_D3: U2.G4 (GPIO_EMC_03), U3.C9 (DQ3)
/ddr/SDRAM_D4: U2.F2 (GPIO_EMC_04), U3.C8 (DQ4)
/ddr/SDRAM_D5: U2.G5 (GPIO_EMC_05), U3.D9 (DQ5)
/ddr/SDRAM_D6: U2.H5 (GPIO_EMC_06), U3.D8 (DQ6)
/ddr/SDRAM_D7: U2.H4 (GPIO_EMC_07), U3.E9 (DQ7)
/ddr/SDRAM_D8: U2.C6 (GPIO_EMC_30), U3.E1 (DQ8)
/ddr/SDRAM_D9: U2.C5 (GPIO_EMC_31), U3.D2 (DQ9)
/ddr/SDRAM_D10: U2.D5 (GPIO_EMC_32), U3.D1 (DQ10)
/ddr/SDRAM_D11: U2.C4 (GPIO_EMC_33), U3.C2 (DQ11)
/ddr/SDRAM_D12: U2.D4 (GPIO_EMC_34), U3.C1 (DQ12)
/ddr/SDRAM_D13: U2.E5 (GPIO_EMC_35), U3.B2 (DQ13)
/ddr/SDRAM_D14: U2.C3 (GPIO_EMC_36), U3.B1 (DQ14)
/ddr/SDRAM_D15: U2.E4 (GPIO_EMC_37), U3.A2 (DQ15)
/ddr/SDRAM_DM0: U2.H3 (GPIO_EMC_08), U3.E8 (LDQM)
/ddr/SDRAM_DM1: U2.D6 (GPIO_EMC_38), U3.F1 (UDQM)
/ddr/SDRAM_RAS: U2.D2 (GPIO_EMC_25), U3.F8 (~RAS)
/ddr/SDRAM_WE: U2.D1 (GPIO_EMC_28), U3.F9 (~WE)
/lcd/LEDA: C89.2, D4.1 (K), J6.45 (LEDA)
/lcd/LEDK: J6.43 (LEDK), R24.1, R25.1
/mcu/FLASH_SYNC: R8.1, U5.15 (PB0/PB1/PB2/PA8)
/mcu/LED: R35.1, U5.3 (PC15)
/power/PWRLED: R2.1, U1.18 (GPIO1)
/power/PWRON: R1.1, U1.47 (PWRON)
/power/VINT: C4.1, U1.26 (VINT), U1.27 (LDO1SET)
/usb/USB1_DN: J4.A7 (D-), J4.B7 (D-), L6.1, U8.1 (I/O1), U8.6 (I/O1)
/usb/USB1_DP: J4.A6 (D+), J4.B6 (D+), L6.2, U8.3 (I/O2), U8.4 (I/O2)
AFE_RST: J5.24, U2.L12 (GPIO_AD_B1_04)
AFE_SCK: J5.23, U2.K12 (GPIO_AD_B1_05)
AFE_SDATA: J5.22, U2.K11 (GPIO_AD_B1_01)
AFE_SL: J5.21, U2.J12 (GPIO_AD_B1_06)
AFE_SYNC: J5.25, U2.K10 (GPIO_AD_B1_07)
BODY_CS_LENS: J20.1, U5.8 (PA1)
BODY_VD_LENS: J15.1, U5.12 (PA5)
CPU_SWCLK: J3.B8 (SBU2), U2.F12 (GPIO_AD_B0_07)
CPU_SWDIO: J3.A8 (SBU1), U2.E14 (GPIO_AD_B0_06)
CSI_D2: J5.2, U2.B13 (GPIO_B1_10)
CSI_D3: J5.3, U2.C13 (GPIO_B1_11)
CSI_D4: J5.4, U2.J14 (GPIO_AD_B1_15)
CSI_D5: J5.5, U2.G12 (GPIO_AD_B1_14)
CSI_D6: J5.6, U2.H11 (GPIO_AD_B1_13)
CSI_D7: J5.7, U2.H12 (GPIO_AD_B1_12)
CSI_D8: J5.8, U2.J13 (GPIO_AD_B1_11)
CSI_D9: J5.9, U2.L13 (GPIO_AD_B1_10)
CSI_D10: J5.10, U2.M13 (GPIO_AD_B1_09)
CSI_D11: J5.11, U2.H13 (GPIO_AD_B1_08)
CSI_D12: J5.12, U2.A13 (GPIO_B1_09)
CSI_D13: J5.13, U2.A12 (GPIO_B1_08)
CSI_D14: J5.14, U2.B12 (GPIO_B1_07)
CSI_D15: J5.15, U2.C12 (GPIO_B1_06)
CSI_HSYNC: J5.19, U2.C14 (GPIO_B1_14)
CSI_PIXCLK: J5.17, U2.D13 (GPIO_B1_12)
CSI_VSYNC: J5.18, U2.D14 (GPIO_B1_13)
DCDC_EN: R28.2, U5.1 (PB7/PB8), U9.4 (EN)
FAN_EN: R36.2, U5.2 (PC14/PB9), U10.4 (~SHDN)
FAN_PWM: R29.2, U5.13 (PA6)
FLASH_SYNC_S: J8.S, U7.4
FLASH_SYNC_T: J8.T, U7.3
GND: C1.2, C2.2, C3.2, C4.2, C5.2, C6.2, C7.2, C8.1, C9.2, C10.2, C11.1, C12.1, C13.1, C14.1, C15.1, C16.1, C17.1, C18.1, C19.1, C20.1, C21.1, C22.1, C23.1, C24.1, C25.1, C26.2, C27.2, C28.1, C29.1, C30.2, C31.2, C32.2, C33.2, C34.2, C35.2, C36.2, C37.2, C38.2, C39.2, C40.2, C41.2, C42.2, C43.2, C44.2, C45.2, C46.2, C47.2, C48.2, C49.2, C50.2, C51.2, C52.2, C53.2, C54.2, C55.2, C56.2, C57.2, C58.2, C59.2, C60.2, C61.2, C62.2, C63.2, C64.2, C65.2, C66.2, C67.2, C68.2, C69.2, C70.2, C71.2, C72.2, C73.2, C74.2, C75.2, C76.2, C77.2, C78.2, C79.2, C80.2, C81.1, C82.1, C83.2, C84.2, C85.2, C86.1, C87.1, C88.1, C89.1, C90.2, C91.2, C92.2, C93.1, C95.2, C97.1, C98.1, C99.2, C100.1, C101.1, C102.2, C104.1, C105.1, D2.1 (K), J1.2, J2.2, J2.4, J2.6, J2.8, J3.A1 (GND), J3.A12 (GND), J3.B1 (GND), J3.B12 (GND), J3.S1 (SHIELD), J4.A1 (GND), J4.A12 (GND), J4.B1 (GND), J4.B12 (GND), J4.S1 (SHIELD), J5.1, J5.16, J5.20, J5.28, J5.MP (MountPin), J6.5 (GND), J6.6 (GND), J7.5, J7.6, J7.7, J7.12, J7.MP (MountPin), J9.2, J10.2, J11.2, J12.1, J14.1, MICRO_SD1.6 (VSS), MICRO_SD1.10, MICRO_SD1.11, MICRO_SD1.12, MICRO_SD1.13, R3.2, R7.2, R9.1, R10.1, R12.1, R14.1, R19.2, R20.2, R21.2, R25.2, R26.2, R27.2, R28.1, R31.1, R32.1, R34.1, R36.1, SW1.1, SW1.3 (K), U1.4 (~OE), U1.6 (~VBUSEN), U1.9 (PGND2), U1.16 (PGND3), U1.22 (AGND), U1.46 (PGND_CHG), U1.49 (EP), U2.A1 (VSS), U2.A14 (VSS), U2.B5 (VSS), U2.B10 (VSS), U2.E2 (VSS), U2.E13 (VSS), U2.G7 (VSS), U2.G8 (VSS), U2.H7 (VSS), U2.H8 (VSS), U2.J7 (VSS), U2.J8 (VSS), U2.K2 (VSS), U2.K6 (TESTMODE), U2.K9 (NGND_KEL0), U2.K13 (VSS), U2.L9 (VSS), U2.N1 (DCDC_GND), U2.N2 (DCDC_GND), U2.N5 (VSS), U2.N8 (VSS), U2.P1 (VSS), U2.P14 (VSS), U3.A1 (GND), U3.A3 (GNDQ), U3.B7 (GNDQ), U3.C3 (GNDQ), U3.D7 (GNDQ), U3.E3 (GND), U4.4 (GND), U4.9 (EP), U5.5 (VSS), U6.2 (GND), U7.2, U8.2 (GND), U9.2 (GND), U10.2 (GND), U11.2 (GND), U12.2 (GND), Y1.2, Y1.4
GRIP_IO0: J7.1, U2.K14 (GPIO_AD_B0_12)
GRIP_IO1: J7.2, U2.L14 (GPIO_AD_B0_13)
GRIP_IO2: J7.3, U2.H14 (GPIO_AD_B0_14)
GRIP_IO3: J7.4, U2.J11 (GPIO_AD_B1_00)
I2C_SCL: J5.26, R15.2, U1.2 (SCK), U2.M3 (GPIO_SD_B1_02), U5.16 (PA11/PA9)
I2C_SDA: J5.27, R13.2, U1.1 (SDA), U2.P2 (GPIO_SD_B1_04), U5.17 (PA12/PA10)
IPSOUT: C3.1, C5.1, C13.2, C16.2, C19.2, C24.2, C104.2, L9.1, R6.1, U1.7 (VIN2), U1.14 (VIN3), U1.21 (APS), U1.29 (DC3SET), U1.34 (IPSOUT), U1.35 (IPSOUT), U1.40 (LDO3IN), U1.44 (VIN_CHG), U9.5 (VIN), U12.4 (EN), U12.5 (IN)
LCD_CLK: J6.39 (PCLK), U2.D7 (GPIO_B0_00)
LCD_CS: J6.12 (CS), U2.B14 (GPIO_B1_15)
LCD_D0: J6.35 (B2), U2.C8 (GPIO_B0_04)
LCD_D1: J6.34 (B3), U2.B8 (GPIO_B0_05)
LCD_D2: J6.33 (B4), U2.A8 (GPIO_B0_06)
LCD_D3: J6.32 (B5), U2.A9 (GPIO_B0_07)
LCD_D4: J6.31 (B6), J6.37 (B0), U2.B9 (GPIO_B0_08)
LCD_D5: J6.30 (B7), J6.36 (B1), U2.C9 (GPIO_B0_09)
LCD_D6: J6.27 (G2), U2.D9 (GPIO_B0_10)
LCD_D7: J6.26 (G3), U2.A10 (GPIO_B0_11)
LCD_D8: J6.25 (G4), U2.C10 (GPIO_B0_12)
LCD_D9: J6.24 (G5), U2.D10 (GPIO_B0_13)
LCD_D10: J6.23 (G6), J6.29 (G0), U2.E10 (GPIO_B0_14)
LCD_D11: J6.22 (G7), J6.28 (G1), U2.E11 (GPIO_B0_15)
LCD_D12: J6.19 (R2), U2.A11 (GPIO_B1_00)
LCD_D13: J6.18 (R3), U2.B11 (GPIO_B1_01)
LCD_D14: J6.17 (R4), U2.C11 (GPIO_B1_02)
LCD_D15: J6.16 (R5), U2.D11 (GPIO_B1_03)
LCD_D16: J6.15 (R6), J6.21 (R0), U2.E12 (GPIO_B1_04)
LCD_D17: J6.14 (R7), J6.20 (R1), U2.D12 (GPIO_B1_05)
LCD_DE: J6.38 (DE), U2.E7 (GPIO_B0_01)
LCD_EN: R21.1, U2.C7 (GPIO_EMC_41), U6.4 (~SHDN)
LCD_HSYNC: J6.40 (HSYNC), U2.E8 (GPIO_B0_02)
LCD_MOSI: J6.10 (SDI), U2.H10 (GPIO_AD_B0_01)
LCD_PWM: R22.2, U2.F14 (GPIO_AD_B0_09)
LCD_RST: J6.13 (RESET), U2.G11 (GPIO_AD_B0_03)
LCD_SCLK: J6.11 (SCL), U2.M14 (GPIO_AD_B0_00)
LCD_VSYNC: J6.41 (VSYNC), U2.D8 (GPIO_B0_03)
LENS_CS_BODY: J17.1, U5.7 (PA0)
LENS_DET: J21.1, U5.20 (PB3/PB4/PB5/PB6)
LENS_PWR_EN: R31.2, U5.11 (PA4), U11.4 (EN)
LENS_RXD: J18.1, U5.10 (PA3)
LENS_TXD: J19.1, U5.9 (PA2)
MCU_SWCLK: J4.B8 (SBU2), U5.19 (PA14/PA15)
MCU_SWDIO: J4.A8 (SBU1), U5.18 (PA13)
unnamed: C88.2, R22.1, R23.2
unnamed: C97.2, R29.1, R30.2
unnamed: D1.2 (A), L9.2, U12.1 (SW)
unnamed: D2.2 (A), R35.2
unnamed: D4.2 (A), L5.2, U6.1 (SW)
unnamed: J3.A5 (CC1), R19.1
unnamed: J3.B5 (CC2), R20.1
unnamed: J4.A5 (CC1), R26.1
unnamed: J4.B5 (CC2), R27.1
unnamed: L4.2, U2.M1 (DCDC_LP), U2.M2 (DCDC_LP)
unnamed: C78.1, MICRO_SD1.5 (CLK/SCLK), R17.1
unnamed: R1.2, SW1.2
unnamed: R8.2, U7.1
unnamed: R2.2, SW1.4 (A)
unnamed: R3.1, U1.23 (BIAS)
unnamed: C12.2, L1.2, R5.1, U1.43 (CHSENSE)
unnamed: C7.1, U1.19 (GPIO0/LDOIO0)
unnamed: C20.2, R6.2, U1.13 (LDO24IN)
unnamed: L2.1, U1.8 (LX2)
unnamed: L3.1, U1.15 (LX3)
unnamed: L1.1, U1.45 (LX_CHG)
unnamed: C6.1, U1.24 (VREF)
unnamed: C28.2, U2.N9 (RTC_XTALI), Y2.1
unnamed: C29.2, U2.P9 (RTC_XTALO), Y2.2
unnamed: C26.1, U2.P11 (XTALI), Y1.1
unnamed: C27.1, U2.N11 (XTALO), Y1.3
unnamed: C62.1, R16.2, U2.K3 (DCDC_PSWITCH)
unnamed: C56.1, C63.1, U2.N14 (VDDA_ADC_3P3)
unnamed: C59.1, U2.M10 (VDD_SNVS_CAP)
unnamed: C67.1, C68.1, U2.K8 (VDD_USB_CAP)
unnamed: R23.1, R24.2, U6.3 (FB)
unnamed: J4.A4 (VBUS), J4.A9 (VBUS), J4.B4 (VBUS), J4.B9 (VBUS), L7.2, U8.5 (VBUS)
unnamed: R10.2, U9.3 (SET)
unnamed: C94.2, U10.1 (BS)
unnamed: C96.1, R11.1, R14.2, R30.1, U10.3 (FB)
unnamed: C94.1, L8.1, U10.6 (SW)
unnamed: R32.2, U11.3 (SET)
unnamed: R33.1, R34.2, U12.3 (FB)
PWROK: R4.2, U1.25 (PWROK), U2.M7 (POR_B), U5.6 (NRST)
QSPI_DATA0: U2.P3 (GPIO_SD_B1_08), U4.5 (DI(IO0))
QSPI_DATA1: U2.N4 (GPIO_SD_B1_09), U4.2 (DO(IO1))
QSPI_DATA2: U2.P4 (GPIO_SD_B1_10), U4.3 (IO2)
QSPI_DATA3: U2.P5 (GPIO_SD_B1_11), U4.7 (IO3)
QSPI_SCLK: U2.L4 (GPIO_SD_B1_07), U4.6 (CLK)
QSPI_SS0: R18.2, U2.L3 (GPIO_SD_B1_06), U4.1 (~CS)
SD1_CLK: R17.2, U2.J3 (GPIO_SD_B0_01)
SD1_CMD: MICRO_SD1.3 (CMD/DI), U2.J4 (GPIO_SD_B0_00)
SD1_DATA0: MICRO_SD1.7 (DAT0/DO), U2.J1 (GPIO_SD_B0_02)
SD1_DATA1: MICRO_SD1.8 (DAT1/RES), U2.K1 (GPIO_SD_B0_03)
SD1_DATA2: MICRO_SD1.1 (DAT2/RES), U2.H2 (GPIO_SD_B0_04)
SD1_DATA3: MICRO_SD1.2 (CD/DAT3/CS), U2.J2 (GPIO_SD_B0_05)
USB_DN: L6.4, U2.M8 (USB_OTG1_DN)
USB_DP: L6.3, U2.L8 (USB_OTG1_DP)
VBUS: C2.1, C92.1, L7.1, U1.31 (VBUS), U2.N6 (USB_OTG1_VBUS)

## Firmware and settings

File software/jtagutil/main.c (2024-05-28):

//
// Sitina JTAG Untility
//
// Copyright 2024 Wenting Zhang <zephray@outlook.com>
//
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
// Contains code from:
// - https://stackoverflow.com/questions/6947413/how-to-open-read-and-write-
//   from-serial-port-in-c
#include <stdio.h> 
#include <stdlib.h> 
#include <string.h> 
#include <unistd.h>
#include <assert.h>
#include <stdbool.h>
#include <fcntl.h> 
#include <termios.h>
#include <time.h>
#include <signal.h>
#include <math.h>
#include <netdb.h> 
#include <netinet/in.h> 
#include <sys/socket.h> 
#include <sys/types.h> 

#define PORT            2542
#define MCU_MAX_SIZE    1024 // Max size the MCU can handle

#define ASSERT(x, s)   { if (!(x)) { perror(s); exit(1); } }
#define GET_TIME()   { time(&rawtime); timeinfo = localtime(&rawtime); \
    sprintf(timestr, "%02d:%02d:%02d", timeinfo->tm_hour, \
    timeinfo->tm_min, timeinfo->tm_sec); }

typedef enum {
    TOK_NONE, TOK_GETINFO, TOK_SETTCK, TOK_SHIFT
} tok_t;

static int sockfd, connfd, serialfd;
static int max_packet_size = 0;

static bool fd_getbuf(int connfd, char *buf, int bufsize, char stopchar) {
    int i;
    for (i = 0; i < bufsize - 1; i++) {
        if (read(connfd, &buf[i], 1) != 1)
            return false;
        if (buf[i] == stopchar)
            break;
    }
    buf[i + 1] = '\0';
    return true;
}

static bool fd_trywrite(int connfd, char *buf, int requestdsize) {
    int remaining = requestdsize;
    int byteswritten = 0;
    while (remaining > 0) {
        ssize_t result = write(connfd, &buf[byteswritten], remaining);
        if (result >= 0) {
            byteswritten += result;
            remaining -= result;
        }
        else {
            return false;
        }
    }
    return true;
}


static bool fd_tryread(int connfd, char *buf, int requestdsize) {
    int remaining = requestdsize;
    int bytesread = 0;
    while (remaining > 0) {
        ssize_t result = read(connfd, &buf[bytesread], remaining);
        if (result >= 0) {
            bytesread += result;
            remaining -= result;
        }
        else {
            return false;
        }
    }
    return true;
}

static bool xvc_getcmd(int connfd, tok_t *token) {
    char cmd[12];
    if (!fd_getbuf(connfd, cmd, sizeof(cmd), ':'))
        return false;
    if (memcmp(cmd, "getinfo:", 8) == 0)
        *token = TOK_GETINFO;
    else if (memcmp(cmd, "settck:", 7) == 0)
        *token = TOK_SETTCK;
    else if (memcmp(cmd, "shift:", 6) == 0)
        *token = TOK_SHIFT;
    else
        *token = TOK_NONE;
    return true;
}

static uint32_t getuint32(uint8_t *buf) {
    return buf[0] | (buf[1] << 8) | (buf[2] << 16) | (buf[3] << 24);
}

static int set_interface_attribs(int fd, int speed, int parity) {
    struct termios tty;
    int result = tcgetattr(fd, &tty);
    ASSERT(result == 0, "Error during tcgetattr");

    cfsetospeed(&tty, speed);
    cfsetispeed(&tty, speed);

    tty.c_cflag = (tty.c_cflag & ~CSIZE) | CS8;     // 8-bit chars
    // disable IGNBRK for mismatched speed tests; otherwise receive break
    // as \000 chars
    tty.c_iflag &= ~IGNBRK;         // disable break processing
    tty.c_lflag = 0;                // no signaling chars, no echo,
                                    // no canonical processing
    tty.c_oflag = 0;                // no remapping, no delays
    tty.c_cc[VMIN]  = 0;            // read doesn't block
    tty.c_cc[VTIME] = 5;            // 0.5 seconds read timeout

    tty.c_iflag &= ~(IXON | IXOFF | IXANY); // shut off xon/xoff ctrl

    tty.c_cflag |= (CLOCAL | CREAD);// ignore modem controls,
                                    // enable reading
    tty.c_cflag &= ~(PARENB | PARODD);      // shut off parity
    tty.c_cflag |= parity;
    tty.c_cflag &= ~CSTOPB;
    tty.c_cflag &= ~CRTSCTS;

    result = tcsetattr(fd, TCSANOW, &tty);
    ASSERT(result == 0, "Error during tcsetattr");

    return 0;
}

static void set_blocking(int fd, int should_block) {
    struct termios tty;
    int result;
    memset(&tty, 0, sizeof tty);
    result = tcgetattr(fd, &tty);
    ASSERT(result == 0, "Error during tcgetattr");

    tty.c_cc[VMIN]  = should_block ? 1 : 0;
    tty.c_cc[VTIME] = 10;

    result = tcsetattr(fd, TCSANOW, &tty);
    ASSERT(result == 0, "Error during tcsetattr");
}


static void cleanup(void) {
    printf("Max packet size ever seen: %d bytes\n", max_packet_size);
    if (connfd)
        close(connfd);
    if (sockfd)
        close(sockfd);
    if (serialfd)
        close(serialfd);
}

void sigint_handler(int dummy) {
    cleanup();
    exit(0);
}

uint64_t time_in_ms(void) {
    long            ms; // Milliseconds
    time_t          s;  // Seconds
    struct timespec spec;

    clock_gettime(CLOCK_REALTIME, &spec);

    s  = spec.tv_sec;
    ms = round(spec.tv_nsec / 1.0e6); // Convert nanoseconds to milliseconds
    if (ms > 999) {
        s++;
        ms = 0;
    }

    return (uint64_t)s * 1000 + ms;
}

int main()  {
    int cli_len, result;
    struct sockaddr_in serv_addr, cli_addr;
    time_t rawtime;
    struct tm * timeinfo;
    char timestr[10];
    uint8_t buf[1024]; // Generic buffer

    char *serialport = "/dev/ttyACM0";

    printf("Sitina JTAG Debug Bridge\n");

    signal(SIGINT, sigint_handler);

    serialfd = open(serialport, O_RDWR | O_NOCTTY | O_SYNC);
    ASSERT(serialfd >= 0, "Failed to open serial port");

    set_interface_attribs(serialfd, B921600, 0);
    set_blocking(serialfd, 1); // blocking

    bzero(&serv_addr, sizeof(serv_addr));

    sockfd = socket(AF_INET, SOCK_STREAM, 0);
    ASSERT(sockfd != -1, "Socket creation failed");

    serv_addr.sin_family = AF_INET;
    serv_addr.sin_addr.s_addr = htonl(INADDR_ANY);
    serv_addr.sin_port = htons(PORT);

    result = bind(sockfd, (struct sockaddr *)&serv_addr, sizeof(serv_addr));
    ASSERT(result == 0, "Socket bind failed");

    result = listen(sockfd, 5);
    ASSERT(result == 0, "Listen failed");

    cli_len = sizeof(cli_addr);

    while (1) {
        connfd = accept(sockfd, (struct sockaddr *)&cli_addr, &cli_len);
        ASSERT(connfd >= 0, "Accept failed");

        GET_TIME();
        printf("[%s] Accepted connection\n", timestr);

        while (1) {
            tok_t token;
            if (!xvc_getcmd(connfd, &token))
                break;
            if (token == TOK_GETINFO) {
                GET_TIME();
                printf("[%s] Received Getinfo\n", timestr);
                // Send to MCU
                if (!fd_trywrite(serialfd, "getinfo:", 8))
                    goto serialfail;
                if (!fd_getbuf(serialfd, buf, sizeof(buf), '\n'))
                    goto serialfail;
                GET_TIME();
                printf("[%s] MCU returned info %s", timestr, buf);

                if (write(connfd, buf, strlen(buf)) != strlen(buf))
                    break;
            }
            else if (token == TOK_SETTCK) {
                uint32_t period;
                if (read(connfd, buf, 4) != 4)
                    break;
                period = getuint32(buf);
                GET_TIME();
                printf("[%s] Set TCK frequency to %d kHz\n",
                    timestr, 1000000 / period);
                if (!fd_trywrite(serialfd, "settck:", 7))
                    goto serialfail;
                if (!fd_trywrite(serialfd, buf, 4))
                    goto serialfail;
                if (!fd_tryread(serialfd, buf, 4))
                    goto serialfail;
                period = getuint32(buf);
                GET_TIME();
                printf("[%s] Actual TCK frequency %d kHz\n",
                    timestr, 1000000 / period);
                if (write(connfd, buf, 4) != 4)
                    break;
            }
            else if (token == TOK_SHIFT) {
                uint32_t num_bits;
                if (read(connfd, buf, 4) != 4)
                    break;
                num_bits = getuint32(buf);
                uint32_t num_bytes = (num_bits + 7) / 8;
                GET_TIME();
                printf("[%s] Shift %d bits (%d bytes)\n",
                    timestr, num_bits, num_bytes);
                uint8_t *tms_buf = malloc(num_bytes);
                uint8_t *tdi_buf = malloc(num_bytes);
                uint8_t *tdo_buf = malloc(num_bytes);
                ASSERT(tms_buf, "Allocation failed");
                ASSERT(tdi_buf, "Allocation failed");
                ASSERT(tdo_buf, "Allocation failed");
                if (read(connfd, tms_buf, num_bytes) != num_bytes)
                    break;
                if (read(connfd, tdi_buf, num_bytes) != num_bytes)
                    break;

                int remaining = num_bytes;
                if (num_bytes > max_packet_size)
                    max_packet_size = num_bytes;
                int pos = 0;
                while (remaining > 0) {
                    int size = (remaining > MCU_MAX_SIZE) ?
                        MCU_MAX_SIZE : remaining;
                    uint64_t start_ms = time_in_ms();
                    if (!fd_trywrite(serialfd, "shift:", 6))
                        goto serialfail;
                    if (!fd_trywrite(serialfd, buf, 4))
                        goto serialfail;
                    uint64_t ms1 = time_in_ms();
                    if (!fd_trywrite(serialfd, &tms_buf[pos], size))
                        goto serialfail;
                    if (!fd_trywrite(serialfd, &tdi_buf[pos], size))
                        goto serialfail;
                    uint64_t ms2 = time_in_ms();
                    if (!fd_tryread(serialfd, &tdo_buf[pos], size))
                        goto serialfail;
                    uint64_t ms3 = time_in_ms();
                    printf("%d ms + %d ms + %d ms = %d ms to send %d bytes (%.1f KB/s)\n",
                        (int)(ms1 - start_ms), (int)(ms2 - ms1), (int)(ms3 - ms2),
                        (int)(ms3 - start_ms), size, (float)size / (ms3 - start_ms));
                    pos += size;
                    remaining -= size;
                }

                if (write(connfd, tdo_buf, num_bytes) != num_bytes)
                    break;
                // Potential memory leak here, not a big issue hopefully
                free(tms_buf);
                free(tdi_buf);
                free(tdo_buf);
            }
        }

        close(connfd);
        printf("Closed connection\n");
    }
    goto exit;

serialfail:
    fprintf(stderr, "Failed reading from /writing to serial port\n");

exit:
    cleanup();

    // Not reachable
    //close(sockfd);

}

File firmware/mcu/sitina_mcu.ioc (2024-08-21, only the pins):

Mcu.UserName=STM32G030K6Tx
PA0.Signal=GPIO_Input
PA1.Signal=GPIO_Output
PA10.Signal=I2C1_SDA
PA13.Signal=SYS_SWDIO
PA14-BOOT0.Signal=SYS_SWCLK
PA15.Signal=GPIO_Input
PA2.Signal=USART2_TX
PA3.Signal=USART2_RX
PA4.Signal=GPIO_Output
PA5.Signal=SPI1_SCK
PA6.Signal=SPI1_MISO
PA7.Signal=SPI1_MOSI
PA8.Signal=GPIO_Input
PA9.Signal=I2C1_SCL
PB0.Signal=GPIO_Output
PB1.Signal=GPIO_Output
PB2.Signal=GPIO_Output
PB3.Signal=S_TIM1_CH2
PB4.Signal=S_TIM3_CH1
PB5.Signal=GPIO_Output
PB6.Signal=GPIO_Output
PB7.Signal=GPIO_Output
PB8.Signal=GPIO_Output
PB9.Signal=GPIO_Output

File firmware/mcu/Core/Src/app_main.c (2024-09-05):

//
// Sitina 1
// Copyright 2024 Wenting Zhang
//
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
// File : app_main.c
// Brief: Application main
//
#include "stm32g0xx_hal.h"
#include <stdio.h>
#include <string.h>
#include <stdbool.h>
#include "app_main.h"
#include "power.h"
#include "lcd.h"
#include "key.h"
#include "mcusvc.h"

static bool power_on = false;
static volatile bool lcd_vcom_update_req = false;

static volatile bool tick_60hz = false;
static volatile bool tick_120hz = false;
static volatile bool tick_1hz = false;

void HAL_RTCEx_WakeUpTimerEventCallback(RTC_HandleTypeDef *hrtc)
{
    UNUSED(hrtc);
    lcd_vcom_update_req = true;
}

void app_systick(void) {
    static uint32_t tick = 0;
    tick ++;
    if (tick % 8 == 0) {
        tick_120hz = true; // actually 125Hz
    }
    if (tick % 16 == 0) {
        tick_60hz = true;
    }
    if (tick % 1000 == 0) {
        tick_1hz = true;
    }
}

void app_init(void) {
    // First booting up
    // Initialize always ON sections
	if (__HAL_PWR_GET_FLAG(PWR_FLAG_SB) != RESET) {
		// Waked up from standby, skip LCD initialization
		__HAL_PWR_CLEAR_FLAG(PWR_FLAG_SB);
		lcd_stby_resume();
		lcd_vcom_update_req = true;
	}
	else {
		lcd_init();
		lcd_disp_string(0, 0, "Sitina 1");
		lcd_disp_string(0, 12, "EC VER 1.0");
		lcd_stby_update();
	}
    key_init();
    mcusvc_init();
}

void app_tick(void) {
    if (power_on) {
        // Do things during power on

        // Blink LED
        if (tick_1hz) {
            tick_1hz = false;
            // Nothing?
        }

        if (tick_60hz) {
            tick_60hz = false;
            lcd_schedule_com_inversion();

            static uint16_t keys_last = 0xffff;
            uint16_t keys = key_get_buttons();
            if (keys_last != keys) {
                keys_last = keys;
                if (keys & KEY_FN1_MASK)
                    lcd_disp_string(0, 0, "FN1    ");
                else if (keys & KEY_FN2_MASK)
                    lcd_disp_string(0, 0, "FN2    ");
                else if (keys & KEY_FN3_MASK)
                    lcd_disp_string(0, 0, "FN3    ");
                else if (keys & KEY_FN4_MASK)
                    lcd_disp_string(0, 0, "FN4    ");
                else if (keys & KEY_SHUTTER_MASK)
                    lcd_disp_string(0, 0, "SHUTTER");
                else if (keys & KEY_UP_MASK)
                    lcd_disp_string(0, 0, "UP     ");
                else if (keys & KEY_LEFT_MASK)
                    lcd_disp_string(0, 0, "LEFT   ");
                else if (keys & KEY_RIGHT_MASK)
                    lcd_disp_string(0, 0, "RIGHT  ");
                else if (keys & KEY_DOWN_MASK)
                    lcd_disp_string(0, 0, "DOWN   ");
                else if (keys & KEY_FN5_MASK)
                    lcd_disp_string(0, 0, "FN5    ");
                else if (keys & KEY_FN6_MASK)
                    lcd_disp_string(0, 0, "FN6    ");
                else
                    lcd_disp_string(0, 0, "       ");
                lcd_schedule_update();
            }
            static int8_t rotenc_last = 0x7f;
            int8_t rotenc = key_get_rotenc();
            if (rotenc_last != rotenc) {
                rotenc_last = rotenc;
                uint8_t rotenc_abs;
                if (rotenc < 0) {
                    rotenc_abs = 0 - rotenc;
                    lcd_disp_char(0, 12, '-');
                }
                else {
                    rotenc_abs = rotenc;
                    lcd_disp_char(0, 12, ' ');
                }
                lcd_disp_char(8, 12, '0' + (rotenc_abs / 10));
                lcd_disp_char(16, 12, '0' + (rotenc_abs % 10));
                lcd_schedule_update();
            }

            if (power_get_pek()) {
            	power_power_off_pmic(); // TODO: This ideally should have been handled by Zynq
            }
        }

        if (tick_120hz) {
            tick_120hz = false;
            lcd_update(); // This also scans the key
        }

        // Handle command from Zynq
        mcusvc_tick();

        // Detect power down
        if (!power_is_power_on()) {
            // Reset all GPIOs

            // Disable WDT

            // Power down
            power_lcd_off();
            power_fpga_reset();
            power_power_off_ccd();
            power_power_off_lens();

            power_on = false;
        }
        // Feed WDT

    }
    else {
        // Currently not ON, check if it's ON due to being powered ON or RTC
        // tick for screen update
        if (lcd_vcom_update_req) {
            lcd_stby_com_inversion();
        }

        if (power_is_power_on()) {
            // POWER ON
            power_on = true;
            // Initialize PMIC
            power_pmic_init();
            // Clear LCD
            lcd_clear(0);
            // Wait
            HAL_Delay(100);
            // Power ON CCD (test for now)
            power_power_on_ccd();
            // Wait
            HAL_Delay(100);
            // Release FPGA
            power_release_fpga_reset();
        }
        else {
            // Go back to sleep
        	HAL_PWR_EnterSTANDBYMode();
        }
    }
}

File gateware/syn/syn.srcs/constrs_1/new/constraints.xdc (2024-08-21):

set_property PACKAGE_PIN Y19 [get_ports AFE_RST]
set_property PACKAGE_PIN W16 [get_ports AFE_SCK]
set_property PACKAGE_PIN Y17 [get_ports AFE_SDATA]
set_property PACKAGE_PIN Y18 [get_ports AFE_SL]
set_property PACKAGE_PIN T11 [get_ports AFE_SYNC]
set_property IOSTANDARD LVCMOS18 [get_ports AFE_RST]
set_property IOSTANDARD LVCMOS18 [get_ports AFE_SCK]
set_property IOSTANDARD LVCMOS18 [get_ports AFE_SDATA]
set_property IOSTANDARD LVCMOS18 [get_ports AFE_SL]
set_property IOSTANDARD LVCMOS18 [get_ports AFE_SYNC]

set_property PACKAGE_PIN U20 [get_ports {DSI_HS_DN[0]}]
set_property PACKAGE_PIN P20 [get_ports {DSI_HS_DN[1]}]
set_property PACKAGE_PIN W20 [get_ports DSI_HS_CN]
set_property IOSTANDARD DIFF_HSTL_I_18 [get_ports {DSI_HS_DP[0]}]
set_property IOSTANDARD DIFF_HSTL_I_18 [get_ports {DSI_HS_DN[0]}]
set_property IOSTANDARD DIFF_HSTL_I_18 [get_ports {DSI_HS_DP[1]}]
set_property IOSTANDARD DIFF_HSTL_I_18 [get_ports {DSI_HS_DN[1]}]
set_property IOSTANDARD DIFF_HSTL_I_18 [get_ports DSI_HS_CP]
set_property IOSTANDARD DIFF_HSTL_I_18 [get_ports DSI_HS_CN]

set_property SLEW FAST [get_ports {DSI_HS_DP[0]}]
set_property SLEW FAST [get_ports {DSI_HS_DN[0]}]
set_property SLEW FAST [get_ports {DSI_HS_DP[1]}]
set_property SLEW FAST [get_ports {DSI_HS_DN[1]}]
set_property SLEW FAST [get_ports DSI_HS_CP]
set_property SLEW FAST [get_ports DSI_HS_CN]

set_property PACKAGE_PIN W19 [get_ports DSI_LP_CN]
set_property PACKAGE_PIN U19 [get_ports DSI_LP_CP]
set_property PACKAGE_PIN N18 [get_ports {DSI_LP_DP[1]}]
set_property PACKAGE_PIN R19 [get_ports {DSI_LP_DP[0]}]
set_property PACKAGE_PIN T19 [get_ports {DSI_LP_DN[0]}]
set_property PACKAGE_PIN P19 [get_ports {DSI_LP_DN[1]}]
set_property IOSTANDARD LVCMOS18 [get_ports DSI_LP_CN]
set_property IOSTANDARD LVCMOS18 [get_ports DSI_LP_CP]
set_property IOSTANDARD LVCMOS18 [get_ports {DSI_LP_DP[1]}]
set_property IOSTANDARD LVCMOS18 [get_ports {DSI_LP_DP[0]}]
set_property IOSTANDARD LVCMOS18 [get_ports {DSI_LP_DN[0]}]
set_property IOSTANDARD LVCMOS18 [get_ports {DSI_LP_DN[1]}]


set_property PACKAGE_PIN C20 [get_ports TCON_V2]
set_property PACKAGE_PIN M18 [get_ports TCON_V1]
set_property PACKAGE_PIN A20 [get_ports TCON_V23]
set_property PACKAGE_PIN M15 [get_ports TCON_STROBE]
set_property PACKAGE_PIN H17 [get_ports TCON_RG]
set_property PACKAGE_PIN L16 [get_ports TCON_H2]
set_property PACKAGE_PIN L17 [get_ports TCON_H1]
set_property PACKAGE_PIN L19 [get_ports TCON_FDG]
set_property IOSTANDARD LVCMOS33 [get_ports TCON_FDG]
set_property IOSTANDARD LVCMOS33 [get_ports TCON_H1]
set_property IOSTANDARD LVCMOS33 [get_ports TCON_H2]
set_property IOSTANDARD LVCMOS33 [get_ports TCON_RG]
set_property IOSTANDARD LVCMOS33 [get_ports TCON_STROBE]
set_property IOSTANDARD LVCMOS33 [get_ports TCON_V1]
set_property IOSTANDARD LVCMOS33 [get_ports TCON_V2]
set_property IOSTANDARD LVCMOS33 [get_ports TCON_V23]
set_property SLEW FAST [get_ports TCON_RG]
set_property SLEW FAST [get_ports TCON_H2]
set_property SLEW FAST [get_ports TCON_H1]

set_property PACKAGE_PIN U14 [get_ports DVP_PCLK]
set_property PACKAGE_PIN Y16 [get_ports DVP_HSYNC]
set_property PACKAGE_PIN W15 [get_ports DVP_VSYNC]
set_property PACKAGE_PIN V16 [get_ports {DVP_D[0]}]
set_property PACKAGE_PIN U17 [get_ports {DVP_D[1]}]
set_property PACKAGE_PIN V12 [get_ports {DVP_D[2]}]
set_property PACKAGE_PIN T16 [get_ports {DVP_D[3]}]
set_property PACKAGE_PIN T12 [get_ports {DVP_D[4]}]
set_property PACKAGE_PIN T10 [get_ports {DVP_D[5]}]
set_property PACKAGE_PIN V13 [get_ports {DVP_D[6]}]
set_property PACKAGE_PIN W18 [get_ports {DVP_D[7]}]
set_property PACKAGE_PIN V17 [get_ports {DVP_D[8]}]
set_property PACKAGE_PIN W13 [get_ports {DVP_D[9]}]
set_property PACKAGE_PIN U12 [get_ports {DVP_D[10]}]
set_property PACKAGE_PIN U18 [get_ports {DVP_D[11]}]
set_property PACKAGE_PIN V18 [get_ports {DVP_D[12]}]
set_property PACKAGE_PIN Y14 [get_ports {DVP_D[13]}]
set_property IOSTANDARD LVCMOS18 [get_ports DVP_PCLK]
set_property IOSTANDARD LVCMOS18 [get_ports DVP_HSYNC]
set_property IOSTANDARD LVCMOS18 [get_ports DVP_VSYNC]
set_property IOSTANDARD LVCMOS18 [get_ports {DVP_D[0]}]
set_property IOSTANDARD LVCMOS18 [get_ports {DVP_D[1]}]
set_property IOSTANDARD LVCMOS18 [get_ports {DVP_D[2]}]
set_property IOSTANDARD LVCMOS18 [get_ports {DVP_D[3]}]
set_property IOSTANDARD LVCMOS18 [get_ports {DVP_D[4]}]
set_property IOSTANDARD LVCMOS18 [get_ports {DVP_D[5]}]
set_property IOSTANDARD LVCMOS18 [get_ports {DVP_D[6]}]
set_property IOSTANDARD LVCMOS18 [get_ports {DVP_D[7]}]
set_property IOSTANDARD LVCMOS18 [get_ports {DVP_D[8]}]
set_property IOSTANDARD LVCMOS18 [get_ports {DVP_D[9]}]
set_property IOSTANDARD LVCMOS18 [get_ports {DVP_D[10]}]
set_property IOSTANDARD LVCMOS18 [get_ports {DVP_D[11]}]
set_property IOSTANDARD LVCMOS18 [get_ports {DVP_D[12]}]
set_property IOSTANDARD LVCMOS18 [get_ports {DVP_D[13]}]

set_property PACKAGE_PIN B19 [get_ports VAB_PWM]
set_property IOSTANDARD LVCMOS33 [get_ports VAB_PWM]
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

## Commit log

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2017-10-26 Schematics: CCD H driver & AFE
    [CCD.SchDoc, Main.SchDoc, ProjectUshi.PrjPcb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]
2017-10-28 Schematics: Finish FPGA & CPU
    [CCD.SchDoc, CPU.SchDoc, FPGA.SchDoc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]
2017-11-21 Add power section in schematics; Fix complie
    [CCD.SchDoc, CPU.SchDoc, FPGA.SchDoc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]
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2017-12-12 The Prototype Rev. 1
    [CCD.SchDoc, CPU.SchDoc, FPGA.SchDoc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]
2017-12-15 Start designing FPGA code
    [LayerStack.ods, ProjectUshi.PrjPcb]
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2019-06-15 hw: migrate to kicad
    [Sitina.kicad_pcb, Sitina.sch, mcu.sch]
2019-06-16 hw: draw sch for sdram
    [Sitina.sch, mcu.sch, sdram.sch]
2019-06-28 hw: working on afe
    [Sitina.sch, afe.sch, mcu.sch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]
2020-08-31 pcb: align items to grid
    [Sitina.sch, afe.sch, mcu.sch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]
2020-09-01 pcb: working on ccd schematics
    [Sitina.sch, afe.sch, ccd.sch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]
2020-09-02 pcb: working on h-driver schematics
    [Sitina.sch, afe.sch, ccd.sch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]
2020-09-03 pcb: working on h-driver and v-driver
    [Sitina.sch, afe.sch, ccd.sch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]
2020-09-04 pcb: cleanup schematics; working on lcd
    [Sitina.sch, afe.sch, ccd.sch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]
2020-09-07 pcb: working on power supply
    [Sitina.sch, afe.sch, ccd.sch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]
2020-09-08 pcb: import footprints; finishing schematics
    [Sitina.sch, afe.sch, ccd.sch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]
2020-09-19 pcb: remove outdated capture board design
    [CCD.SchDoc, CPU.SchDoc, FPGA.SchDoc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]
2020-09-19 pcb: finishing overall design
    [Sitina.sch, afe.sch, ccd.sch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]
2020-09-25 pcb: divide into two boards
    [Sitina.kicad_pcb, Sitina.sch, afe.sch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]
2020-10-03 pcb: change footprint assignments
    [connector.sch, mcu.sch]
2020-10-09 pcb: start initial layouting
    [Sitina.kicad_pcb, afe.sch, connector.sch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]
2020-10-12 pcb: working on layout
    [Sitina.kicad_pcb, afe.sch, ccd.sch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]
2020-11-17 pcb: move stuff around, add more capacitors
    [Sitina.kicad_pcb, power.sch]
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2021-03-17 Migrate to KiCAD 6, capture board layout changes
    [Sitina.kicad_pcb, Sitina.kicad_sch, afe.kicad_sch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]
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2021-03-27 PBr0p2, CBr0p1, submitted for prototype production
    [Sitina.kicad_pcb, Sitina.kicad_sch, connector.kicad_sch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]
2021-04-01 Remove old KiCAD 5 files; Working on LCD driver and AFE driver; Restructure code
    [Sitina.sch, afe.sch, ccd.sch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]
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2021-04-07 Update License to match source code; test and fix USB, SEMC, and XIP on actual hardware
    [connector.kicad_sch, key.kicad_sch, lcd.kicad_sch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]
2021-04-11 pcb: bug fixes for PB r0.2
    [Sitina.kicad_sch, mcu.kicad_sch]
2021-04-21 Bug fixes and changes for PB r0p2
    [Sitina.kicad_pcb, Sitina.kicad_sch, cb_interface.kicad_sch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]
2021-08-15 pcb: switch to ad9978 wip
    [Sitina.kicad_pcb, Sitina.kicad_sch, afe.kicad_sch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]
2021-08-15 Routing capture board in progress
    [Sitina.kicad_pcb, Sitina.kicad_sch, afe.kicad_sch]
2021-12-17 pcb: finish routing PB 0.2
    [Sitina.kicad_pcb]
2021-12-18 pcb: PB r0p2 and CB r0p3 freeze
    [Sitina.kicad_pcb, Sitina.kicad_sch, afe.kicad_sch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]
2021-12-30 fw: fix semc/ initial ui/ fix lcd driver
    [main.c, ui.h]
2022-03-02 fw: working on afe driver; general fixes
    [main.c]
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2022-09-06 pcb: restructure, mb r0p5
    [Sitina.kicad_pcb, Sitina.kicad_sch, afe.kicad_sch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]
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2023-07-20 Update PCB files to rev 0.6 used for production
    [afe.kicad_sch, button.kicad_sch, ccd.kicad_sch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]
2023-07-21 Working towards pcb r0.7
    [afe.kicad_sch, ccd_driver.kicad_sch, ccd_power.kicad_sch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]
2023-07-21 Fix battery charging
    [power.kicad_sch]
2023-07-22 Use dedicated LDO for 1.5V rail
    [ccd_power.kicad_sch, power.kicad_sch]
2023-07-22 Fix vclock voltage shifter swing
    [ccd_driver.kicad_sch]
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2023-08-02 Update CCD V Driver, New Powertree Documentation Page
    [ccd_driver.kicad_sch, docs_powertree.kicad_sch, pcb.kicad_sch]
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2023-08-13 Fix image seq read
    [app_main.c]
2023-08-19 Split sensor board out
    [afe.kicad_sch, ccd.kicad_sch, ccd_driver.kicad_sch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]
2023-08-23 V Driver Patch Board
    [ccd.kicad_sch, ccd_driver_v.kicad_sch, pcb.kicad_pcb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]
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2023-10-23 New mainboard rev wip
    [afe.kicad_sch, ccd.kicad_sch, ccd_driver.kicad_sch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]
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2023-11-23 Update sensor/power board outline
    [PowerBoard.kicad_pcb, PowerBoard.kicad_sch, boost.kicad_sch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]
2023-11-24 Update power board outline
    [PowerBoard.kicad_pcb]
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2023-11-24 Update sensorboard outline and connector
    [afe.kicad_sch, connector.kicad_sch, pcb.kicad_pcb]
2023-11-25 Update sensorboard to include heatsink
    [afe.kicad_sch, connector.kicad_sch, pcb.kicad_pcb]
2023-11-25 PowerBoard Schematic, adding part values
    [PowerBoard.kicad_pcb, PowerBoard.kicad_sch, power_plan.kicad_sch]
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2023-11-26 Update powerboard 3d models
    [PowerBoard.kicad_pcb]
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2023-11-28 Power Board Routing WI{
    [PowerBoard.kicad_pcb, PowerBoard.kicad_sch, power_plan.kicad_sch]
2023-12-03 PowerBoard Alpha ver. Release
    [PowerBoard.kicad_pcb, PowerBoard.kicad_sch]
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2023-12-14 mb sent for manufacturing
    [connectors.kicad_sch, ddr.kicad_sch, pcb.kicad_pcb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]
2023-12-18 CCD Sensor Board WIP
    [PowerBoard.kicad_pcb, afe.kicad_sch, ccd.kicad_sch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]
2023-12-19 Sensor Board WIP, minor
    [ccd_driver.kicad_sch, ccd_driver_v.kicad_sch, pcb.kicad_pcb]
2023-12-19 Sensor Board Routing, First Pass Done, Ground Splitting TBD
    [connector.kicad_sch, pcb.kicad_pcb]
2023-12-20 Sensor Board Routing Done
    [afe.kicad_sch, ccd_driver.kicad_sch, ccd_driver_v.kicad_sch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]
2023-12-26 Uploading Sensorboard Production Files
    [afe.kicad_sch, ccd_driver.kicad_sch, ccd_power.kicad_sch]
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2024-03-14 Design grip flex, SB/IOB WIP
    [afe.kicad_sch, ccd.kicad_sch, ccd_driver.kicad_sch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]
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2024-05-10 USBC breakout board for JTAG, bug fix for grip flex cable
    [gripflex.kicad_pcb, gripflex.kicad_sch, usbc_breakout.kicad_pcb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]
2024-05-10 Additional fixes for grip flex
    [gripflex.kicad_pcb, gripflex.kicad_sch]
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2024-06-10 Adding CCD V Monitor Sample & Hold Schematic
    [ccd_sampler.kicad_sch]
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2024-07-26 Revert adding JTAG FSBL
    [cmake_lib_configs.txt]
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2024-07-28 Revert "Migrate to Vitis 2024.1"
    This reverts commit d05cfd6b809105f853f85ecff96089533746ac5a.
    [cmake_lib_configs.txt]
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2024-08-05 Add 2 rear buttons, add cutout for JTAG port, reduce tension spring thickness
    [dpad.SLDPRT, front.SLDPRT, gripflex.SLDPRT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]
2024-08-05 Add 2 more buttons on the grip flex
    [gripflex.kicad_pcb, gripflex.kicad_sch]
2024-08-05 Use header instead of pin for JTAG port on IOB
    [connectors.kicad_sch, pcb.kicad_pcb]
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2024-08-15 Fix wrong part number for H driver
    [ccd_driver.kicad_sch]
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2024-10-04 Reworking on power tree for SB
    [ccd_driver.kicad_sch, ccd_power.kicad_sch, connector.kicad_sch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]

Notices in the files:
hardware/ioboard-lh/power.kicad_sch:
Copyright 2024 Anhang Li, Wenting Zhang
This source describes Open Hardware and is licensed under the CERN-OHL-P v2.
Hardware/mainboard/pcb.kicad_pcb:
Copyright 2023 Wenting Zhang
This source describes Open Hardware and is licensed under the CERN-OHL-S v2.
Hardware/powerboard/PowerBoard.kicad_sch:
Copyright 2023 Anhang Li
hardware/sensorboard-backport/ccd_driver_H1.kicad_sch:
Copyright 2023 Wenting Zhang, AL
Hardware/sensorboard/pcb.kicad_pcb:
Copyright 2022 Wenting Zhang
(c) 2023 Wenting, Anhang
